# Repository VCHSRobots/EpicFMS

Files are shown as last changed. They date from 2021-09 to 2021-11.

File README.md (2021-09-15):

### The EPIC FMS 
**Sept 2021 EPIC Robotz**

This repository stores code that implements a field management system (FMS) for a simple game hosted by EPIC Robots. 

The game consists of robots shooting at various targets during a match. All targets have electronic sensors to detect hits.  The hits are counted at each target and then reported back to a central server, called the "EpicFMS server".  The EpicFMS server talleys the score and provides that information via MQTT and on a website that the EpicFMS hosts.  

The website that is hosted by EpciFMS server actually has two interfaces: the scoreboard and the game management interface.  The game management interface allows game administors to start, stop, reset the game.  Game parameters can also be set through the game management interface.

Finally, the EpicFMS server sends game status and commands back to the field elements -- mainly to control LEDs while the game is being played.

This repository contains all code and documentation for this system, including the code for the EpicFMS website, and the code for the electronics in the various targets. 

### Block Diagram
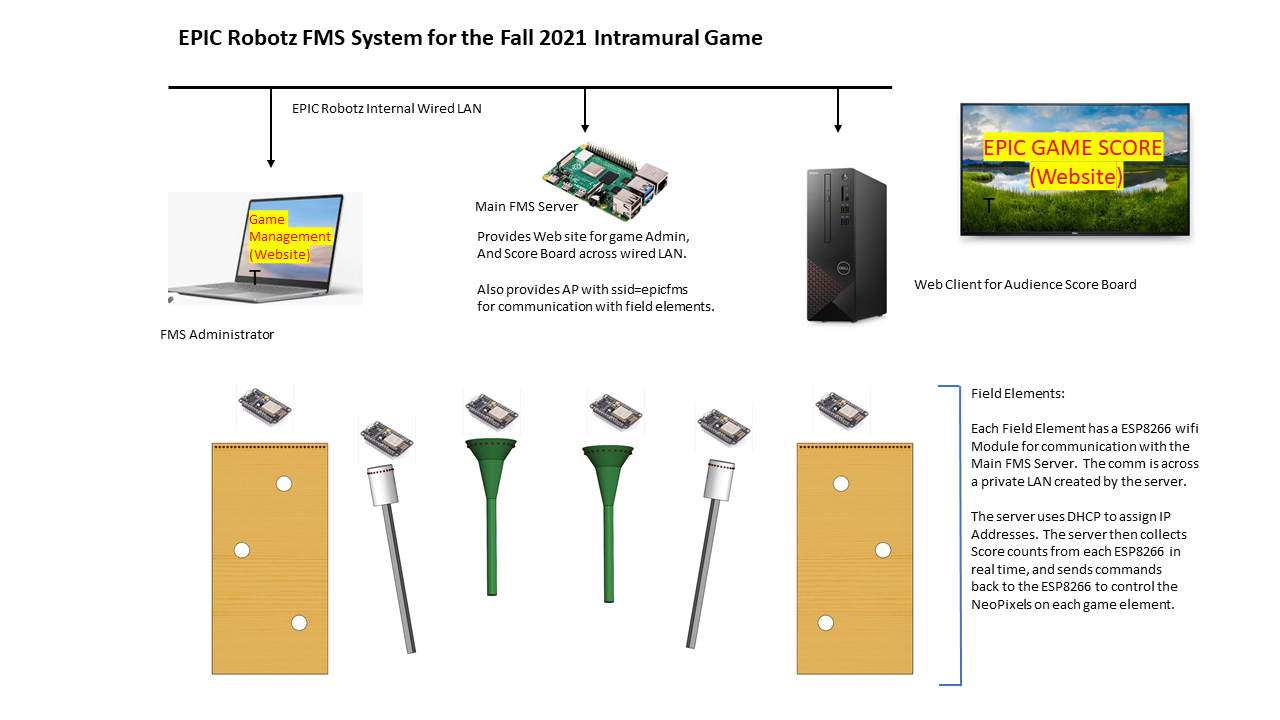
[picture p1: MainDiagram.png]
Cannot find it


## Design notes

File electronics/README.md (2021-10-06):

## Electronics for EpicFMS

This folder contains the data for the electronic components -- including
the custom PCB boards that were manufactured for the hit counters.

Note: Please see the MovingTargeUnit for the PCB -- This PCB is now
targeted to be used in all the targets.

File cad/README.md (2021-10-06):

## Epic FMS -- CAD Files

This repository stores the CAD files for the objects that have to do with electronics for the FMS.

Documentation and CAD files for the major game objects, on and off the field, are stored in EPIC's CAD Vault.

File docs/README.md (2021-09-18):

# EPIC FMS Documetation 

This folder contains notes and misc info that pertains to the EPIC FMS project.  

Some of this information is prepared in a power-point that is then 
converted to a PDF and the following PNG files:

### Wiring Diagram for Detection Test Circuit
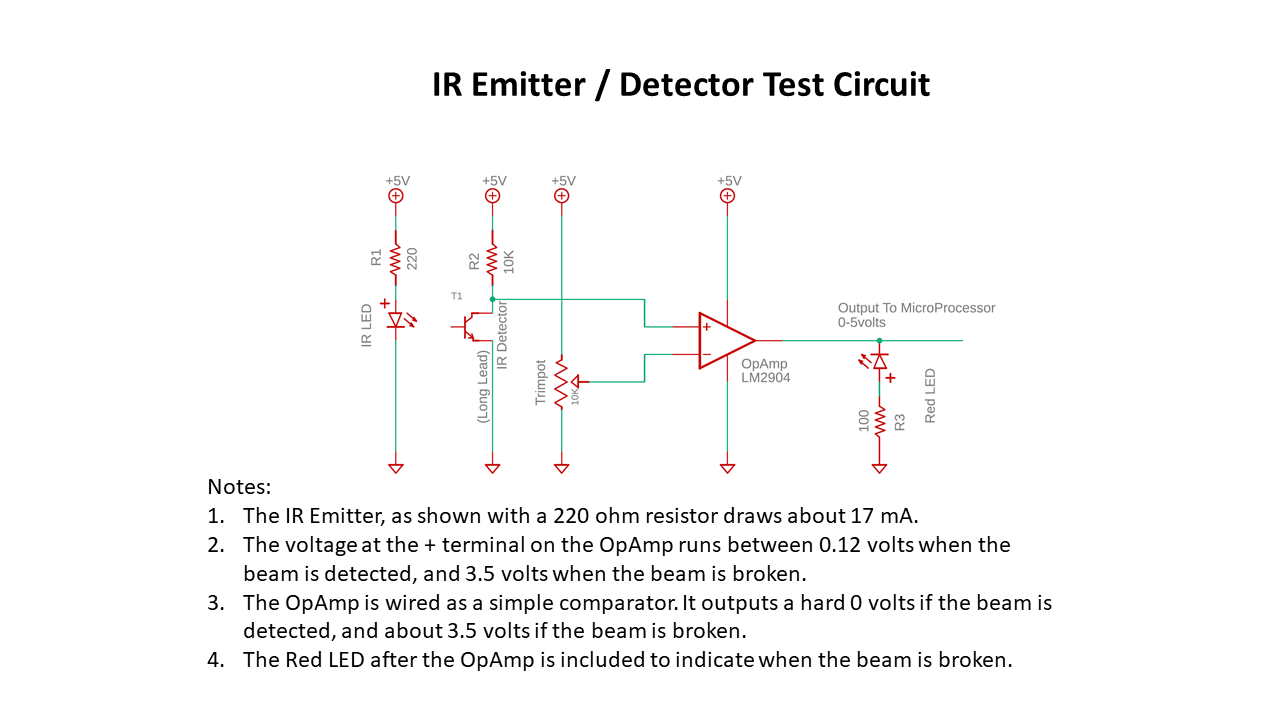
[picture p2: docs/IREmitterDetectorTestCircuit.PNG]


### Wiring for IR Emitter / Detector 
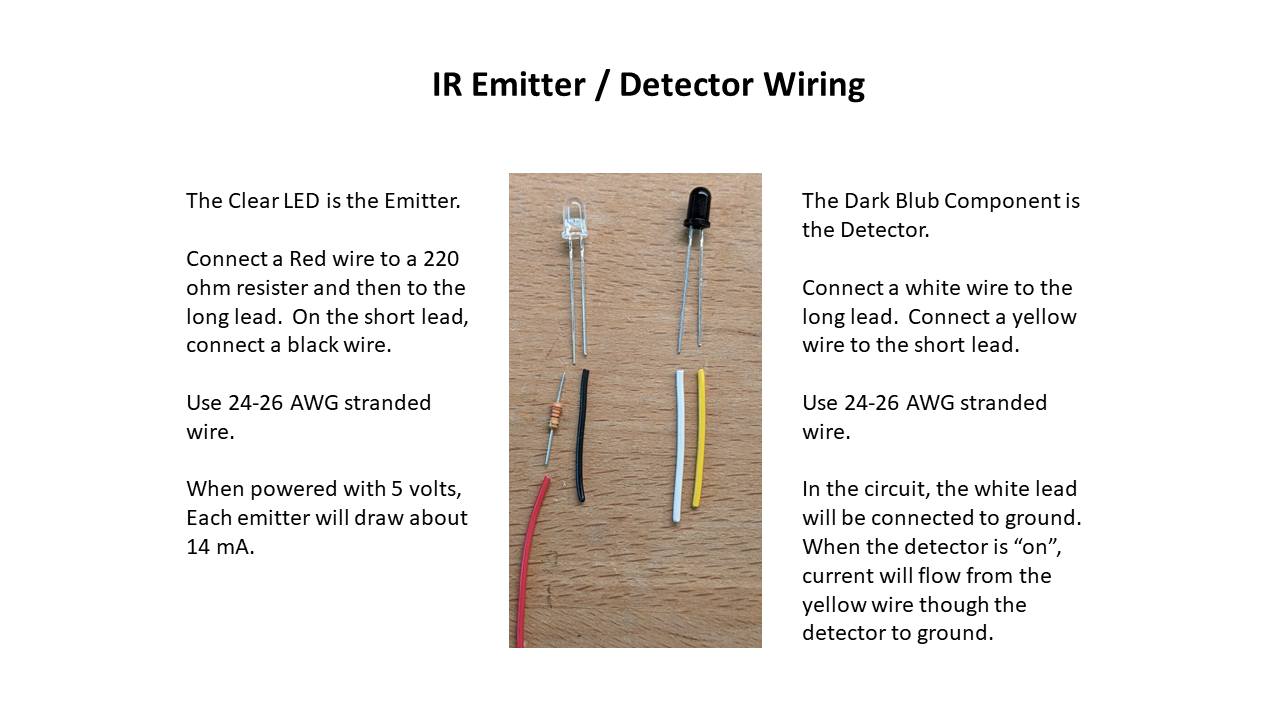
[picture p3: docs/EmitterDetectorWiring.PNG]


### Schematic For Hit Detector for Ring -- V1
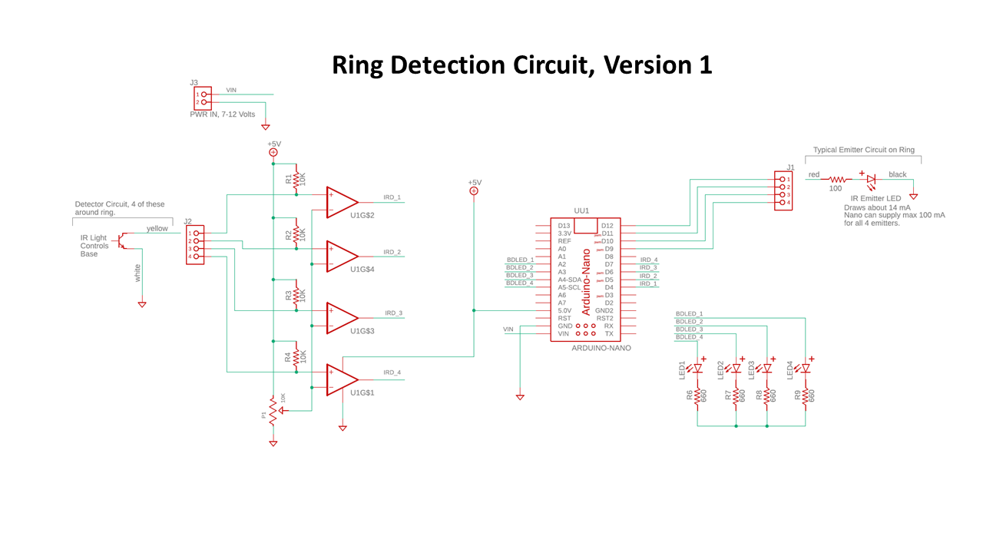
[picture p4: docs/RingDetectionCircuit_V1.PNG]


### Information Regarding Arduino Nano
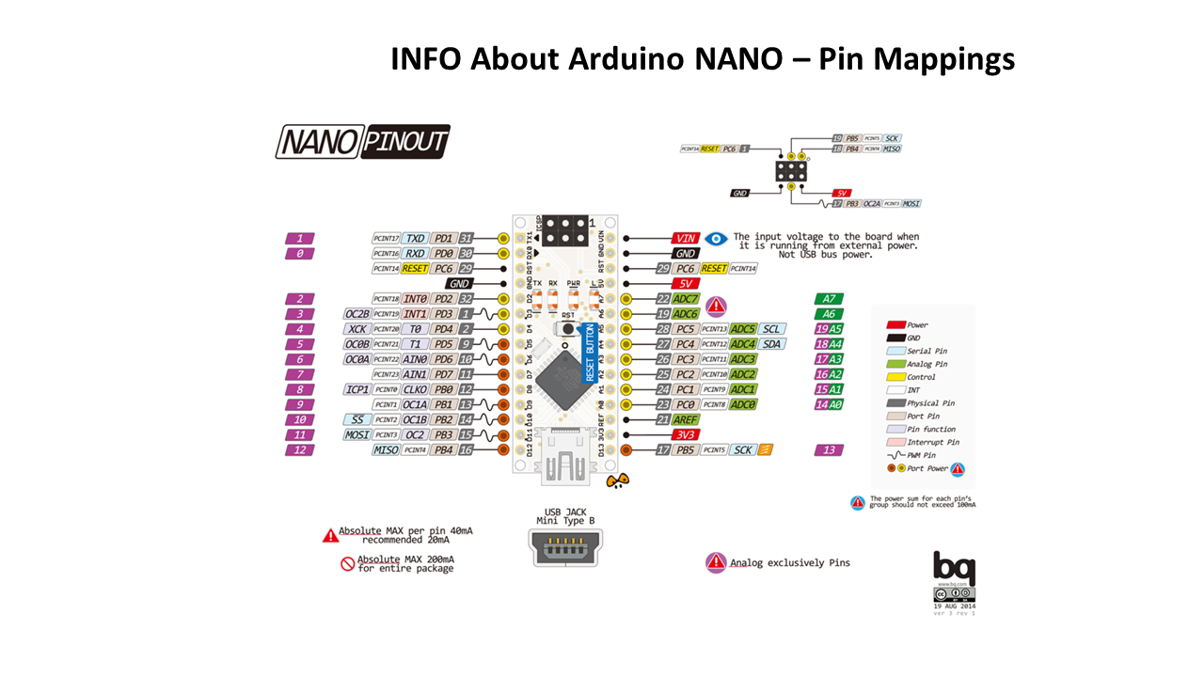
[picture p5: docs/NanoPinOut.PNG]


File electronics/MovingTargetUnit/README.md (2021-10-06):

### PCB for Moving Tareget Unit
**Oct 2021 EPIC Robotz**

As of 10/6/21, Two PCBs have been manufactured:

Verion 1:  Submitted for manufacturing on Friday, 9/24/21. Recived on 10/1/21.  This was based on V4 of the schematic.
Problems found:
1. Voltagle regulars overheat.  Since one of these powers sensors as well as neopixles, entire circult fails in about 2 minutes.
2. The outputs of the IR detectors are wired to pins that must be held in special conditions during startup -- this causes boot up problems.
3. The USB power flows back into the voltage regulators, causing confusion during developement.  Also, since USB power is tied directly
to input battery terminals, damage to a host computer might be possible during development.
4. The NEO pixels are driven directly from the ESP9266, at 3.3v.  It should be closer to 5v for reliable operation.

Verion 2: Submitted for manufacturing on Tuesday, 10/5/21.  This was based on V5 of the schematic. 
Hopefully, above problems fixed.

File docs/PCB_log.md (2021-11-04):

# EPIC Robotz -- EPIC FMS 
## PCB Log

This file contains notes about all the PCBs that have been built for the EPIC FMS.

There are two versions (as of 10/21/21) of the pcb board.  The schematics are V4 for the
first version, and V5 for the second.  A run of 15 pcbs for each was manufactured.  These
are referred to as V1 and V2 of the PCB.  (Confusing, I know. Sorry.)

V1 boards are really no good without lots of modifications.  V2 boards also needed modification,
as follows:

    * HITRST was cut from SD3 and rerouted to D0
    * IDR1 was cut from D10, and rerouted to SD3
    * IRD2 was cut from D9 and rerouted to D2, replacing NEO2.

So, for now on, a V2 board with the above mods is refered to as a V3 board.  So far all V2 boards have been converted, so we only have V1 boards and V3 boards.  Moreover, all V1 boards in use have been moded for use in the basket targets, so they are not really V1 boards.

10/29: Update on mods:  It has been found that HITRST to D0 causes problems. Since 
HITRST is a minor feature, this mod may not be found on many boards.

### Manufacturing Log

|SN | Date Made | BType | Okay |HS |Mods| Notes |How Used  |
|---|---|---|---|---|----| --- |---|
| A1 | Sept 21 | V1 | | | |Original, made by Mr.B | |
| A2 | Sept 21 | V1 |  No  | | |Made by Chris, cap blew up  | |
| A3 | Sept 21 | V1 | | | Y  |Many mods, For Basket | Retired  |
| 1 | 10/21/21  | V3 | | Y | |Runs pcb_test okay. | Mover |
| 2 | 10/21/21  | V3 |  No  | | |Runs pcb_test okay. | | 
| 3 | 10/21/21  | V3 | | | |Runs pcb_test okay. | Slider |
| 4 | 10/21/21  | V3 | | Y | |Runs pcb_test okay. | Mover |
| 5 | 10/21/21  | V3 | | | |Bad Mod, now okay. | Slider |
| 6 | 10/21/21  | V3 | | Y | |Runs pcb_test okay. | |
| 7 | 10/21/21  | V3 | | | |Works on Slider Ring. | Slider |
| 8 | 10/21/21  | V3 | | | |Works on Slider Ring. | Slider |
| 9 | 10/21/21  | V3 | | Y | |Works on Slider Ring. | Slider |
| 10 | 10/21/21  | V3 | | | |Works on Slider Ring. | |
| 11 | 10/21/21  | V3 |  No  | Y | |Fails test. Gets really hot.| |
| 12 | 10/21/21  | V3 |  No  | | |** See notes below | |
| 13 | 10/21/21  | V3 | | | |Fixed with Paul's Help | Slider |
| 14 | 10/21/21  | V3/B  | | | B  |Moded for Basket | Basket |
| 15 | 10/21/21  | V3/B  | | | B  |Fixed for Basket | Basket |

HS=HeatSink

### Address Assignements

|Board  |Name |Mac |IP Addr |How Used |
|---|---|---|---|---|
|PCB-A3 | |BC:FF:4D:2B:AD:82 |10.0.2.60  | |  
|PCB-01 |Mover-1 |30:83:98:B6:34:A1 |10.0.2.71  | Mover |  
|PCB-03 |Slider-1 |8C:CE:4E:E3:42:36 |10.0.2.73  | Slider  |  
|PCB-04 |Mover-2 |A8:48:FA:C0:81:A7 |10.0.2.74  | Mover |  
|PCB-05 |Slider-2 |30:83:98:B5:5D:FF |10.0.2.75  | Slider  |  
|PCB-07 |Slider-3 |BC:FF:4D:2B:A7:02 |10.0.2.77  | Slider  | 
|PCB-08 |Slider-6 |BC:FF:4D:2B:4B:14 |10.0.0.78  | Slider  |
|PCB-09 |Slider-5 |BC:FF:4D:2B:36:0B |10.0.2.79  | Slider  |  
|PCB-13 |Slider-4 |BC:FF:4D:2A:EB:3D |10.0.2.83  | Slider  |  
|PCB-14 |Basket-1 |BC:FF:4D:2B:AA:ED |10.0.2.84  | Basket  |  
|PCB-15 |Basket-2 |BC:FF:4D:2A:D6:E8 |10.0.2.85  | Basket  |  

IP addresses are fixed to MAC addresses and assigned by the LinkSys router,
via DHCP. The scheme is to tie address to Board SN, the V1 boards (A series) start 
at 10.0.0.60, and the V3 boards start at 10.0.2.71.  

The above scheme is not strickly necessary, but helps with the 
default assignments in the Epic FMS web server.

### Work Log

Work on Tuesday, 10/26:
PCB-2 was in first Ring, working great.  Working on second ring
and hooked it up to PCB-2. PCB-2 got really hot.  After cooling, one of
the IR beams will not work.  It still connects, but suppected burnout
on GPIO pins.

PCB-5 was also used on bad ring.  It will connect, but will not
work with the IR Beams.  Suppected burnout on GPIO pins.

Work on Thrusday, 10/28:
PCB-5 was misswired, a bad mod. Fixed the mod, and PCB-5 now okay.
Also, resodered PCB-13, works now.  And finshed PCB-12 with new ESP, and
something seems to be wrong... Set aside for debugging later.

Work on Monday, 11/1
PCB-12 was seemed okay at first, but then it wouldn't read one
of the ir beams on a ring.  Later, it will connect to a PC but
it won't accept an upload.

After more work with the test jig, I discovered that there is
cross-talk among the beams.  I tested PCB-6, PCB-8, PCB-9 and
PCB-10 on slider rings -- and they all work.  Before, PCB-8, PCB-9,
and PCB-10 failed the test on the test jig.  Now, I think, however, 
they failed becuase of HITRST -- see below. 

Work on Monday-Wednesday, 11/1-3
Built two more PCBs, 14 & 15. Discovered that HITRST, on SD3/G10
cannot be used reliable.  Casuses some sort of hardware watch dog
reset.

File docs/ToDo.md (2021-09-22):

# To Do List
    
## To Do list for Epic Robotz, Fall 2021 Intramural Game

    GI = Game Innovator
    
    Legend:  x = Item Finished, s = Item Started.

1. Overall Game Design
- 1a. [s] Codify the scoring in a document
- 1b. [ ] Create schedule for things like sliding doors, LED lights, countdown, etc
- 1c. [ ] Include schedule in game doc, and distribute to teams
- 1d. [ ] Design color schemes for targets, lines on floor, game panels
- 1e. [ ] Design LED flashing patterns for various game states
- 1f. [ ] Design algorithms to control assignments of auto path

2. EPIC FMS Server
- 2a. [x] Get Raspberry 4 Running as an AP device
- 2b. [ ] Install a web server on it.
- 2c. [s] Write code to test connections with game elements
- 2d. [ ] Decide on lang and tools to use
- 2e. [ ] Design, write game control program
- 2f. [ ] Design and implement the score board page
- 2g. [ ] Design and implement the admin interface
- 2h. [ ] Test 

3. Moving Target
- 3a. [x] Get initial design done
- 3b. [s] Finish electronic design
- 3c. [s] Initial coding and test
- 3d. [ ] Submit circuit board (PCB) for manufacturing
- 3e. [ ] Solidworks Parts/Design for team use
- 3f. [ ] CNC parts for team use
- 3g. [ ] Soldering, asm of final target
- 3h. [ ] Final coding and Testing

4. Sliding Target
- 4a. [x] Finish initial design done
- 4b. [ ] Design Control Box Mechanics
- 4c. [s] Design Control Box Electronics
- 4d. [ ] Assemble the electronics
- 4e. [ ] Paint the targets
- 4f. [ ] Install electrical components on targets
- 4g. [ ] Test

5. Basket Target
- 5a. [s] Finish initial design done
- 5b. [ ] Work with Paul on Motor controller for blender
- 5c. [s] Design Control Box Electronics for hit count
- 5d. [ ] Assemble the electronics
- 5e. [ ] Install electrical components on targets
- 5f. [ ] Test

6. 3D Printing
- 6a. [ ] Print 3 More Mobile Targets (2 days each)
- 6b. [ ] Print 6 More Sliding Door Targets (1 day each)
- 6c. [ ] Print yet-to-be designed parts for Basket Target Counters

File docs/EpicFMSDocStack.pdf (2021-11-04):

# EPIC FMS

## A Field Management System (FMS) for the Fall Game

## Epic Robotz Fall 2021

This stack contains useful info about various parts of EpicFMS.

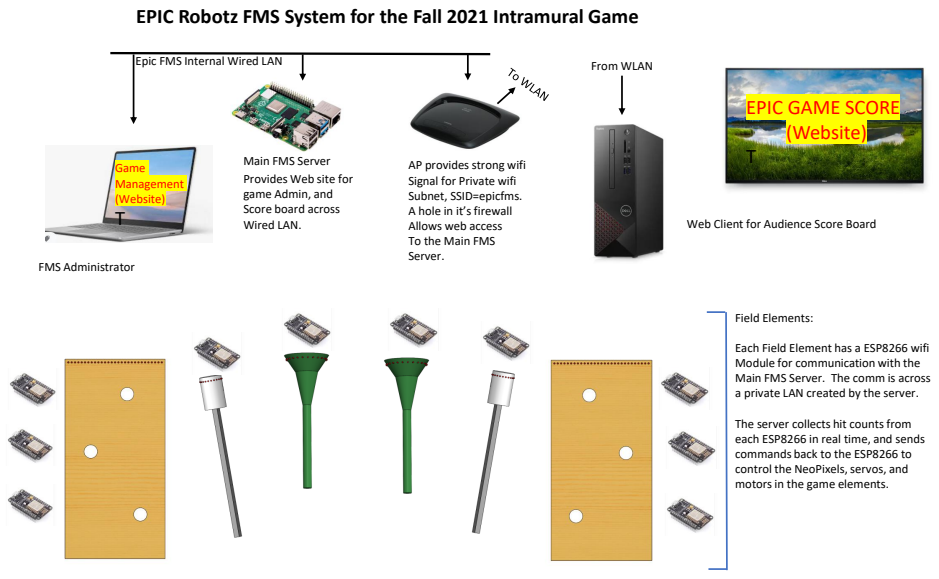
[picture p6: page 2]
FMS Administrator; Game Management (Website) T; Field Elements:; EPIC GAME SCORE (Website); From WLAN

EPIC Robotz FMS System for the Fall 2021 Intramural Game

Epic FMS Internal Wired LAN

Main FMS Server
Provides Web site for
game Admin, and
Score board across
Wired LAN.

AP provides strong wifi
Signal for Private wifi
Subnet, SSID=epicfms.
A hole in it’s firewall
Allows web access
To the Main FMS
Server.

Web Client for Audience Score Board

Each Field Element has a ESP8266 wifi
Module for communication with the
Main FMS Server. The comm is across
a private LAN created by the server.

The server collects hit counts from
each ESP8266 in real time, and sends
commands back to the ESP8266 to
control the NeoPixels, servos, and
motors in the game elements.

## Overview of Electronics for Field Elements

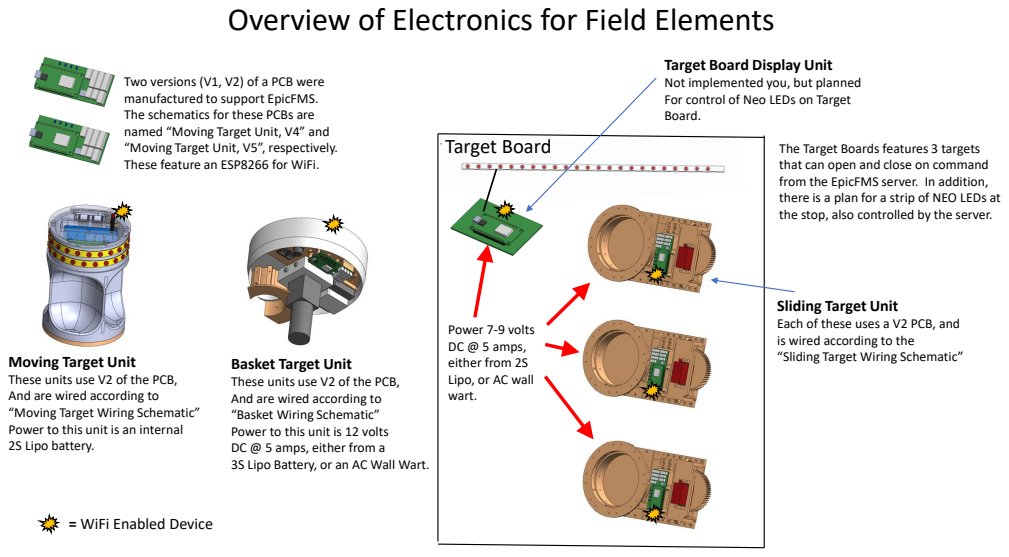
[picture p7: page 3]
Target Board; The Target Boards features 3 targets

Target Board Display Unit
Not implemented you, but planned
For control of Neo LEDs on Target
Board.

Two versions (V1, V2) of a PCB were
manufactured to support EpicFMS.
The schematics for these PCBs are
named “Moving Target Unit, V4” and
“Moving Target Unit, V5”, respectively.
These feature an ESP8266 for WiFi.

that can open and close on command
from the EpicFMS server. In addition,
there is a plan for a strip of NEO LEDs at
the stop, also controlled by the server.

Sliding Target Unit
Each of these uses a V2 PCB, and
is wired according to the
“Sliding Target Wiring Schematic”

Power 7-9 volts
DC @ 5 amps,
either from 2S
Lipo, or AC wall
wart.

Moving Target Unit
These units use V2 of the PCB,
And are wired according to
“Moving Target Wiring Schematic”
Power to this unit is an internal
2S Lipo battery.

Basket Target Unit
“Basket Wiring Schematic”
Power to this unit is 12 volts
DC @ 5 amps, either from a
3S Lipo Battery, or an AC Wall Wart.

= WiFi Enabled Device

## PCB Schematic, V1

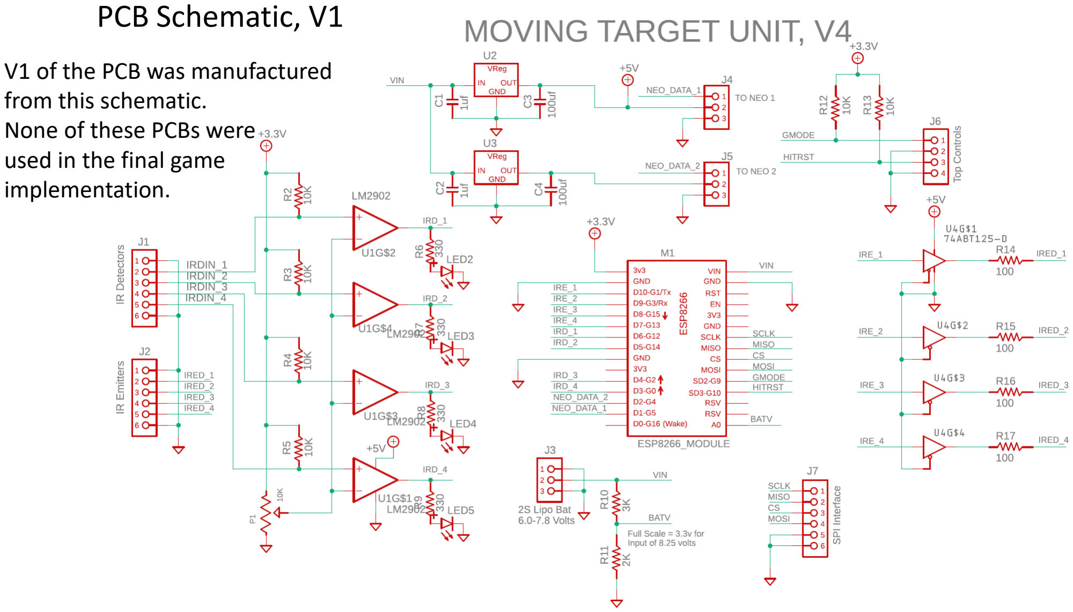
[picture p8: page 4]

V1 of the PCB was manufactured from this schematic.
None of these PCBs were
used in the final game
implementation.

## PCB Schematic, V2

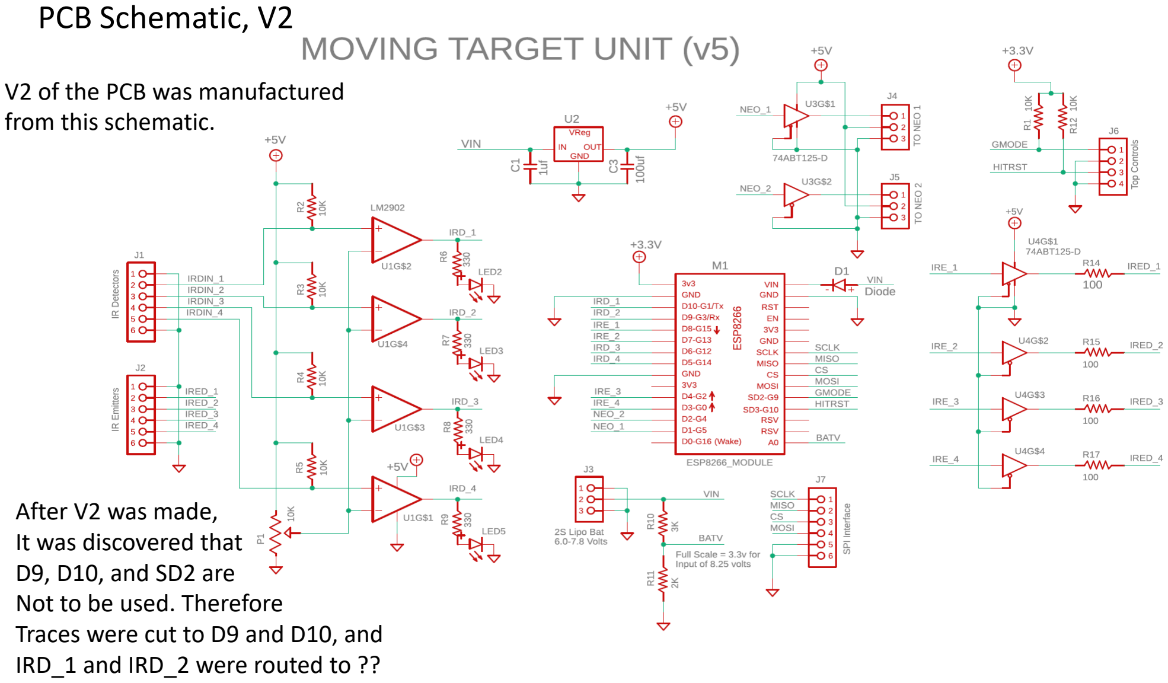
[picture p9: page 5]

V2 of the PCB was manufactured from this schematic.

After V2 was made,
It was discovered that
D9, D10, and SD2 are
Not to be used. Therefore
Traces were cut to D9 and D10, and IRD_1 and IRD_2 were routed to ??

## PCB Schematic, V3

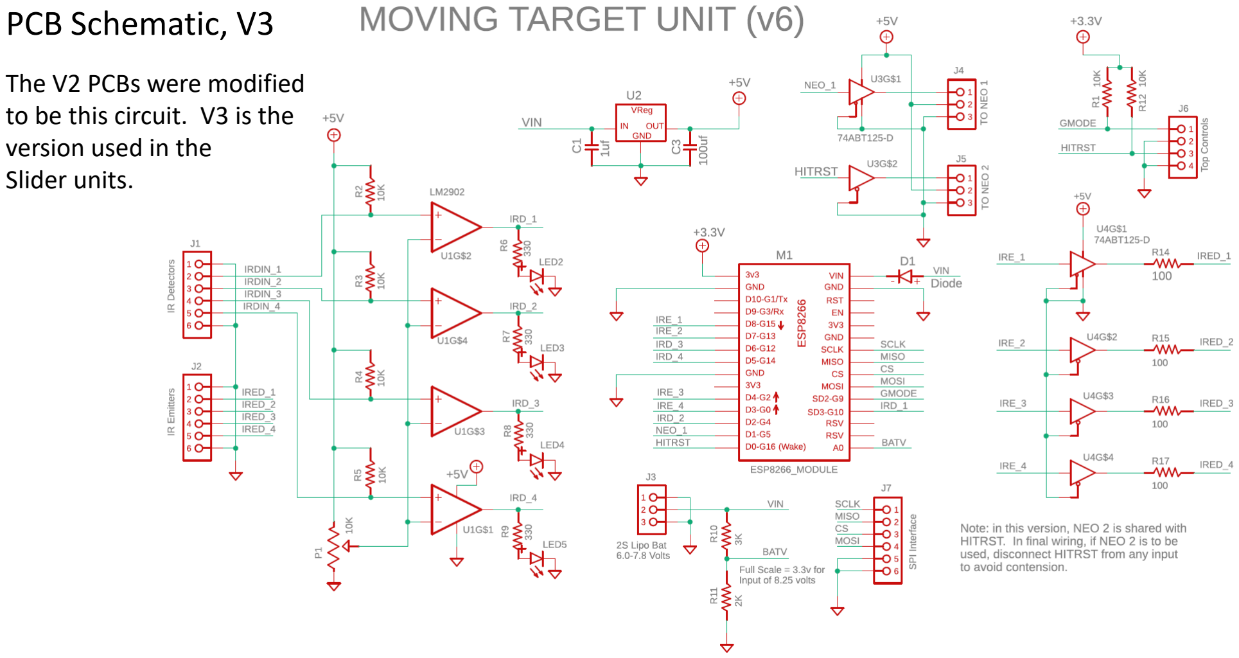
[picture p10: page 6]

The V2 PCBs were modified
to be this circuit. V3 is the version used in the
Slider units.

## Sliding Target Wiring Schematic

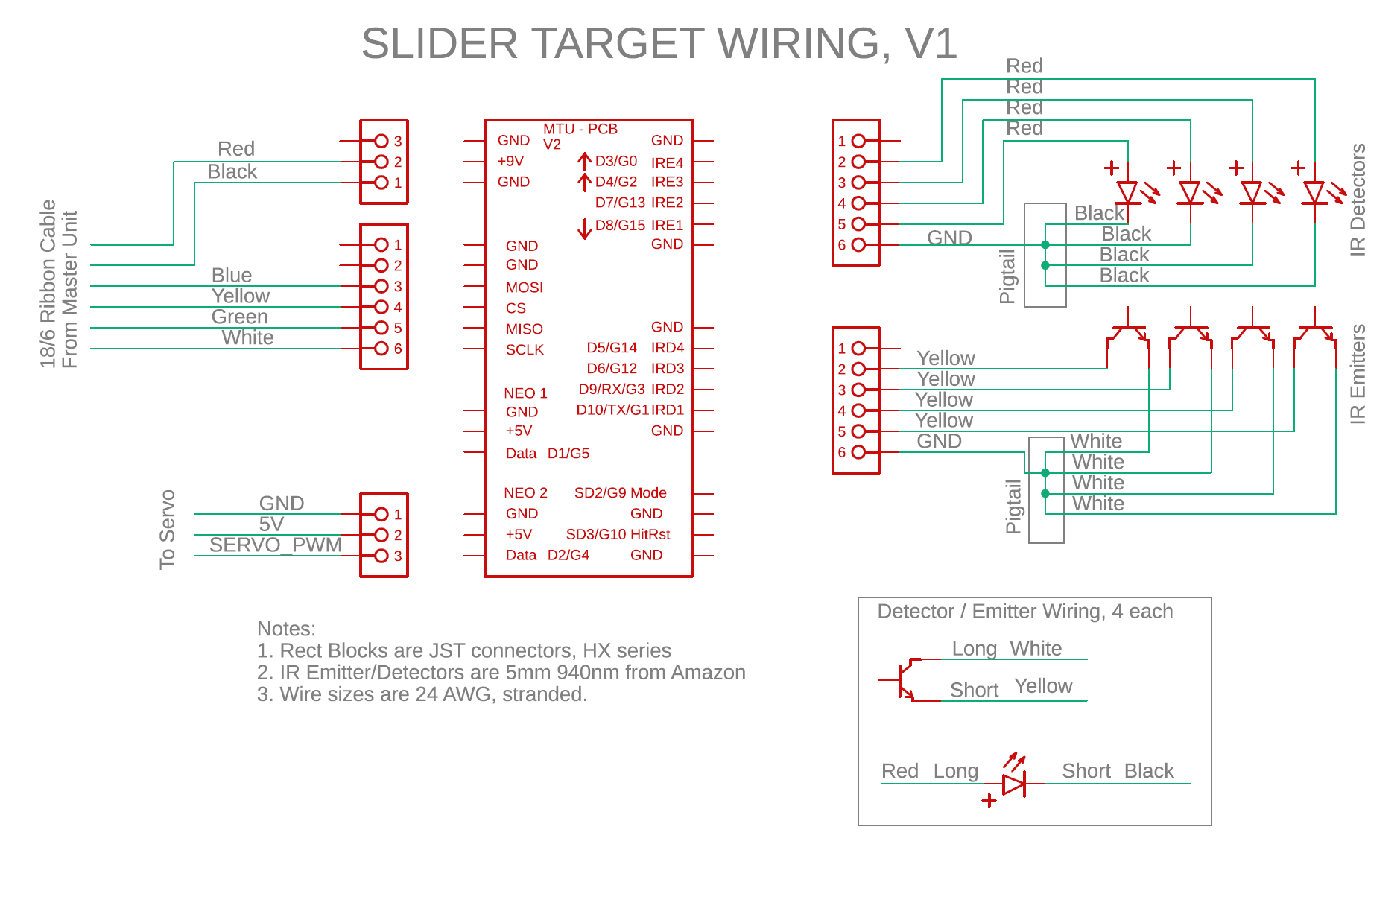
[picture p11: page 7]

## Basket Target Wiring, Version Based on V2/3 of PCB

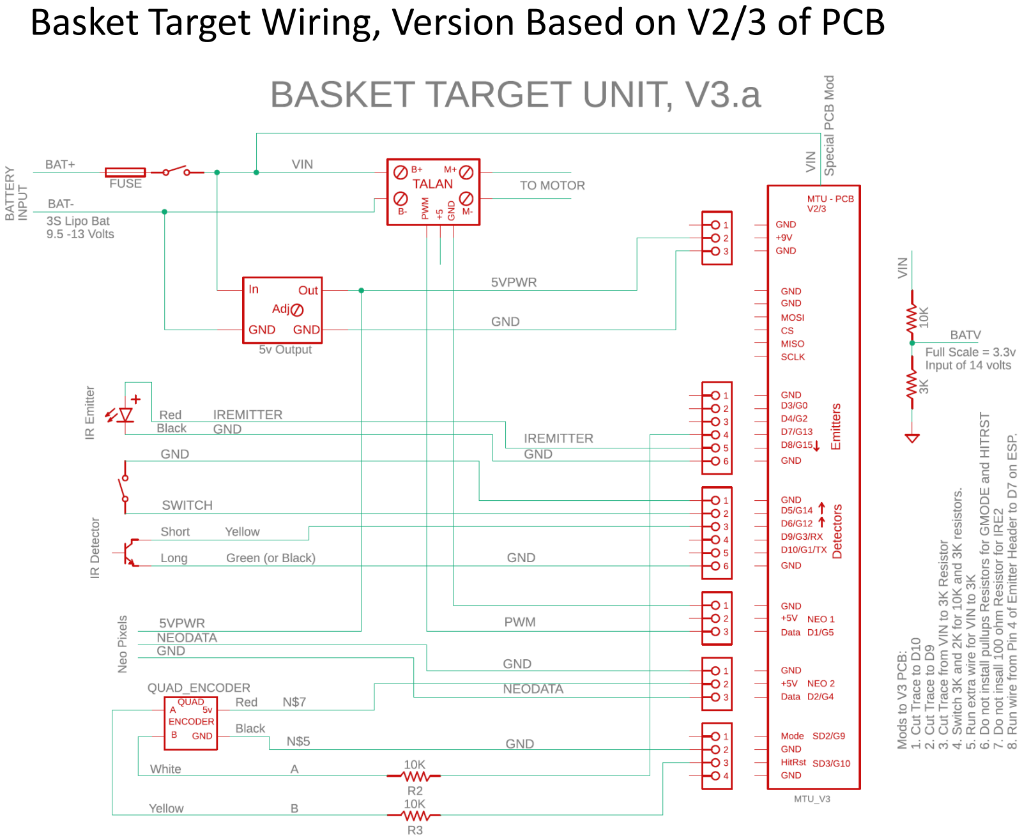
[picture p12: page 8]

Coming Soon, I Hope.

KNOWN Issues with the EPS8266

What as been learned through experimenting and study:

1. DO NOT USE the "D" numbers such as D0, D1, etc when specifying pins.
2. Pins seem to always be specified with the G numbers.
3. If you want a serial port to upload code and debug,
DO NOT USE D9 and D10 for any circuitry.
4. D0/G16 is connected to the on-board LED.
5. D0/G16 cannot be used for PWM or Interrupts!
6. D0/G16 cannot be used for NEO pixels!
7. D0/G16 can be used to turn on/off a simple LED
8. D1, D2, D3, D4, D5, D6, D7, D8, and SD3 all work with interrupts.
9. Startup problems and upload problems are likely if you use D0.
10. On some boards, using SD2 causes the hardware WDT to trigger,
so it cannot be used either.
11. On boot, MANY GPIO are asserted high: D0/G16, D9/G3/RX, SD3/G10, SD2/G9, D4/G2, D10/G1/TX. If any of these pins are forced low at boot time, there will be problems.
12. Also, on boot, D8 most NOT be pulled HIGH. D8 has a pulldown resister to hold it low at boot.

## MOVEING TARGET CIRCUIT BOARD CONNECTORS

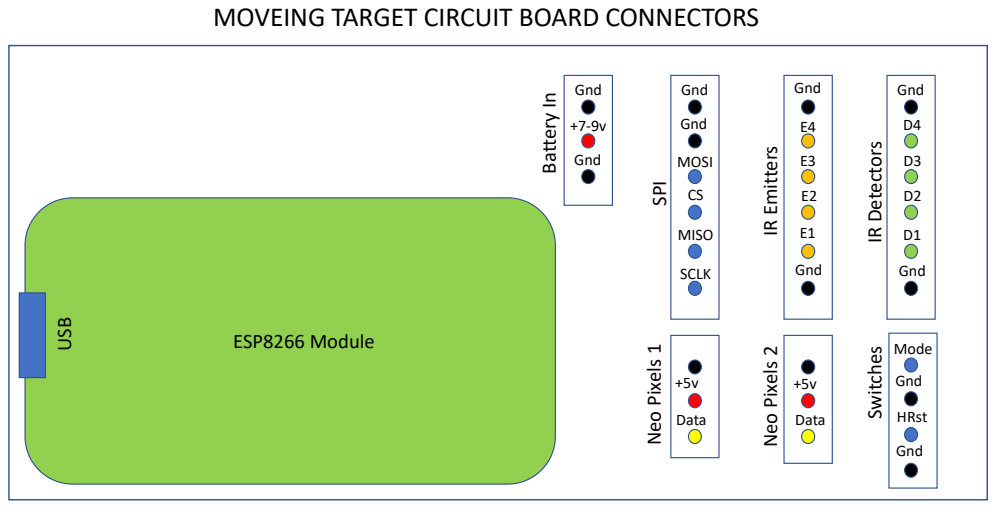
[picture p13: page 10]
Battery In; SPI; IR Emitters; Neo Pixels 1; Neo Pixels 2; Mode; Data; HRst; Gnd; MOSI; MISO; SCLK; USB; ESP8266 Module

IR Detectors Switches

# Wiring IR Emitter/Detectors

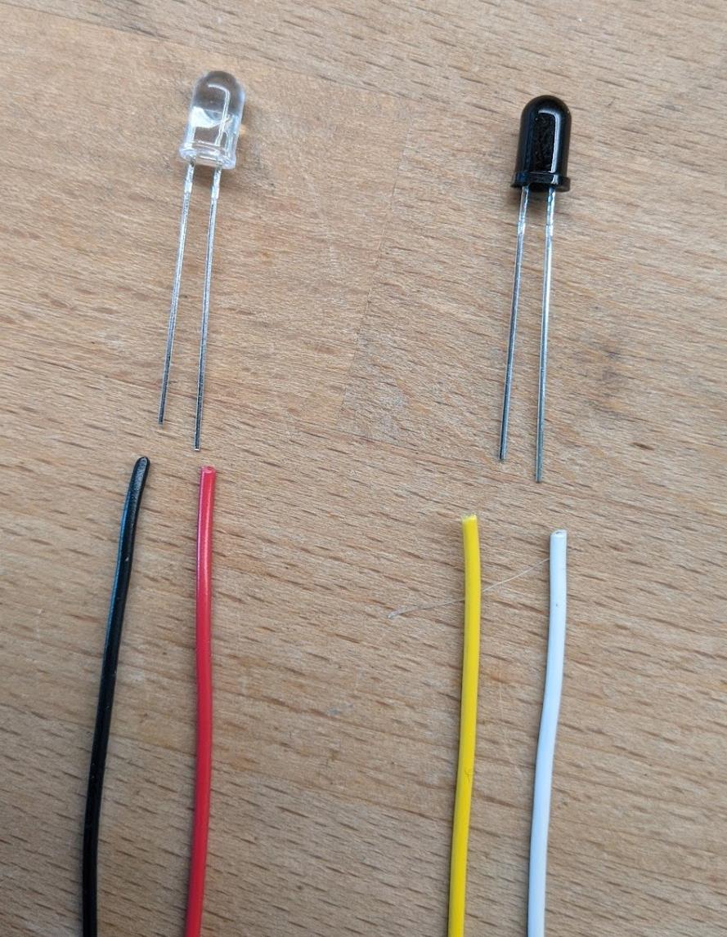
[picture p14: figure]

The CLEAR LED is the Emitter.

Our circuit sends about 17ma of current through this device.

The RED wire carries positive voltage and must be connected to the LONG lead.

The BLACK wire should be
connected to the SHORT lead.

Use 24-26 AWG stranded wire.

The Dark Component is the Detector.

When it detects IR light, it allows
current to flow between it’s leads, but in only one direction: from the short lead to the long lead.

The YELLOW wire is the positive side and Must be connected to the SHORT lead.

The WHITE wire is the negative side and Must be connected to the LONG lead.

Steps to Solder Wires to the IR Components

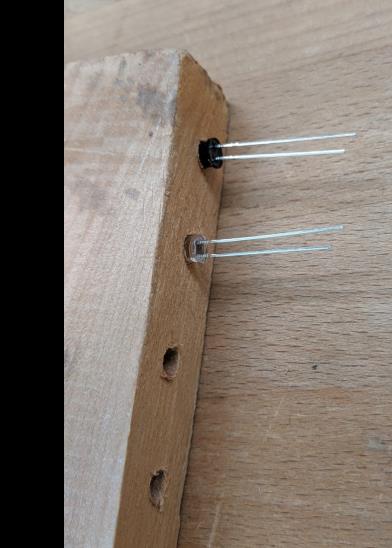
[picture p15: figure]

Start with the components in the soldering jig with the long leads nearer the top of the jig.

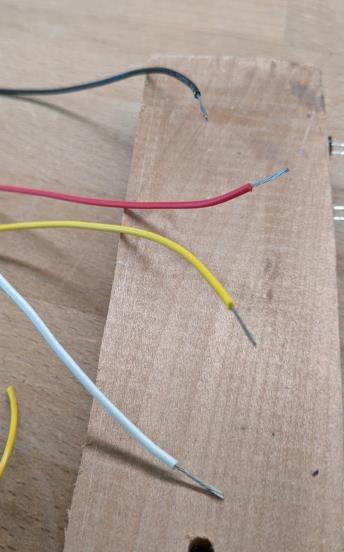
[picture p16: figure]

Strip about 0.5 inch of
insulation from each wire.

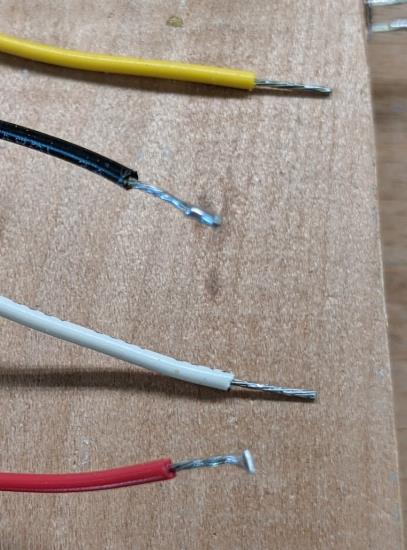
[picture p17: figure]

Tin all wires and leads.
Then trim the wires so that there is about 3/8 inch of conductor showing.

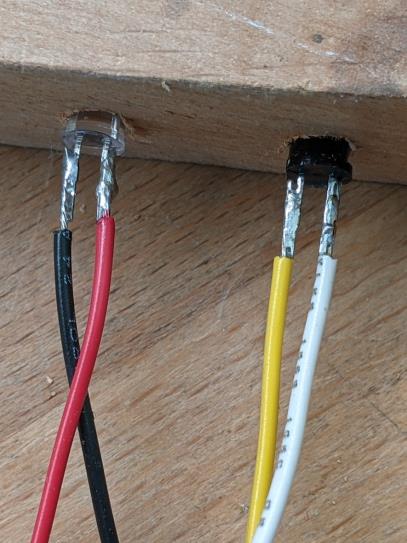
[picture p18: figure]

Do the same for the long
leads.

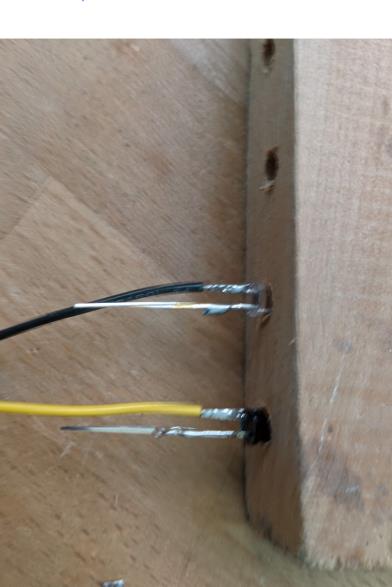
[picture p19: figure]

Cut the short leads to
about 3/8 inch. And then
use the parallel solder
technique to solder the
wires.

Parallel solder technique: After tinning both wire and lead, bring the wire along side of the lead (i.e., parallel to it), and then heat both with the soldering iron at the same time. Allow the solder to flow between the lead and the wire while holding the wire very steady. Remove the soldering iron while keeping the wire absolutely still until the solder cools.

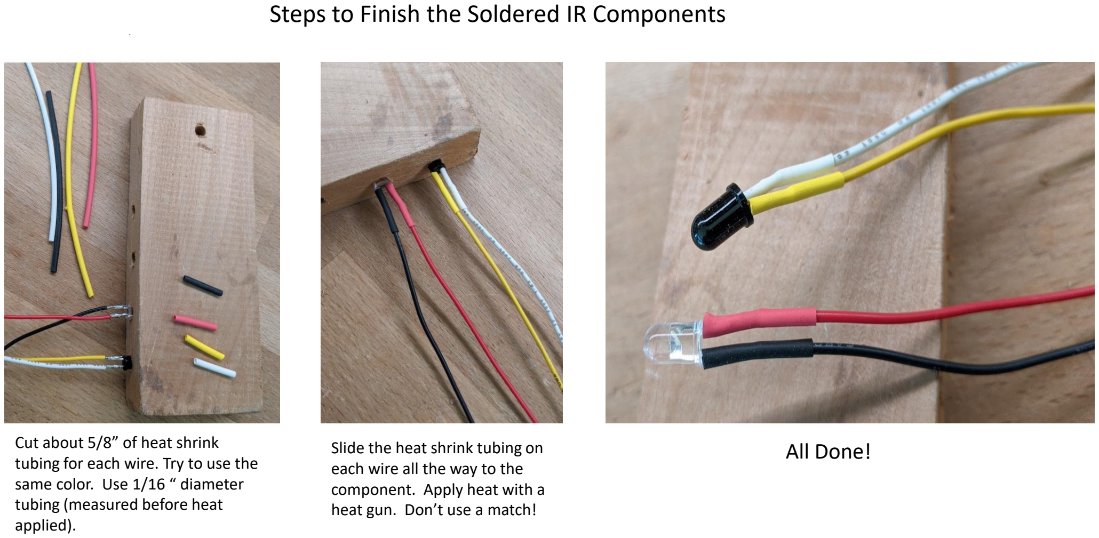
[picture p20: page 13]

Steps to Finish the Soldered IR Components

Cut about 5/8” of heat shrink tubing for each wire. Try to use the same color. Use 1/16 “ diameter tubing (measured before heat applied).

Slide the heat shrink tubing on each wire all the way to the component. Apply heat with a heat gun. Don’t use a match!

All Done!

## IR Emitter / Detector Test Circuit

Notes:

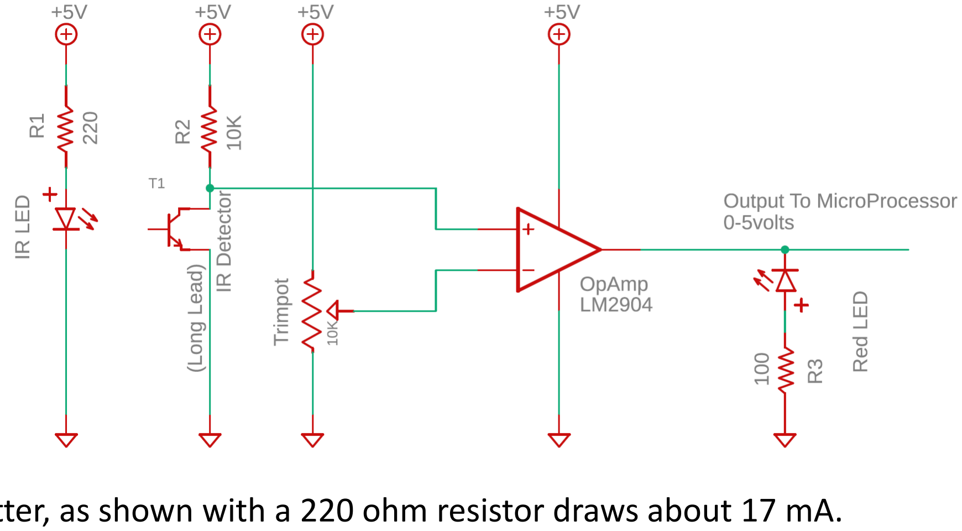
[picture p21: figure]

1. The IR Emitter, as shown with a 220 ohm resistor draws about 17 mA.
2. The voltage at the + terminal on the OpAmp runs between 0.12 volts when the beam is detected, and 3.5 volts when the beam is broken.
3. The OpAmp is wired as a simple comparator. It outputs a hard 0 volts if the beam is detected, and about 3.5 volts if the beam is broken.
4. The Red LED after the OpAmp is included to indicate when the beam is broken.

## IR Emitter / Detector Wiring

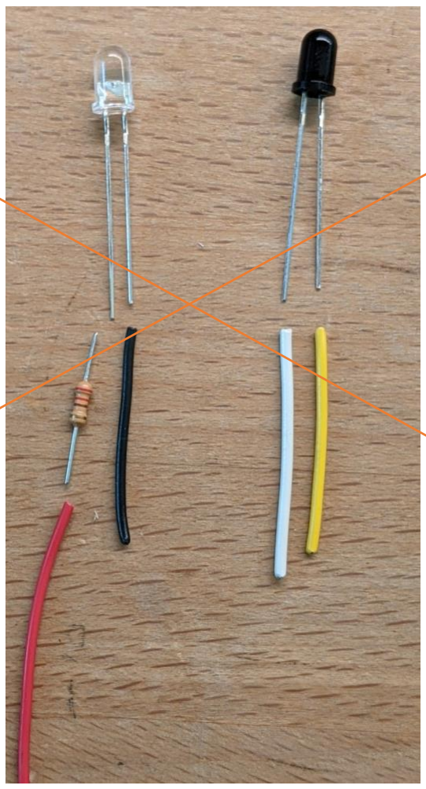
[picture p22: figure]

The Clear LED is the Emitter.

Connect a Red wire to a 220 ohm resister and then to the long lead. On the short lead, connect a black wire.

Use 24-26 AWG stranded
wire.

When powered with 5 volts, Each emitter will draw about 14 mA.

The Dark Blub Component is the Detector.

Connect a white wire to the long lead. Connect a yellow wire to the short lead.

Use 24-26 AWG stranded
wire.

In the circuit, the white lead will be connected to ground. When the detector is “on”, current will flow from the yellow wire though the
detector to ground.

OBSOLETE!! Design Changed.

## Ring Detection Circuit, Version 1

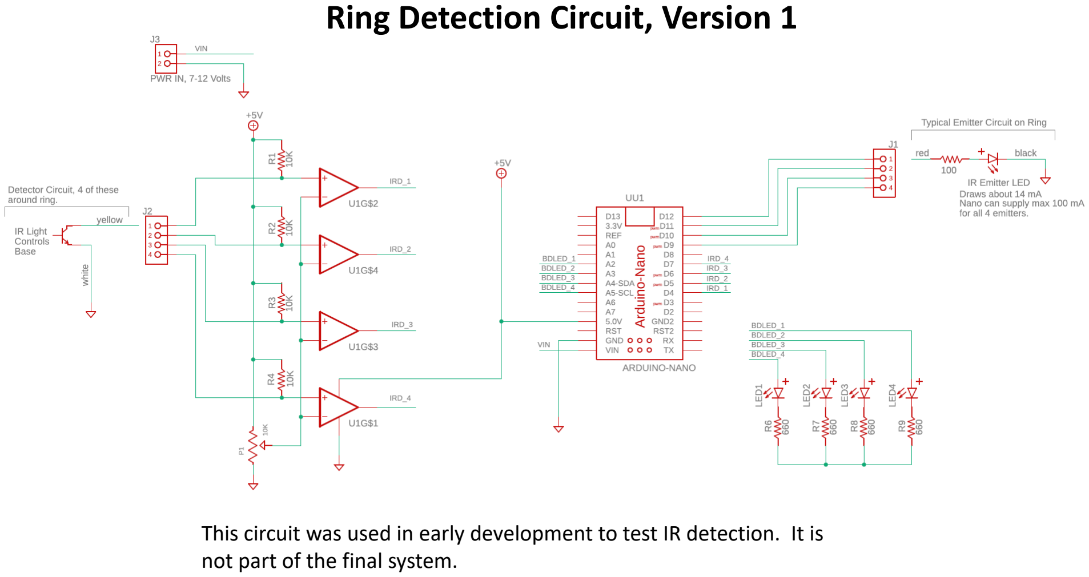
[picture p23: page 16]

This circuit was used in early development to test IR detection. It is not part of the final system.

## Pinout for nodeMCU

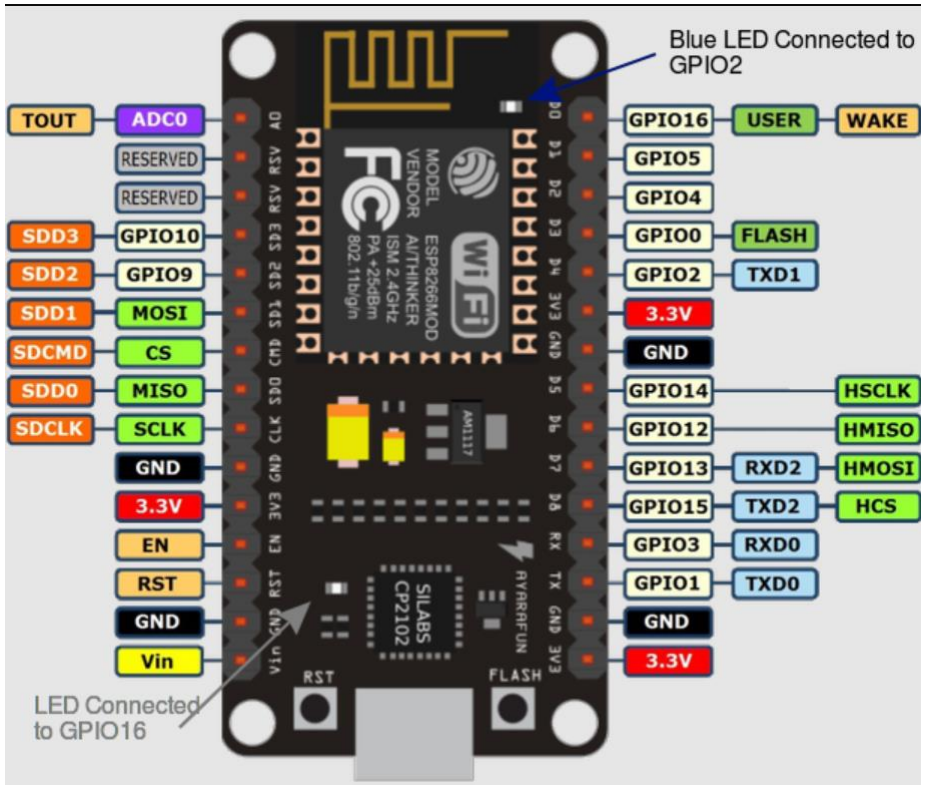
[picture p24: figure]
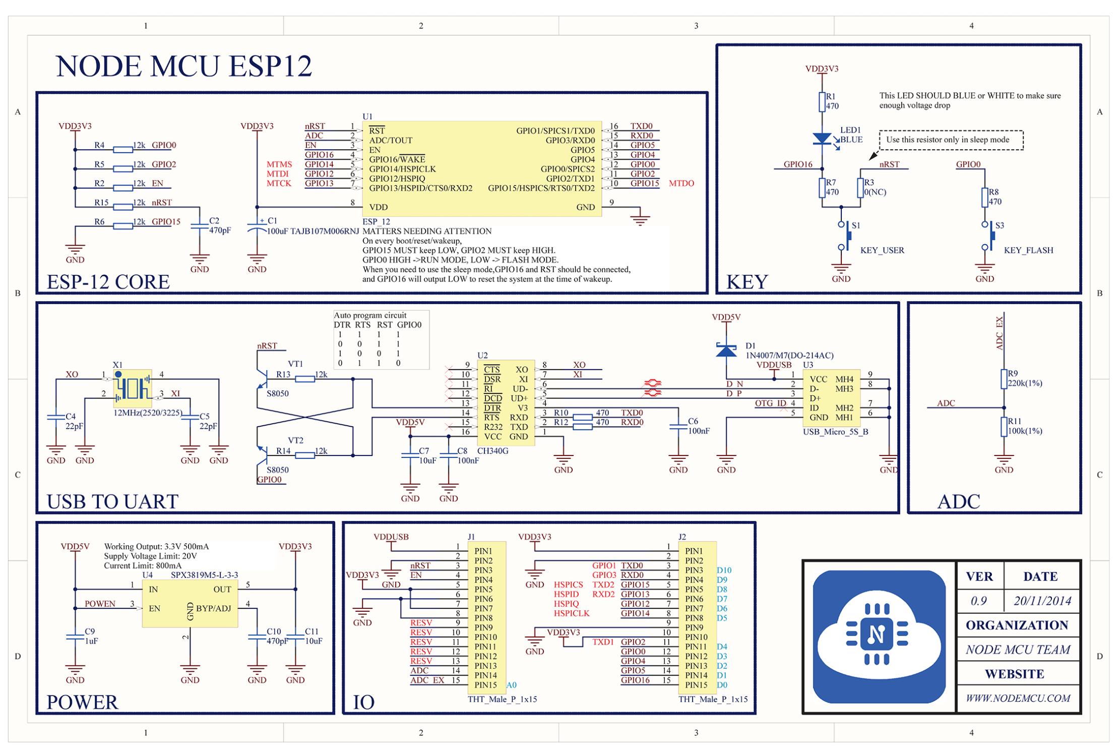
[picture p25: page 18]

## INFO About Arduino NANO – Pin Mappings


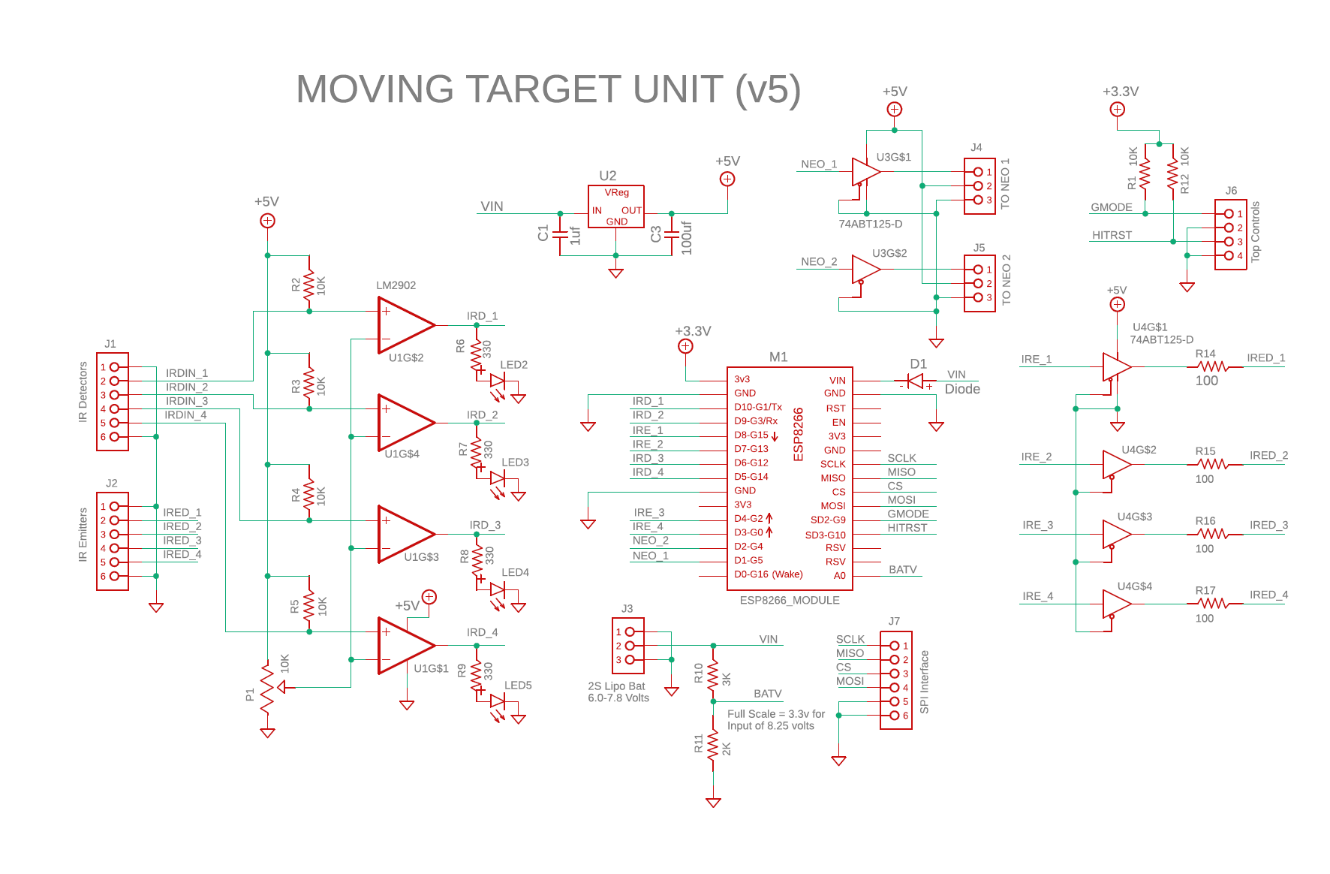
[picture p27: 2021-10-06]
electronics/MovingTargetUnit/v2/MovingTargetUnit_v5.png

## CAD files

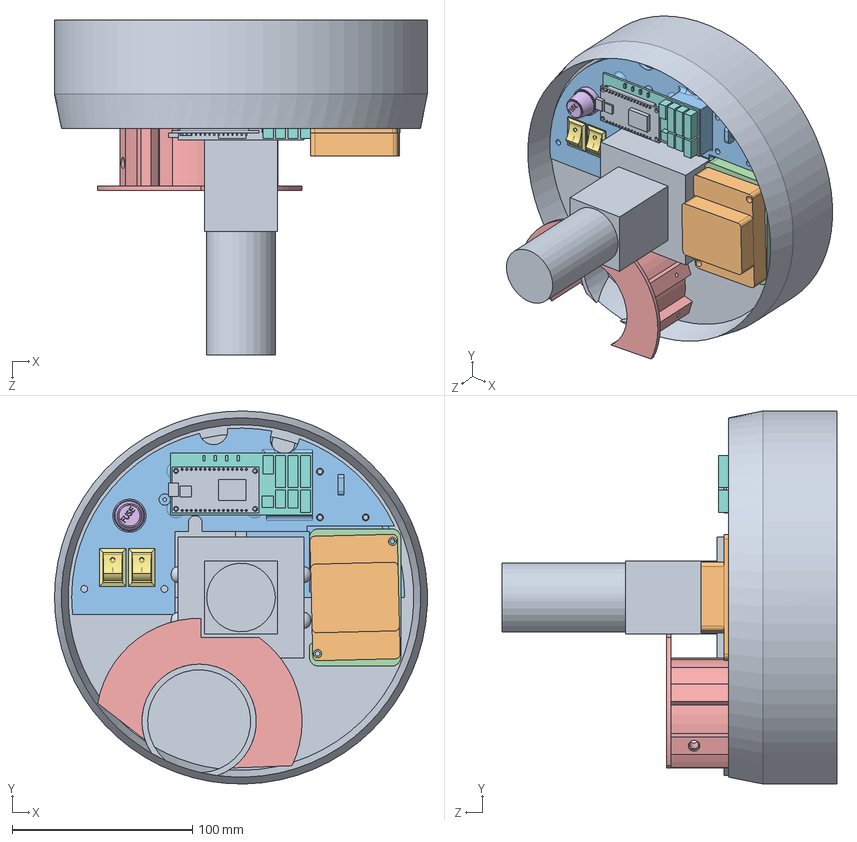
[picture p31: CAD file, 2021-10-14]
cad/BasketTarget/M21-HG-0001.SLDASM
207.0 x 207.0 x 186.1 mm
M21-HG-7001
M21-HG-7002
M21-HG-3001
M21-HG-3002
M21-HG-3003
PanelMountFuse
SmallRockerSwitch x 2
M21-GP-7001
ESP8266
DCtoDC_Convertor_2Amp

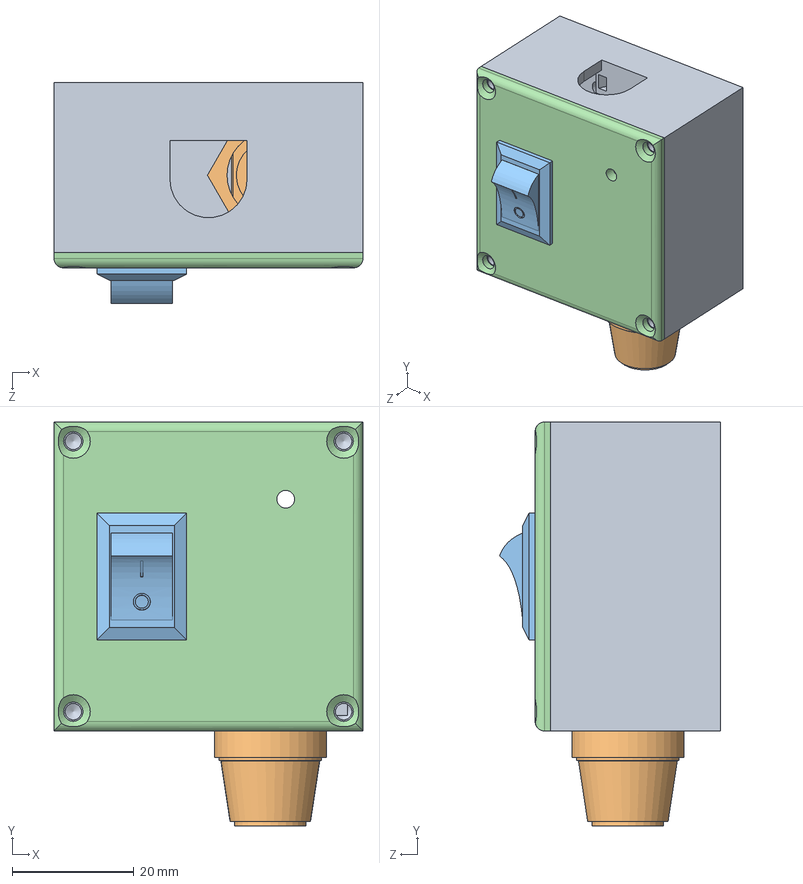
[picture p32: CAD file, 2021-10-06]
cad/FuseSwitchBox/M21-GP-0001.SLDASM
50.8 x 66.4 x 36.3 mm
M21-GP-3003
PanelMountFuse
SmallRockerSwitch
M21-GP-3004

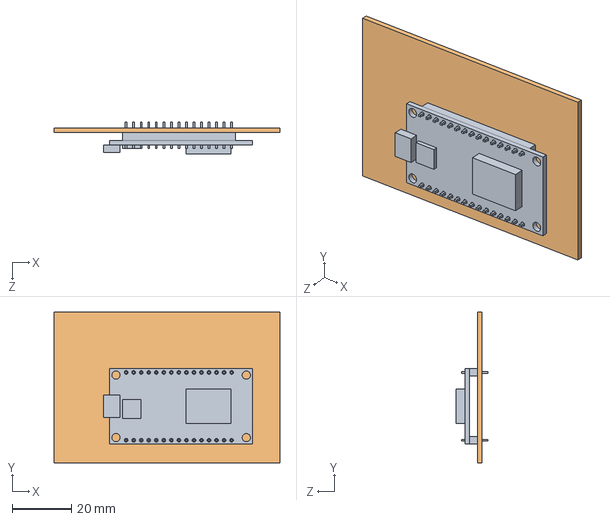
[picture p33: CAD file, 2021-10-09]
cad/PCB_Models/M21-GP-0003.SLDASM
76.2 x 50.8 x 10.7 mm
ESP8266
M21-GP-7002

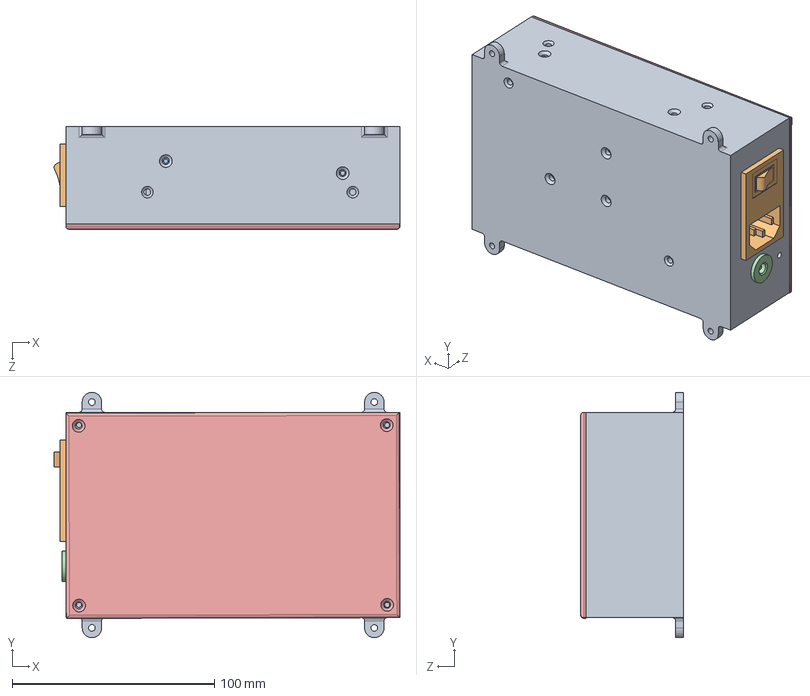
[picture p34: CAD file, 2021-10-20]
cad/PowerSupplyBox/M21-GP-0004.SLDASM
171.2 x 121.4 x 50.8 mm
M21-GP-3008
AC_PowerSocketWithSwitchAndFuse
AC_PowerSupply_Amazon_12v_5Amps
Jack_5p5mm_2p5mm
M21-GP-3009

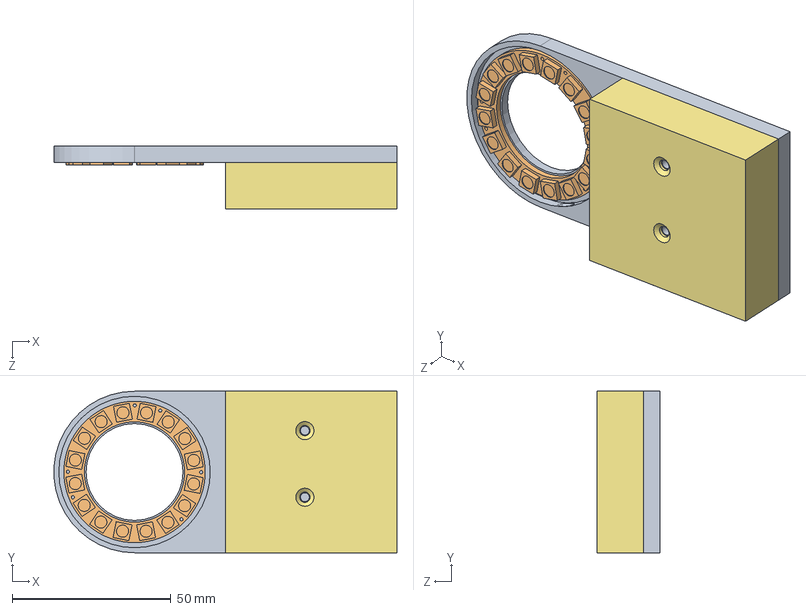
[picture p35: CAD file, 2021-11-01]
cad/CamerRingLEDs/M21-GP-0005.SLDASM
107.9 x 50.8 x 19.7 mm
M21-GP-3010
LED_Ring_16_Adafruit
Trinket_M0_Adafruit
DCtoDC_Convertor_2Amp
M21-GP-7004
JST_XH_3Pin_Jack

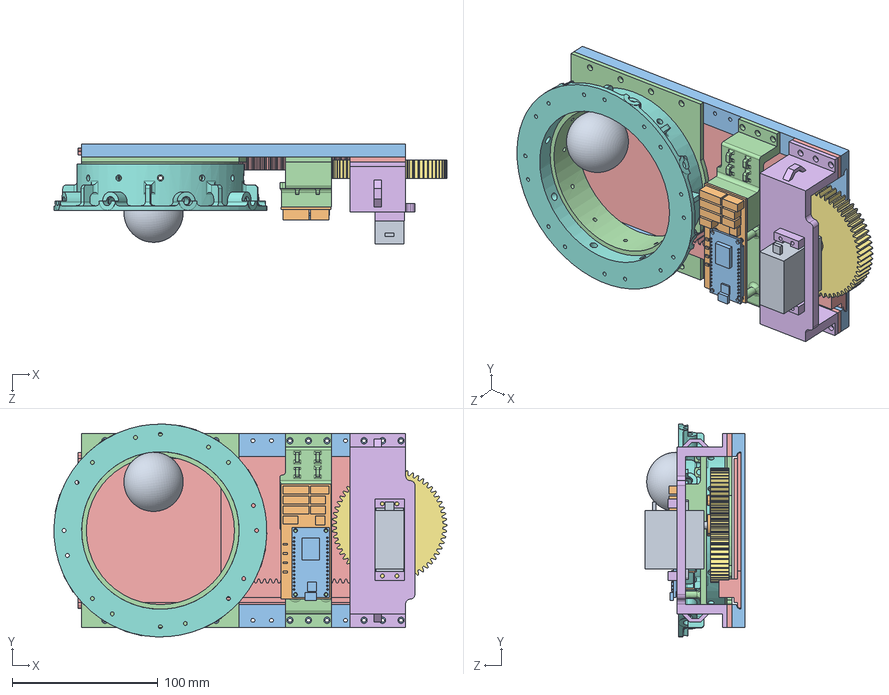
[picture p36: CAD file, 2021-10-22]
cad/DoorSliderTarget/M21-SL-0002.SLDASM
269.6 x 146.0 x 68.5 mm
ZOSKAY_25K_Servo
HornFor_ZOSKAY_25K_Servo
M21-SL-3002
M21-SL-3001
M21-SL-3003
M21-SL-3006
M21-SL-3007
M21-SL-3009
M21-GP-7001
ESP8266
M21-SL-3011
M21-SL-3012 x 2

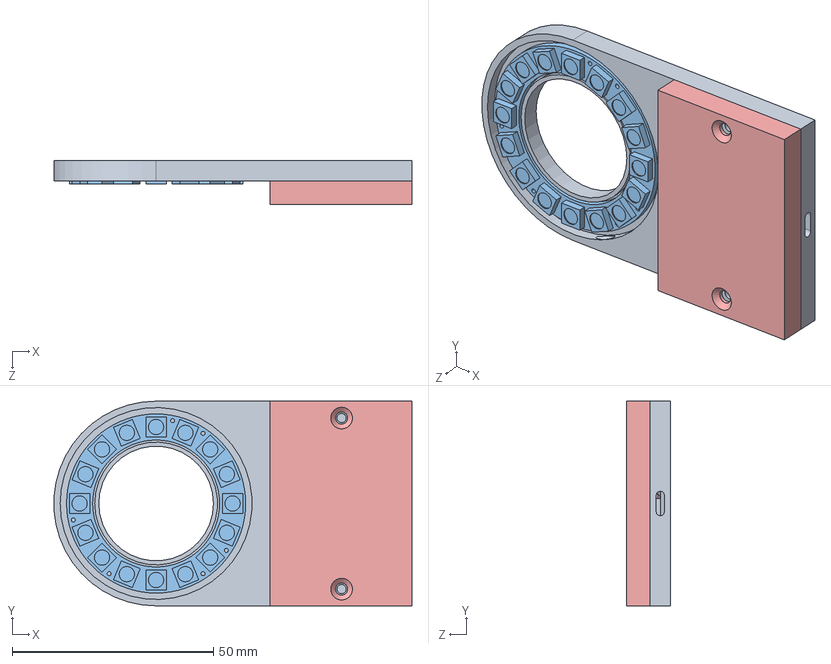
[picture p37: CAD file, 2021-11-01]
cad/CamerRingLEDs/M21-GP-0006.SLDASM
88.8 x 50.8 x 10.9 mm
M21-GP-3012
DCtoDC_Convertor_eBoot_Mini_MP1584EN_Amazon
LED_Ring_16_Adafruit
Trinket_M0_Adafruit
M21-GP-3013

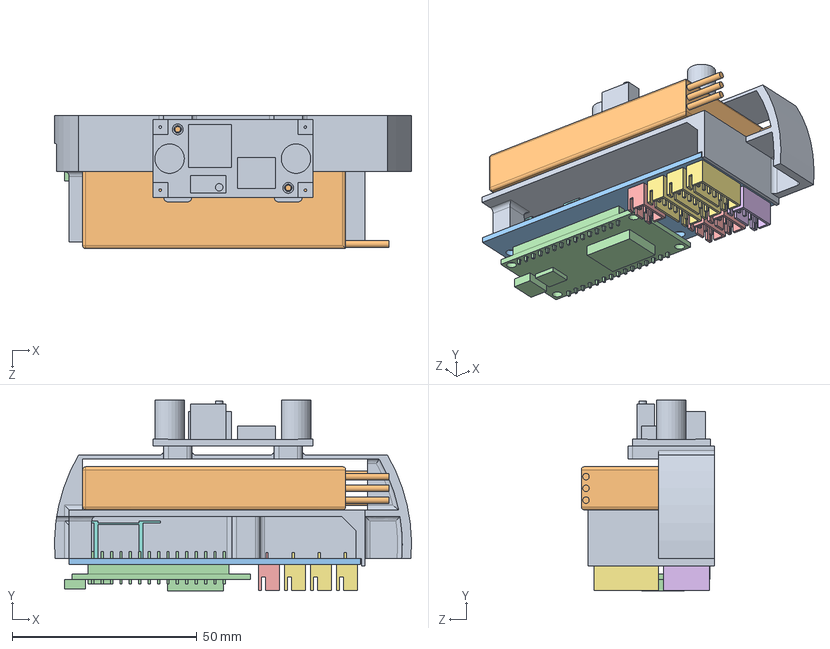
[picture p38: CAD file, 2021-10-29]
cad/MovingTarget/M21-MT-0006.SLDASM
96.5 x 51.5 x 36.1 mm
M21-MT-3009
LipoBattery_1000mah_2S_Amazon
M21-MT-7003
ESP8266
JST_XH_3Pin_Jack x 3
JST_XH_4Pin_Jack
JST_XH_6Pin_Jack x 3
HeatSink_Digitkey
DCtoDC_Convertor_2Amp

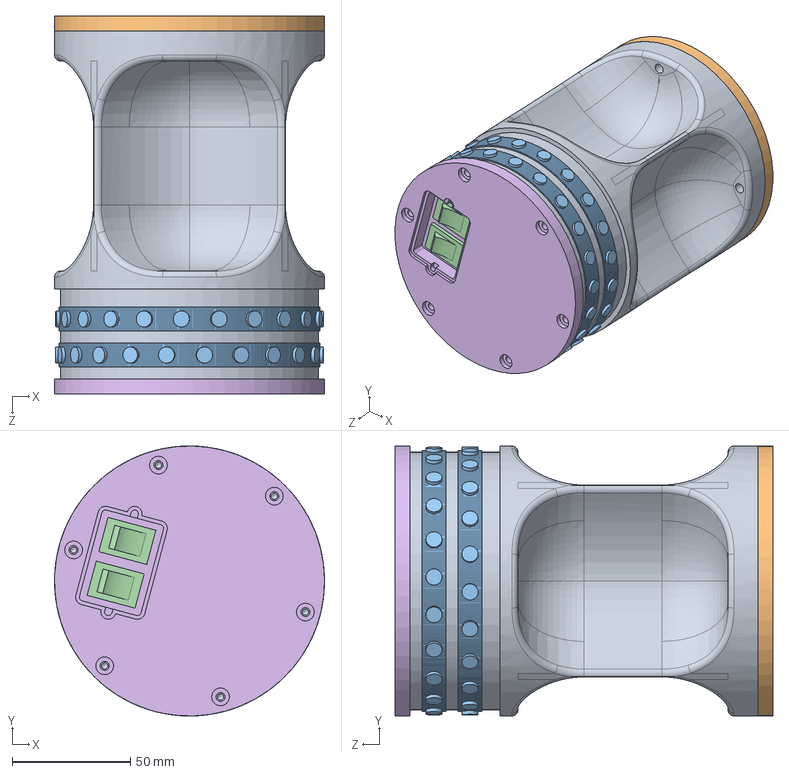
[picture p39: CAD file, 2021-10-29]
cad/MovingTarget/M21-MT-0004.SLDASM
114.4 x 114.3 x 160.0 mm
M21-MT-3002
M21-MT-3003
NeopixelRingSLDPRT x 2
RockerSwitch x 2
M21-MT-3009
LipoBattery_1000mah_2S_Amazon
M21-MT-7003
ESP8266
JST_XH_3Pin_Jack x 3
JST_XH_4Pin_Jack
JST_XH_6Pin_Jack x 3
HeatSink_Digitkey
DCtoDC_Convertor_2Amp
M21-MT-3010

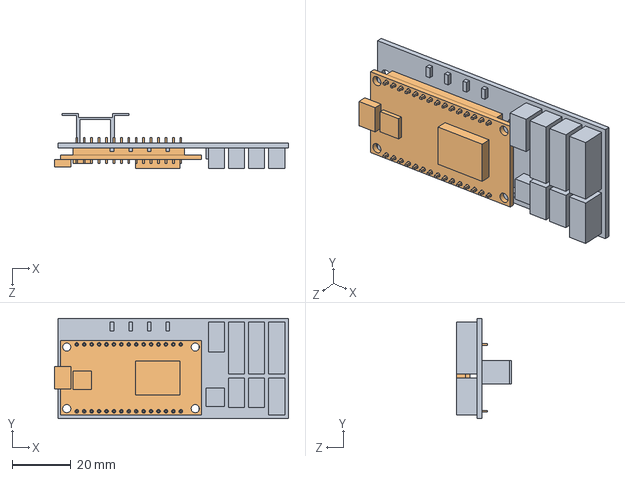
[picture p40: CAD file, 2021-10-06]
cad/PCB_Models/M21-GP-0002.SLDASM
80.0 x 34.3 x 18.9 mm
M21-GP-7001
ESP8266

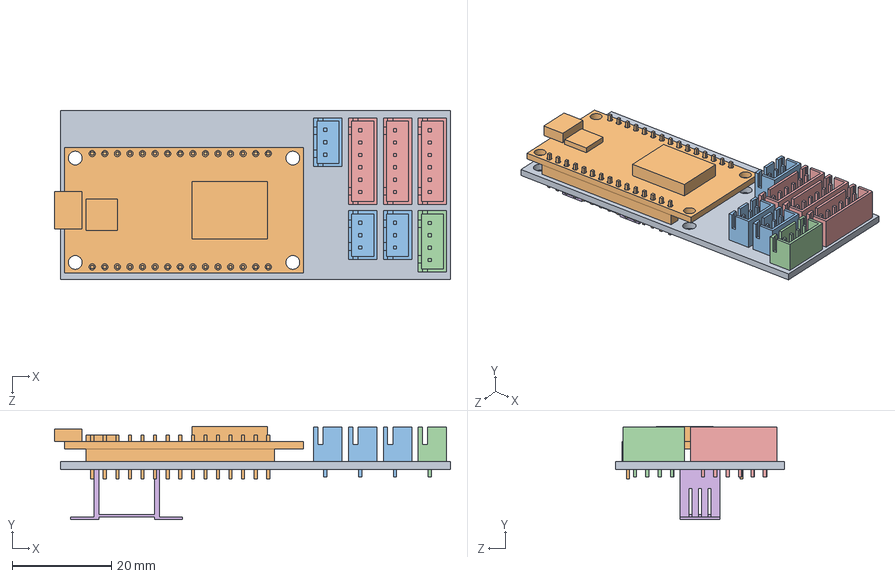
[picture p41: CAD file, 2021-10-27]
cad/MovingTarget/M21-MT-0005.SLDASM
80.0 x 18.9 x 34.1 mm
M21-MT-7003
ESP8266
JST_XH_3Pin_Jack x 3
JST_XH_4Pin_Jack
JST_XH_6Pin_Jack x 3
HeatSink_Digitkey

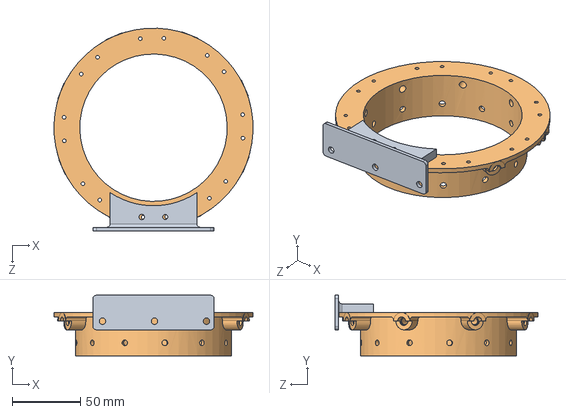
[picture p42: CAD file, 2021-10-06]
cad/DoorSliderTarget/M21-SL-0003.SLDASM
145.9 x 44.5 x 148.5 mm
M21-SL-3010
M21-SL-3009

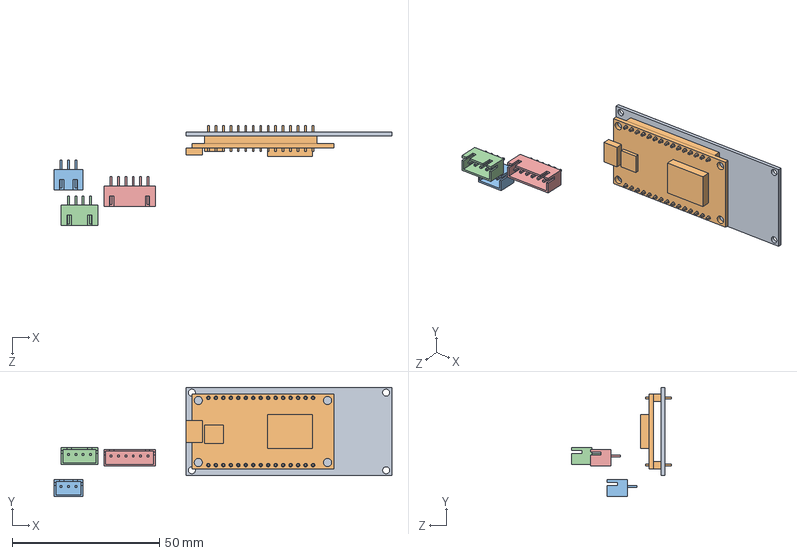
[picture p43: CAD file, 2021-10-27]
cad/MovingTarget/M21-MT-0003.SLDASM
114.9 x 37.2 x 34.1 mm
ElegooBoard_Thin
ESP8266
JST_XH_3Pin_Jack
JST_XH_4Pin_Jack
JST_XH_6Pin_Jack

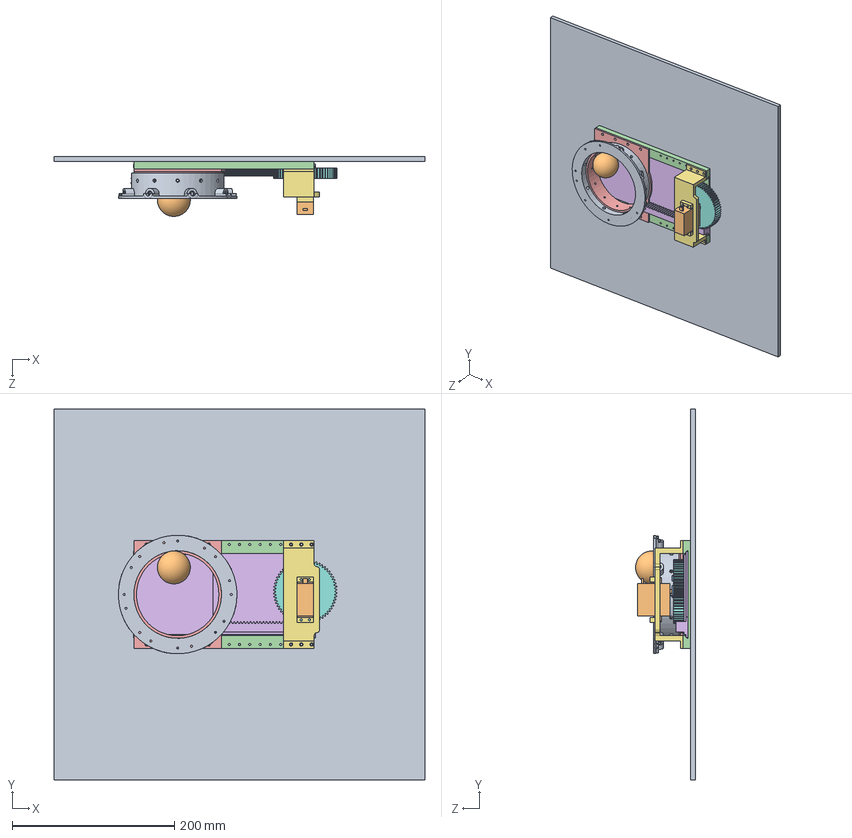
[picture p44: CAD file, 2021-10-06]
cad/DoorSliderTarget/M21-SL-0001.SLDASM
457.2 x 457.2 x 73.7 mm
M21-SL-6001
ZOSKAY_25K_Servo
HornFor_ZOSKAY_25K_Servo
M21-SL-3002
M21-SL-3001
M21-SL-3003
M21-SL-3006
M21-SL-3007
M21-SL-3009
M21-SL-7001

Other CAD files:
cad/MovingTarget/M21-MT-0001.SLDASM
cad/MovingTarget/M21-MT-0002.SLDASM
cad/CamerRingLEDs/M21-GP-3013.SLDPRT
cad/DocTrash/TargetBoardForDiagram.SLDPRT
cad/BasketTarget/M21-HG-3001.SLDPRT
cad/BasketTarget/M21-HG-3002.SLDPRT
cad/BasketTarget/M21-HG-3003.SLDPRT
cad/BasketTarget/M21-HG-3004.SLDPRT
cad/BasketTarget/M21-HG-3005.SLDPRT
cad/BasketTarget/M21-HG-7001.SLDPRT
cad/BasketTarget/M21-HG-7002.SLDPRT
cad/CamerRingLEDs/M21-GP-3010.SLDPRT
cad/CamerRingLEDs/M21-GP-3011.SLDPRT
cad/CamerRingLEDs/M21-GP-3012.SLDPRT
cad/CamerRingLEDs/M21-GP-7004.SLDPRT
cad/DocTrash/BasketForDiagram.SLDPRT
cad/DocTrash/MovingTargetForDiagram.SLDPRT
cad/DoorSliderTarget/M21-SL-0001.SLDDRW
cad/DoorSliderTarget/M21-SL-3001.SLDPRT
cad/DoorSliderTarget/M21-SL-3002.SLDPRT
cad/DoorSliderTarget/M21-SL-3003.SLDPRT
cad/DoorSliderTarget/M21-SL-3004..SLDPRT
cad/DoorSliderTarget/M21-SL-3005.SLDPRT
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

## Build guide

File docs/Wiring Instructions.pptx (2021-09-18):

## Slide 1

IR Emitter / Detector Wiring

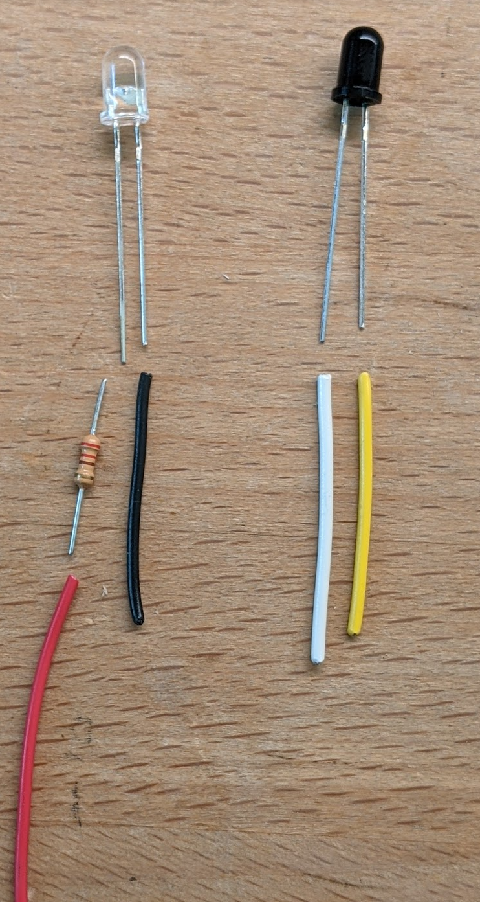
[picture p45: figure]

The Clear LED is the Emitter.
Connect a Red wire to a 220 ohm resister and then to the long lead. On the short lead, connect a black wire.
Use 24-26 AWG stranded wire.
When powered with 5 volts,
Each emitter will draw about 14 mA.

The Dark Blub Component is the Detector.
Connect a white wire to the long lead. Connect a yellow wire to the short lead.
Use 24-26 AWG stranded wire.
In the circuit, the white lead will be connected to ground. When the detector is “on”, current will flow from the yellow wire though the detector to ground.

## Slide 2

IR Emitter / Detector Test Circuit

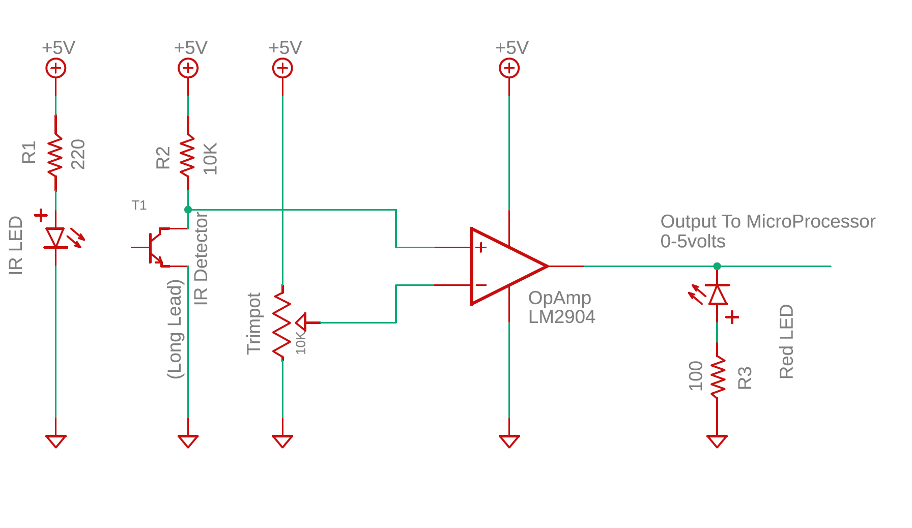
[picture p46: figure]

Notes:
1. The IR Emitter, as shown with a 220 ohm resistor draws about 17 mA.
2. The voltage at the + terminal on the OpAmp runs between 0.12 volts when the beam is detected, and 3.5 volts when the beam is broken.
3. The OpAmp is wired as a simple comparator. It outputs a hard 0 volts if the beam is detected, and about 3.5 volts if the beam is broken.
4. The Red LED after the OpAmp is included to indicate when the beam is broken.

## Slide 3

Ring Detection Circuit, Version 1

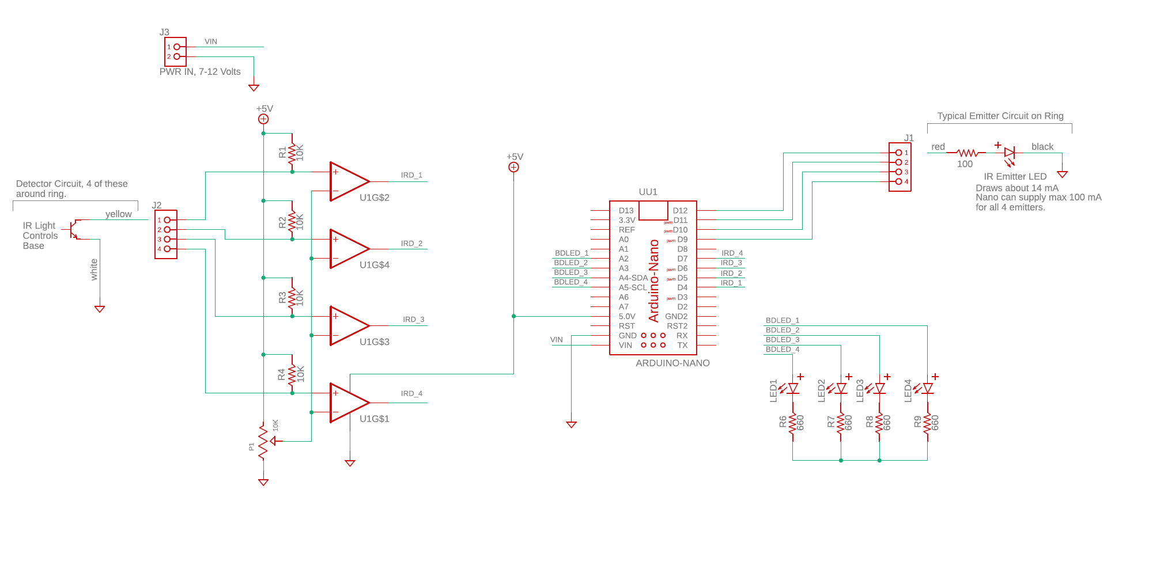
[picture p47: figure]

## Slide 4

INFO About Arduino NANO – Pin Mappings

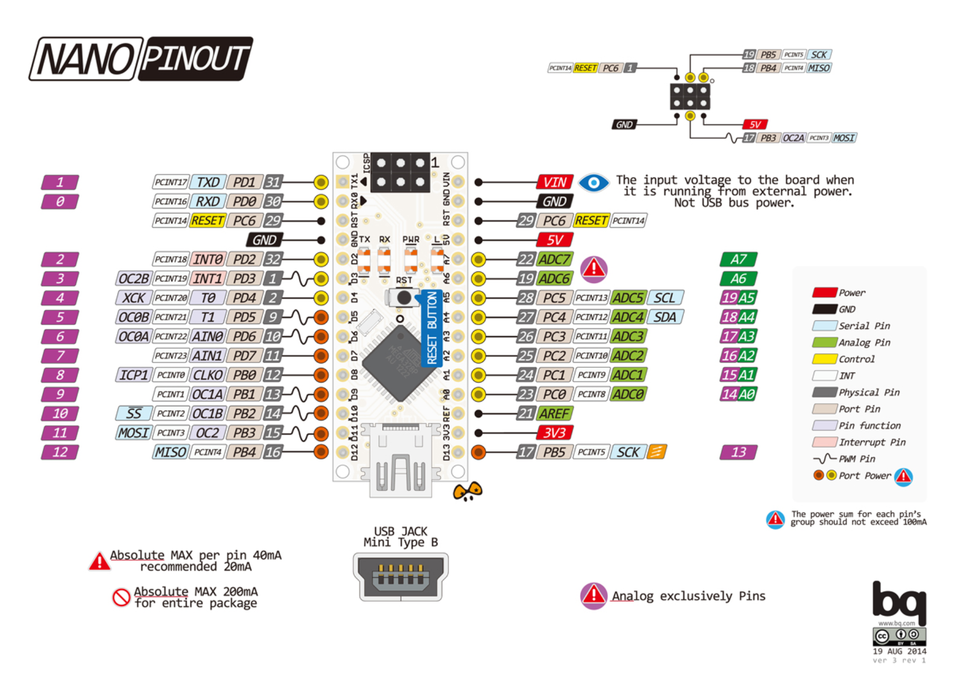
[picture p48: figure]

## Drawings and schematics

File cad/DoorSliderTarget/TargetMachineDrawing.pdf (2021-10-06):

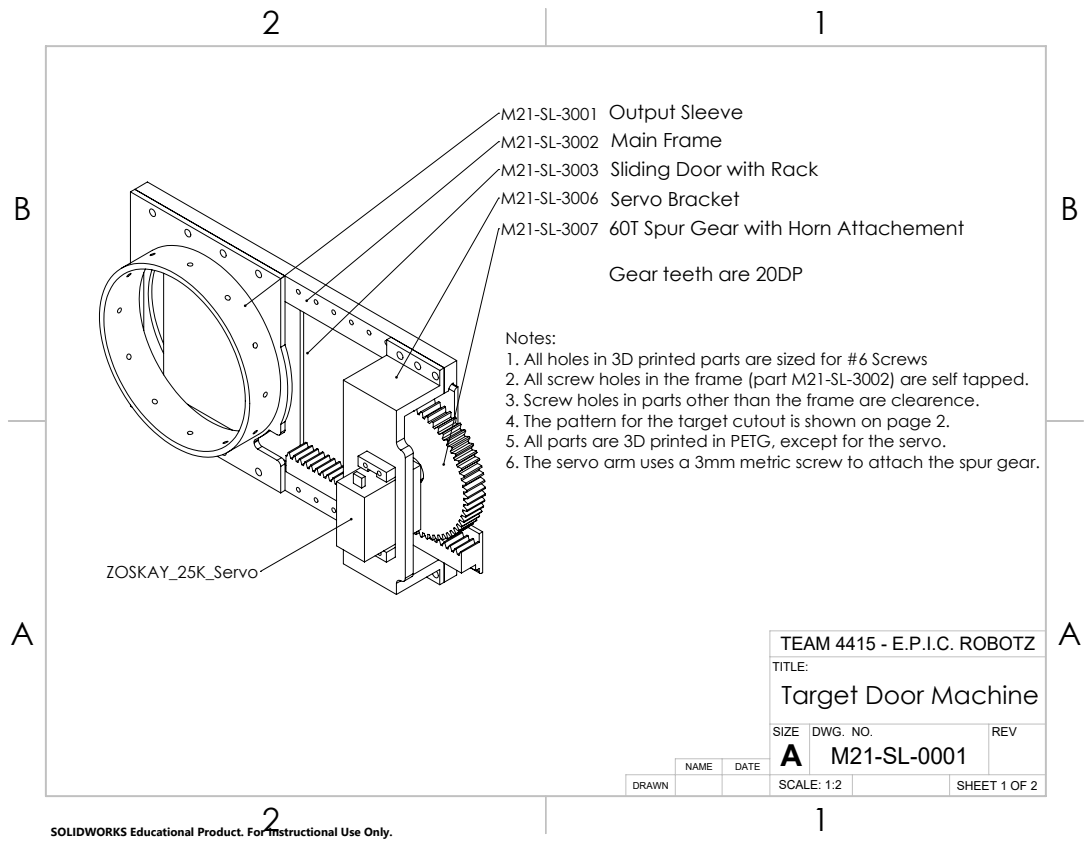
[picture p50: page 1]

Output Sleeve
Main Frame
Sliding Door with Rack
Servo Bracket
60T Spur Gear with Horn Attachement
Gear teeth are 20DP

Notes:
1. All holes in 3D printed parts are sized for #6 Screws
2. All screw holes in the frame (part M21-SL-3002) are self tapped.
3. Screw holes in parts other than the frame are clearence.
4. The pattern for the target cutout is shown on page 2.
5. All parts are 3D printed in PETG, except for the servo.
6. The servo arm uses a 3mm metric screw to attach the spur gear.

TEAM 4415 - E.P.I.C. ROBOTZ
TITLE:
Target Door Machine

SIZE A | DWG. NO. M21-SL-0001 | REV

NAME | DATE

DRAWN | | SCALE: 1:2 | SHEET 1 OF 2

SOLIDWORKS Educational Product. For Instructional Use Only.

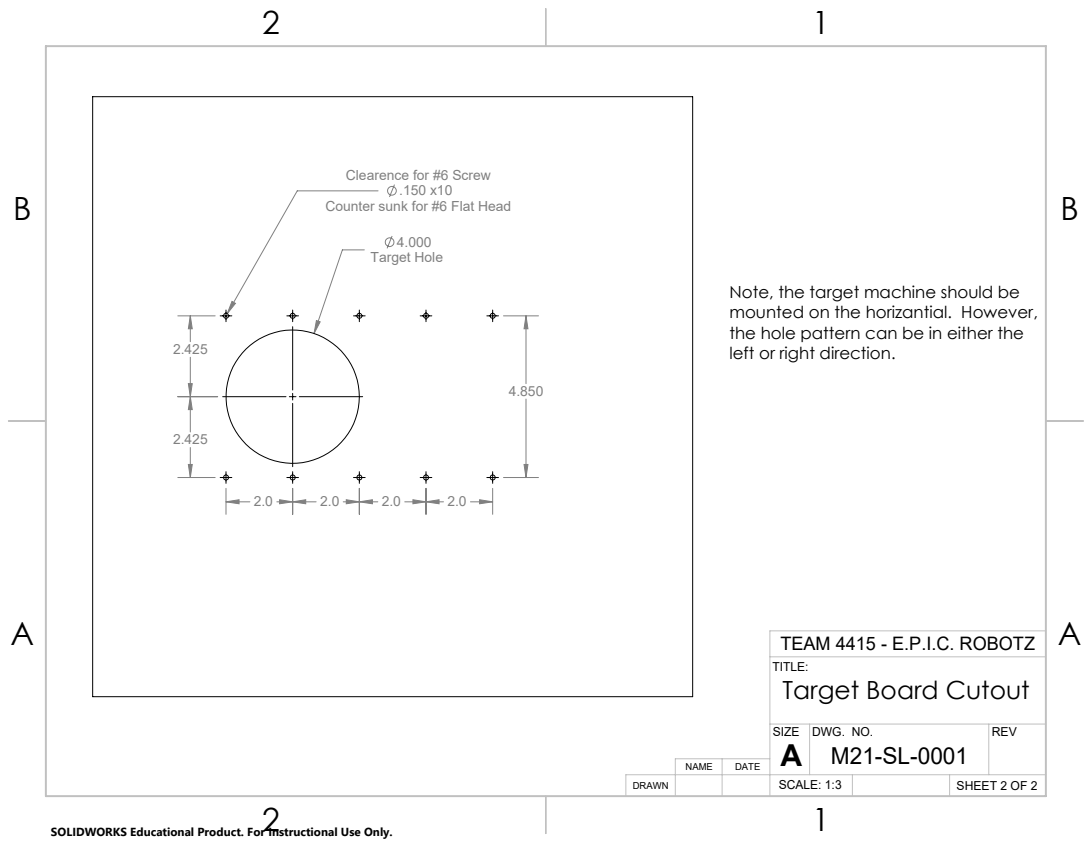
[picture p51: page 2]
Target Hole

Clearence for #6 Screw

Counter sunk for #6 Flat Head

Note, the target machine should be
mounted on the horizantial. However,
the hole pattern can be in either the
left or right direction.

TEAM 4415 - E.P.I.C. ROBOTZ
TITLE:
Target Board Cutout

SIZE A | DWG. NO. M21-SL-0001 | REV

NAME | DATE

DRAWN | | SCALE: 1:3 | SHEET 2 OF 2

SOLIDWORKS Educational Product. For Instructional Use Only.

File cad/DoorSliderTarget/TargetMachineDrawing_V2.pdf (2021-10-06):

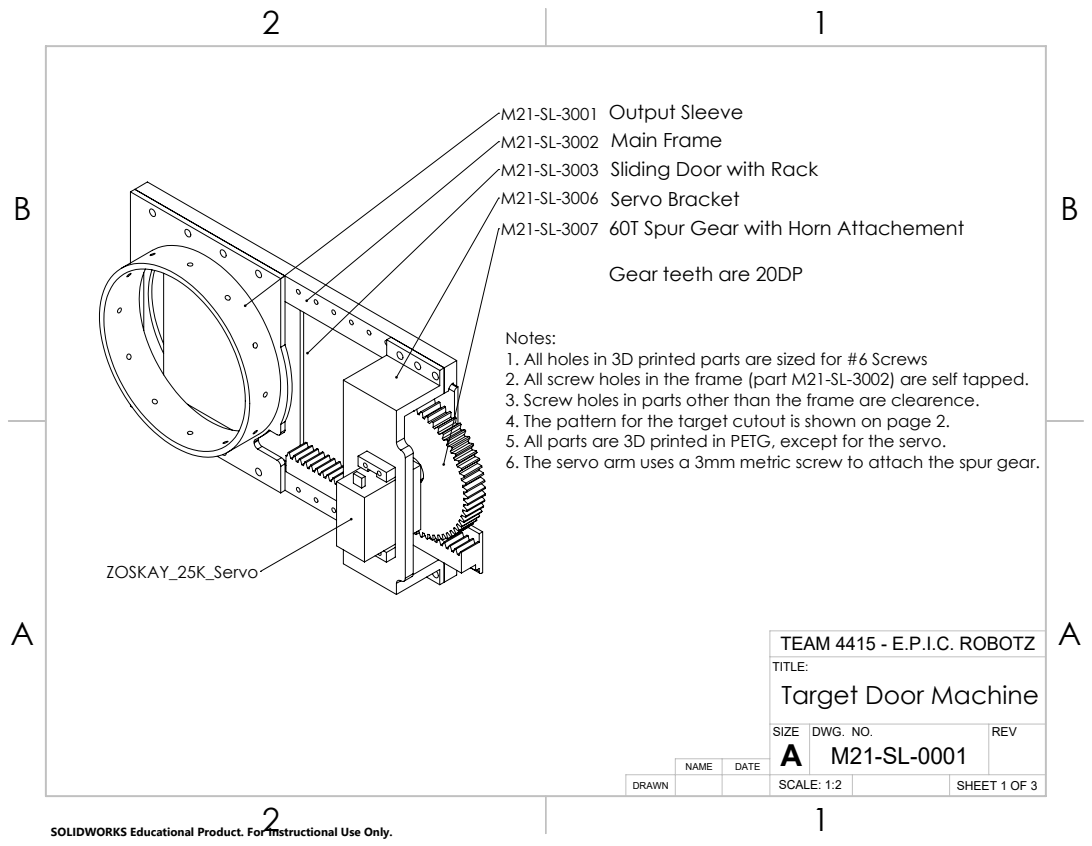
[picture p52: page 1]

Output Sleeve
Main Frame
Sliding Door with Rack
Servo Bracket
60T Spur Gear with Horn Attachement
Gear teeth are 20DP

Notes:
1. All holes in 3D printed parts are sized for #6 Screws
2. All screw holes in the frame (part M21-SL-3002) are self tapped.
3. Screw holes in parts other than the frame are clearence.
4. The pattern for the target cutout is shown on page 2.
5. All parts are 3D printed in PETG, except for the servo.
6. The servo arm uses a 3mm metric screw to attach the spur gear.

TEAM 4415 - E.P.I.C. ROBOTZ
TITLE:
Target Door Machine

SIZE A | DWG. NO. M21-SL-0001 | REV

NAME | DATE

DRAWN | | SCALE: 1:2 | SHEET 1 OF 3

SOLIDWORKS Educational Product. For Instructional Use Only.

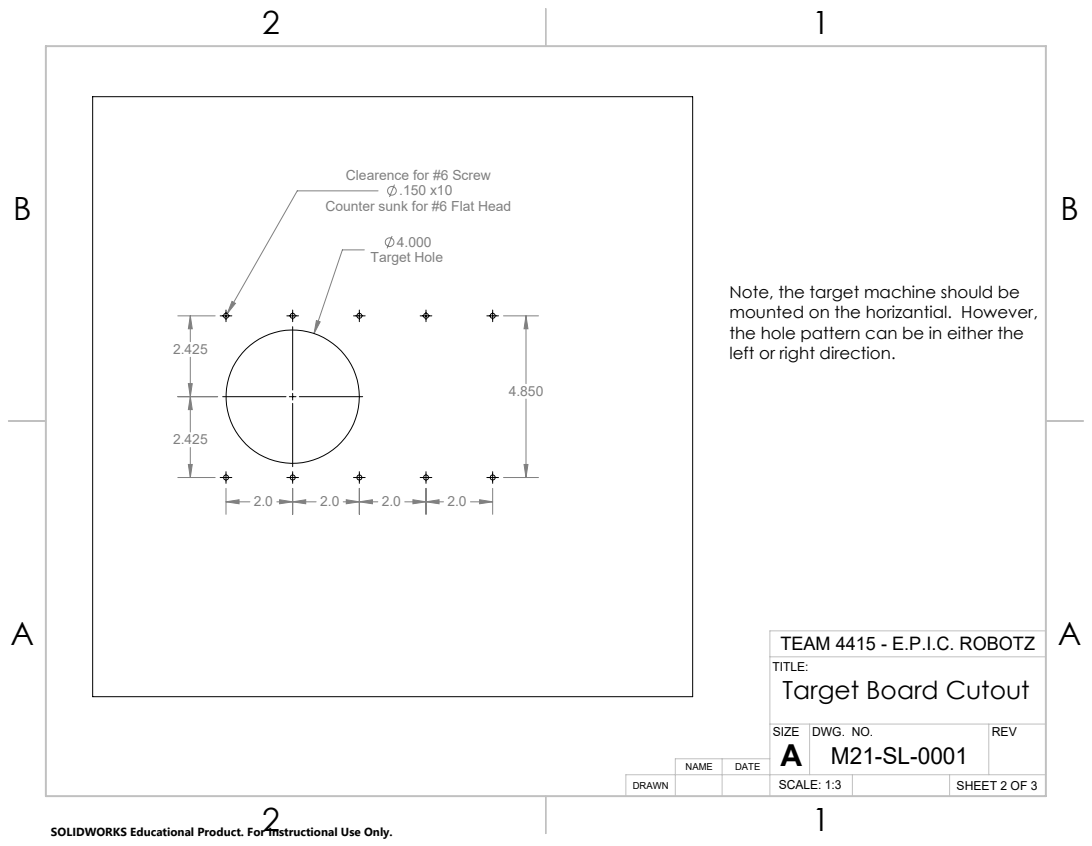
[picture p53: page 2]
Target Hole

Clearence for #6 Screw

Counter sunk for #6 Flat Head

Note, the target machine should be
mounted on the horizantial. However,
the hole pattern can be in either the
left or right direction.

TEAM 4415 - E.P.I.C. ROBOTZ
TITLE:
Target Board Cutout

SIZE A | DWG. NO. M21-SL-0001 | REV

NAME | DATE

SCALE: 1:3 | SHEET 2 OF 3

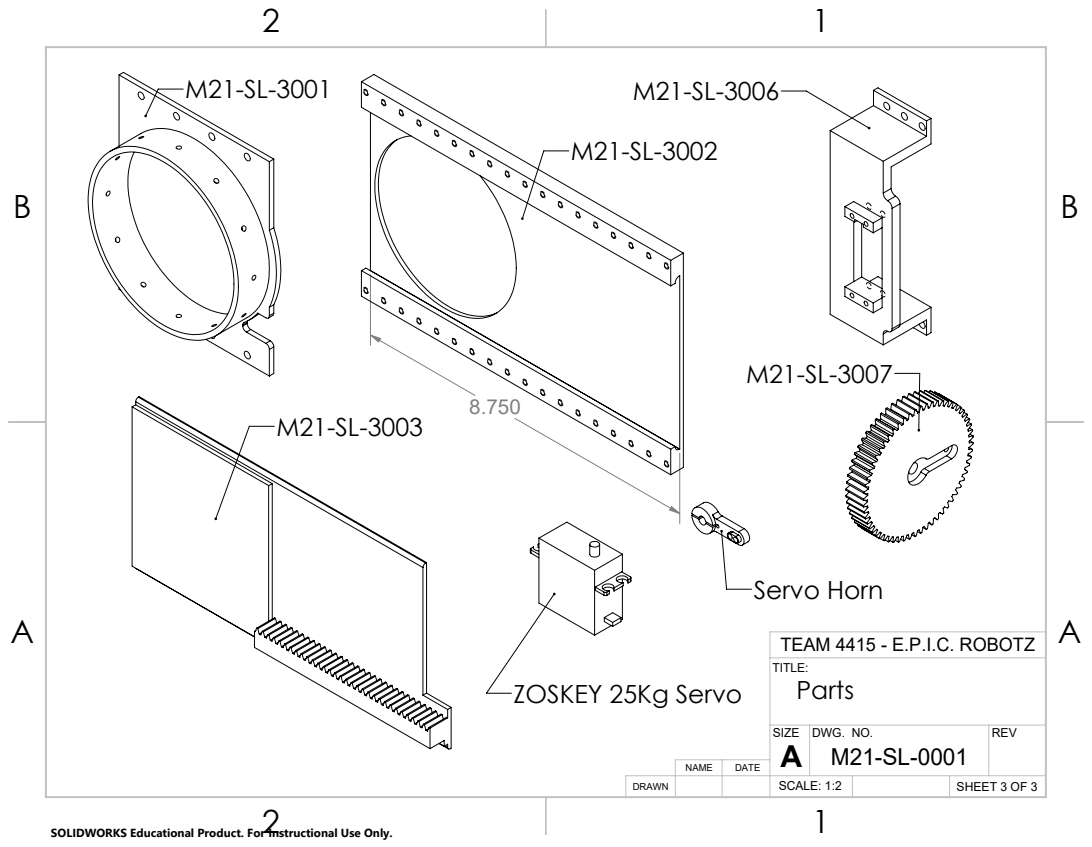
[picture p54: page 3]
ZOSKEY 25Kg Servo; Servo Horn; TEAM 4415 - E.P.I.C. ROBOTZ

SIZE A | DWG. NO. M21-SL-0001 | REV

NAME | DATE

SCALE: 1:2 | SHEET 3 OF 3

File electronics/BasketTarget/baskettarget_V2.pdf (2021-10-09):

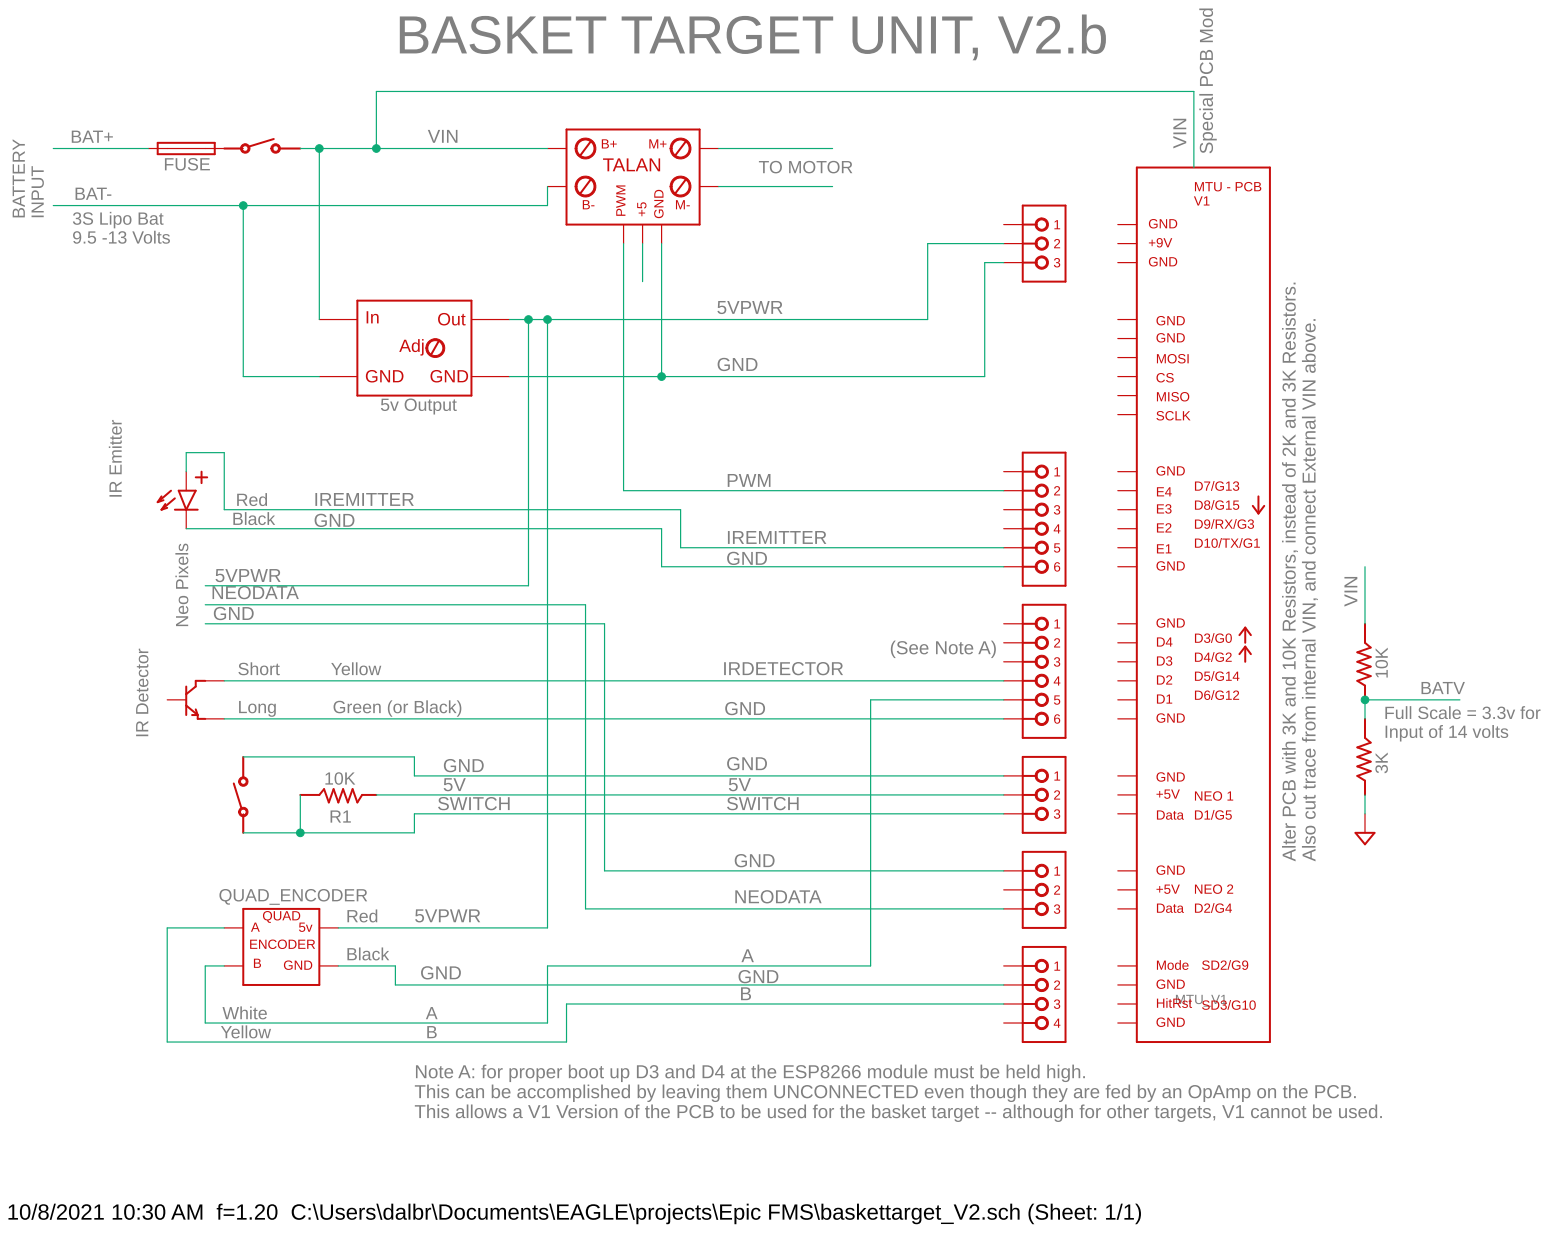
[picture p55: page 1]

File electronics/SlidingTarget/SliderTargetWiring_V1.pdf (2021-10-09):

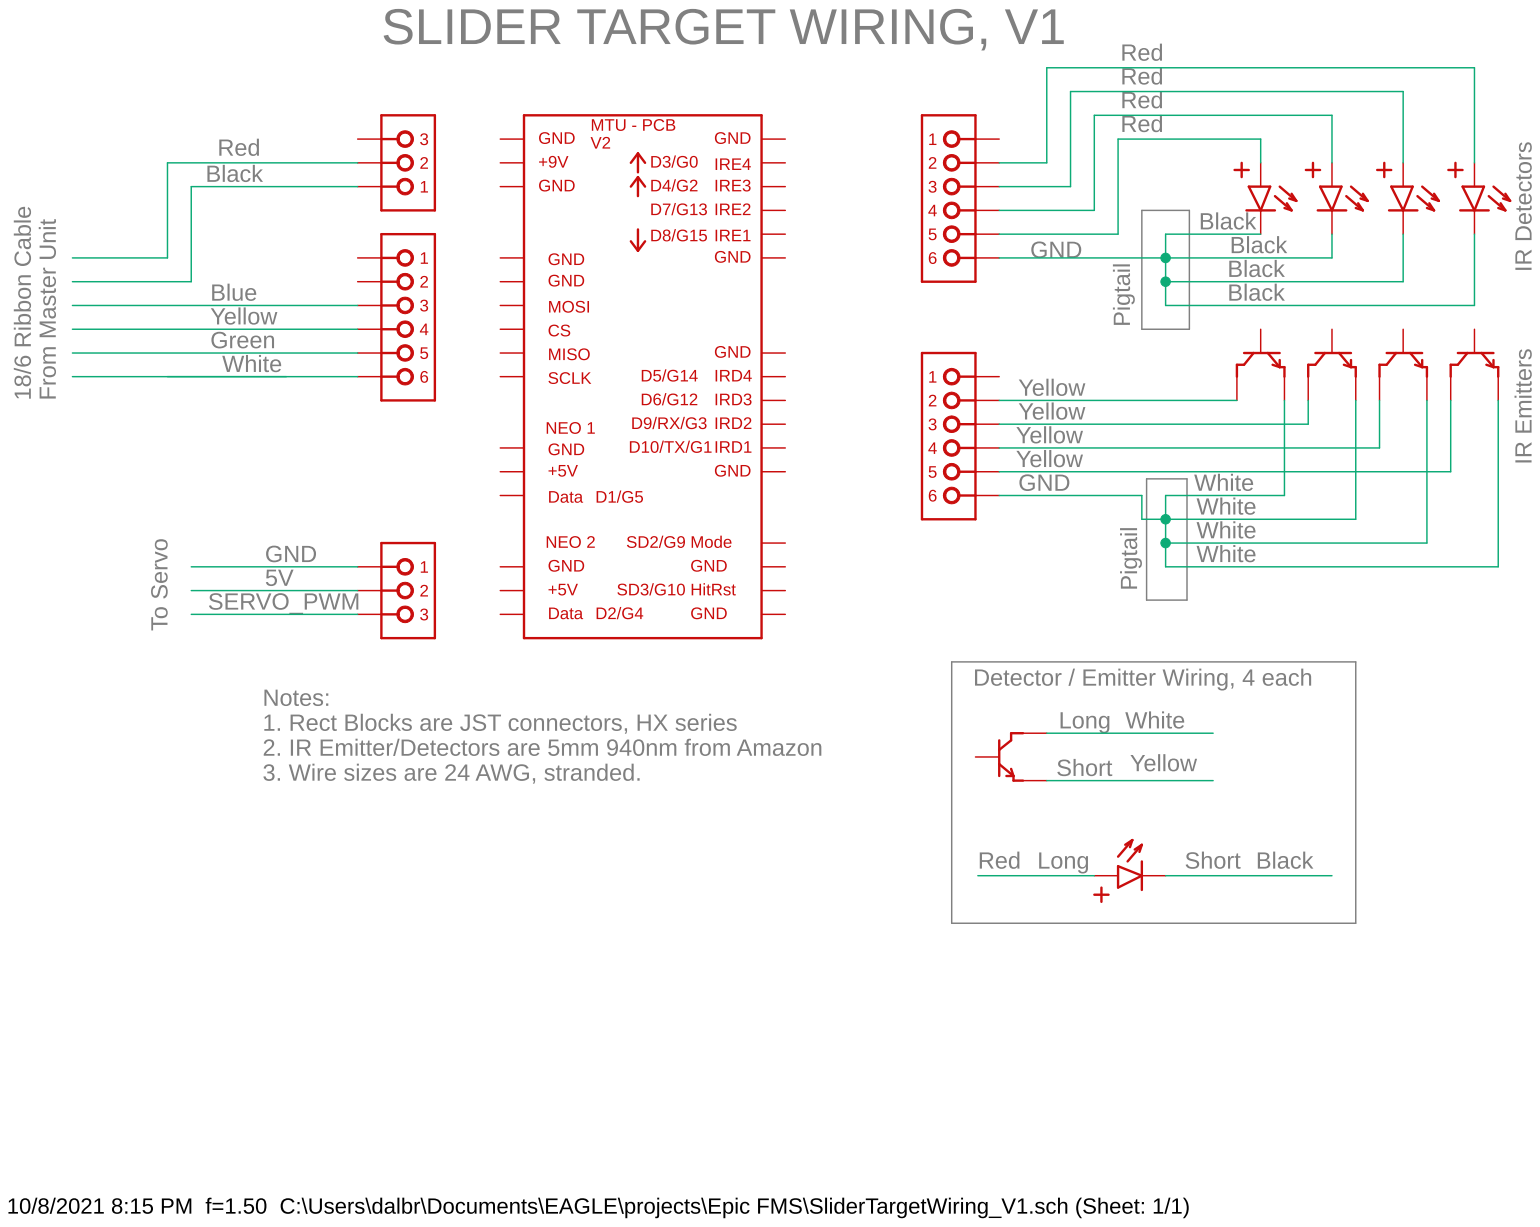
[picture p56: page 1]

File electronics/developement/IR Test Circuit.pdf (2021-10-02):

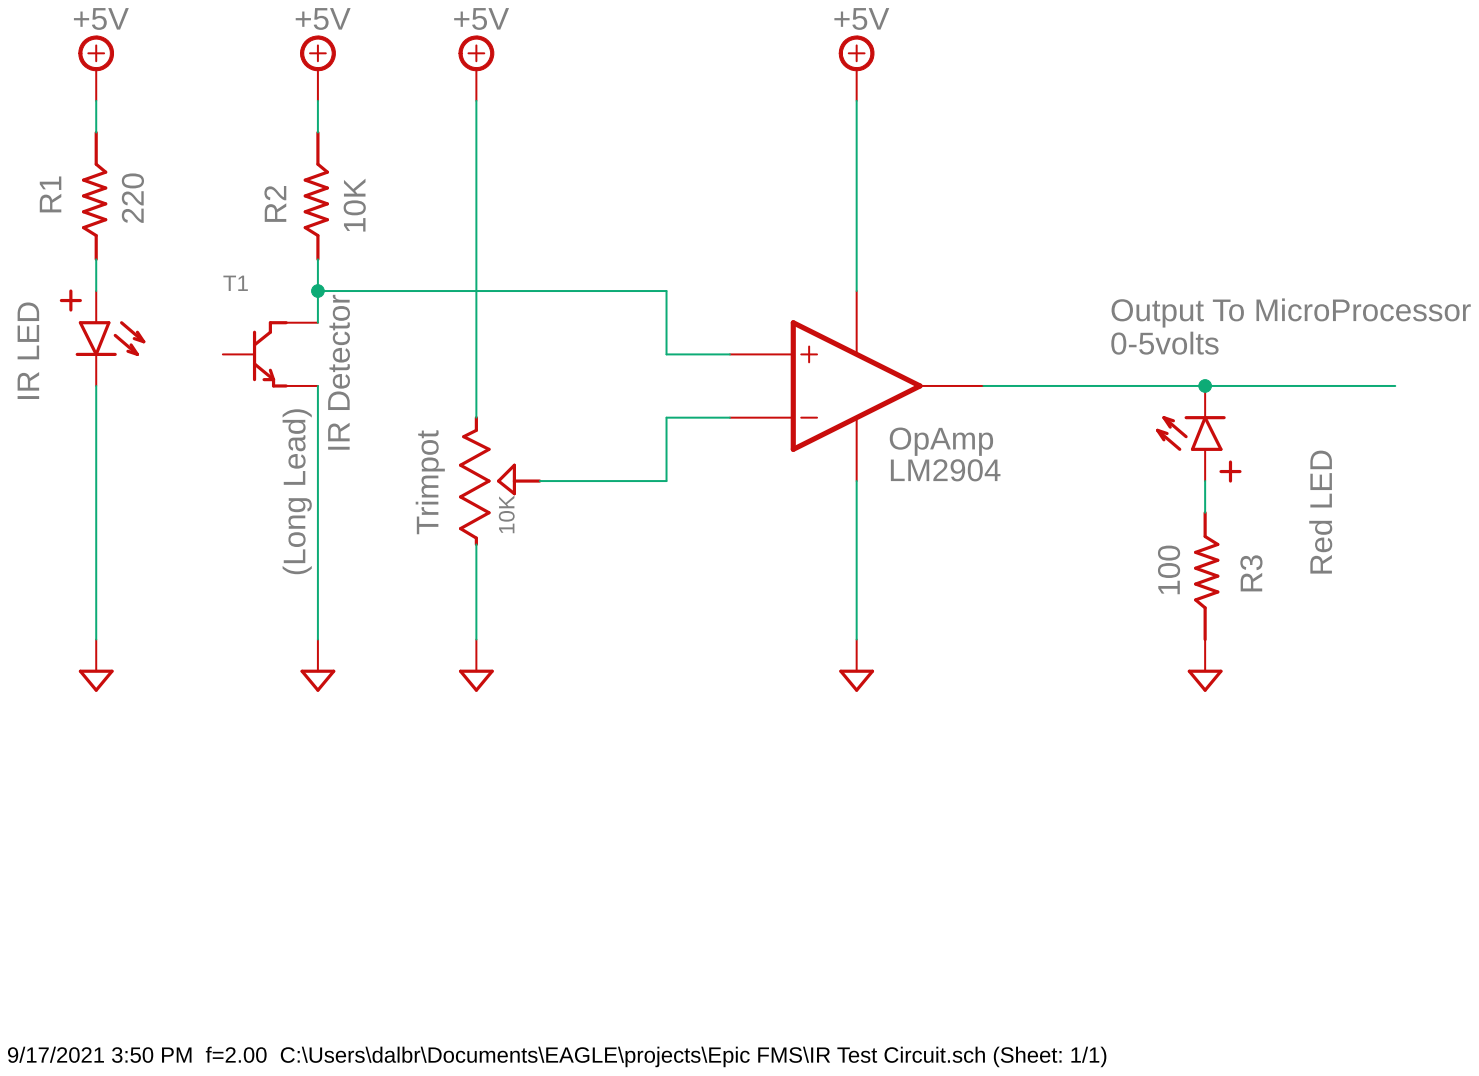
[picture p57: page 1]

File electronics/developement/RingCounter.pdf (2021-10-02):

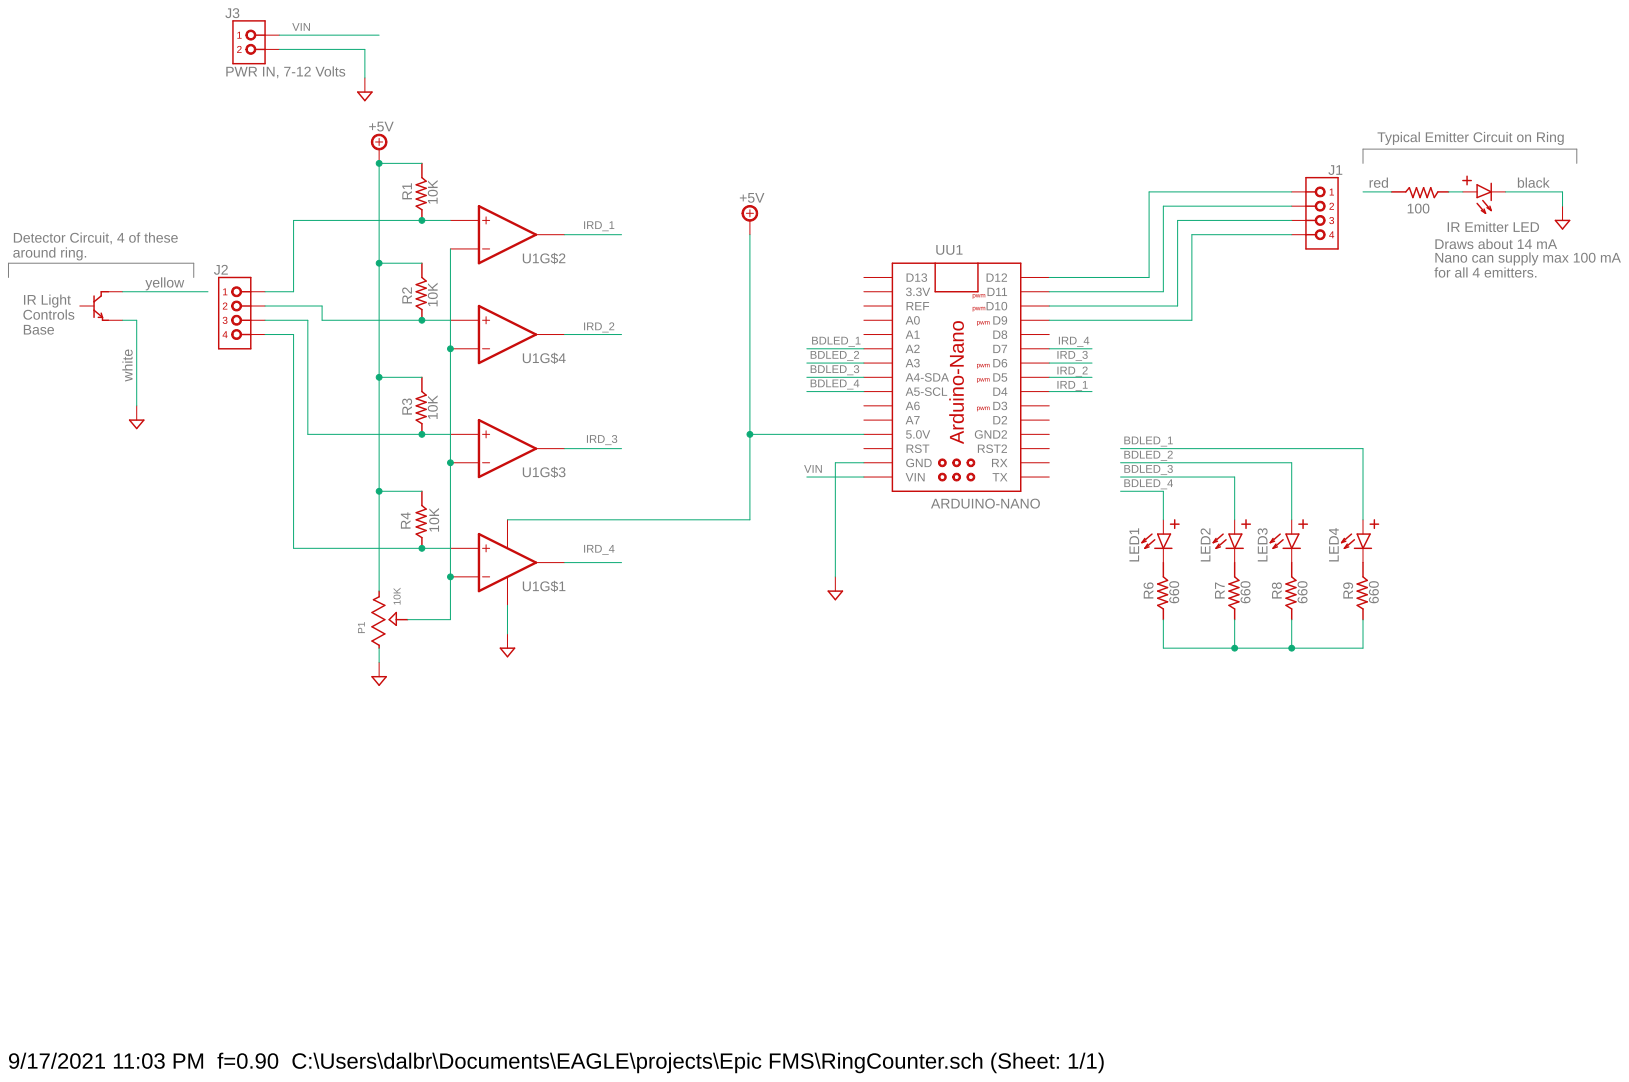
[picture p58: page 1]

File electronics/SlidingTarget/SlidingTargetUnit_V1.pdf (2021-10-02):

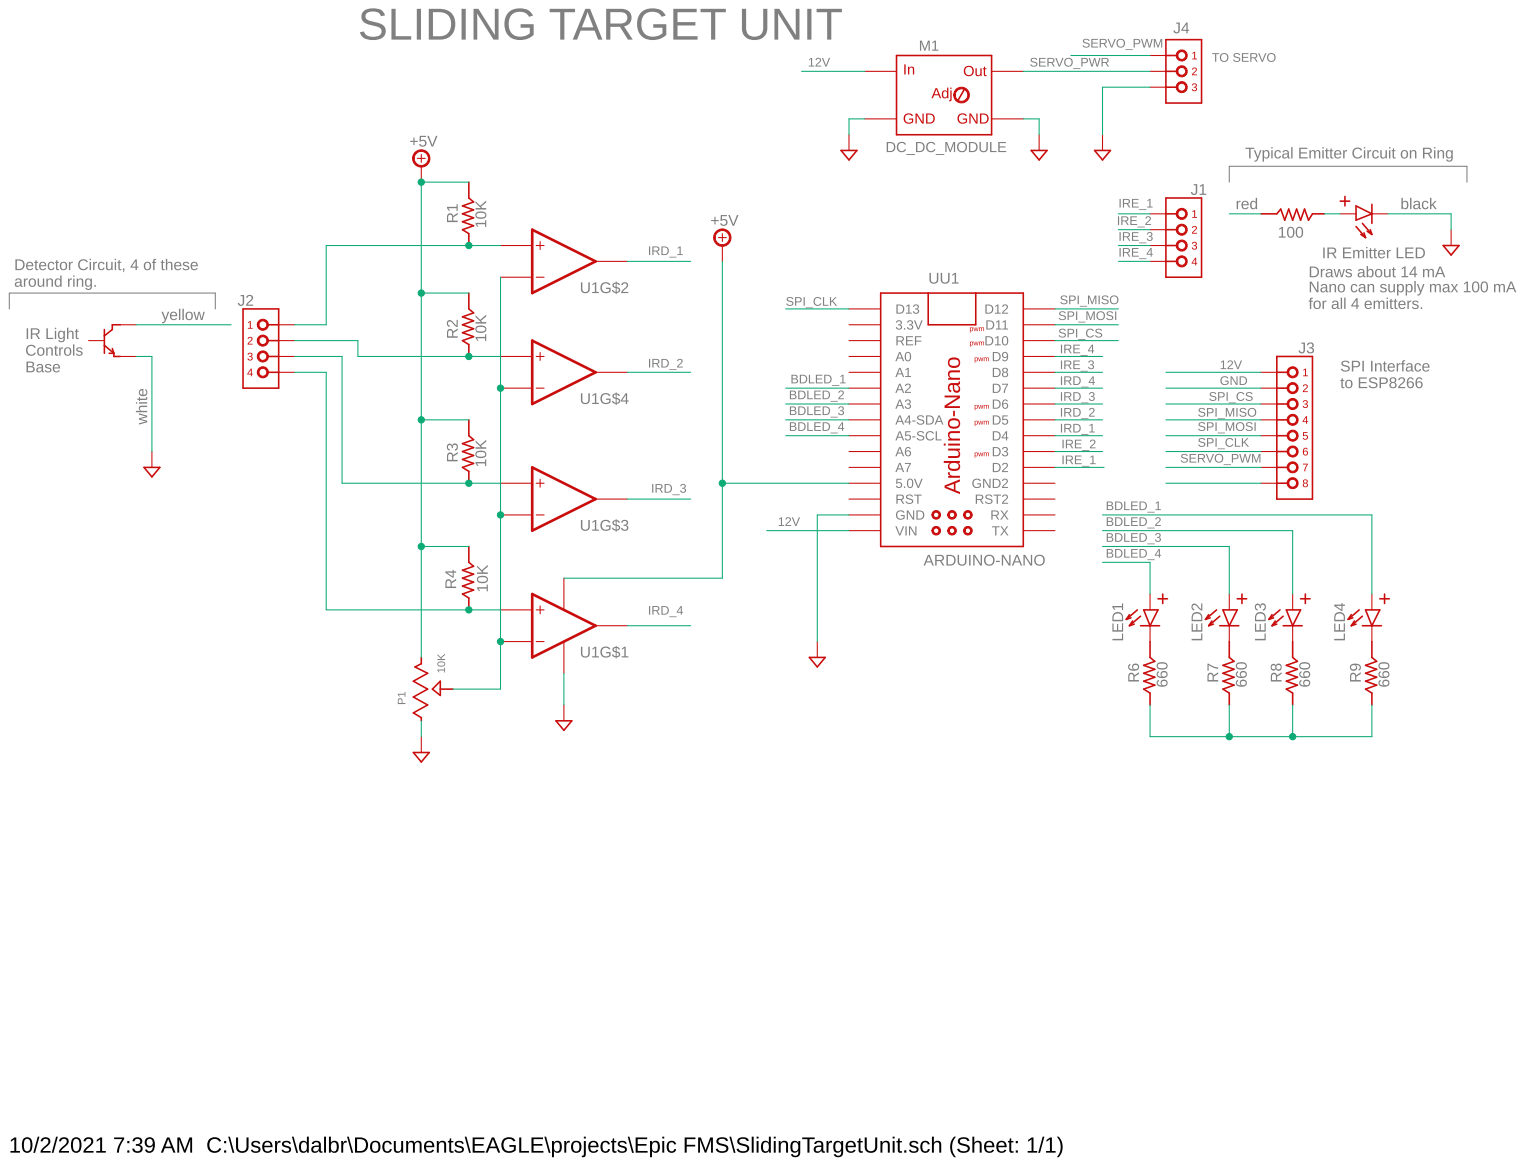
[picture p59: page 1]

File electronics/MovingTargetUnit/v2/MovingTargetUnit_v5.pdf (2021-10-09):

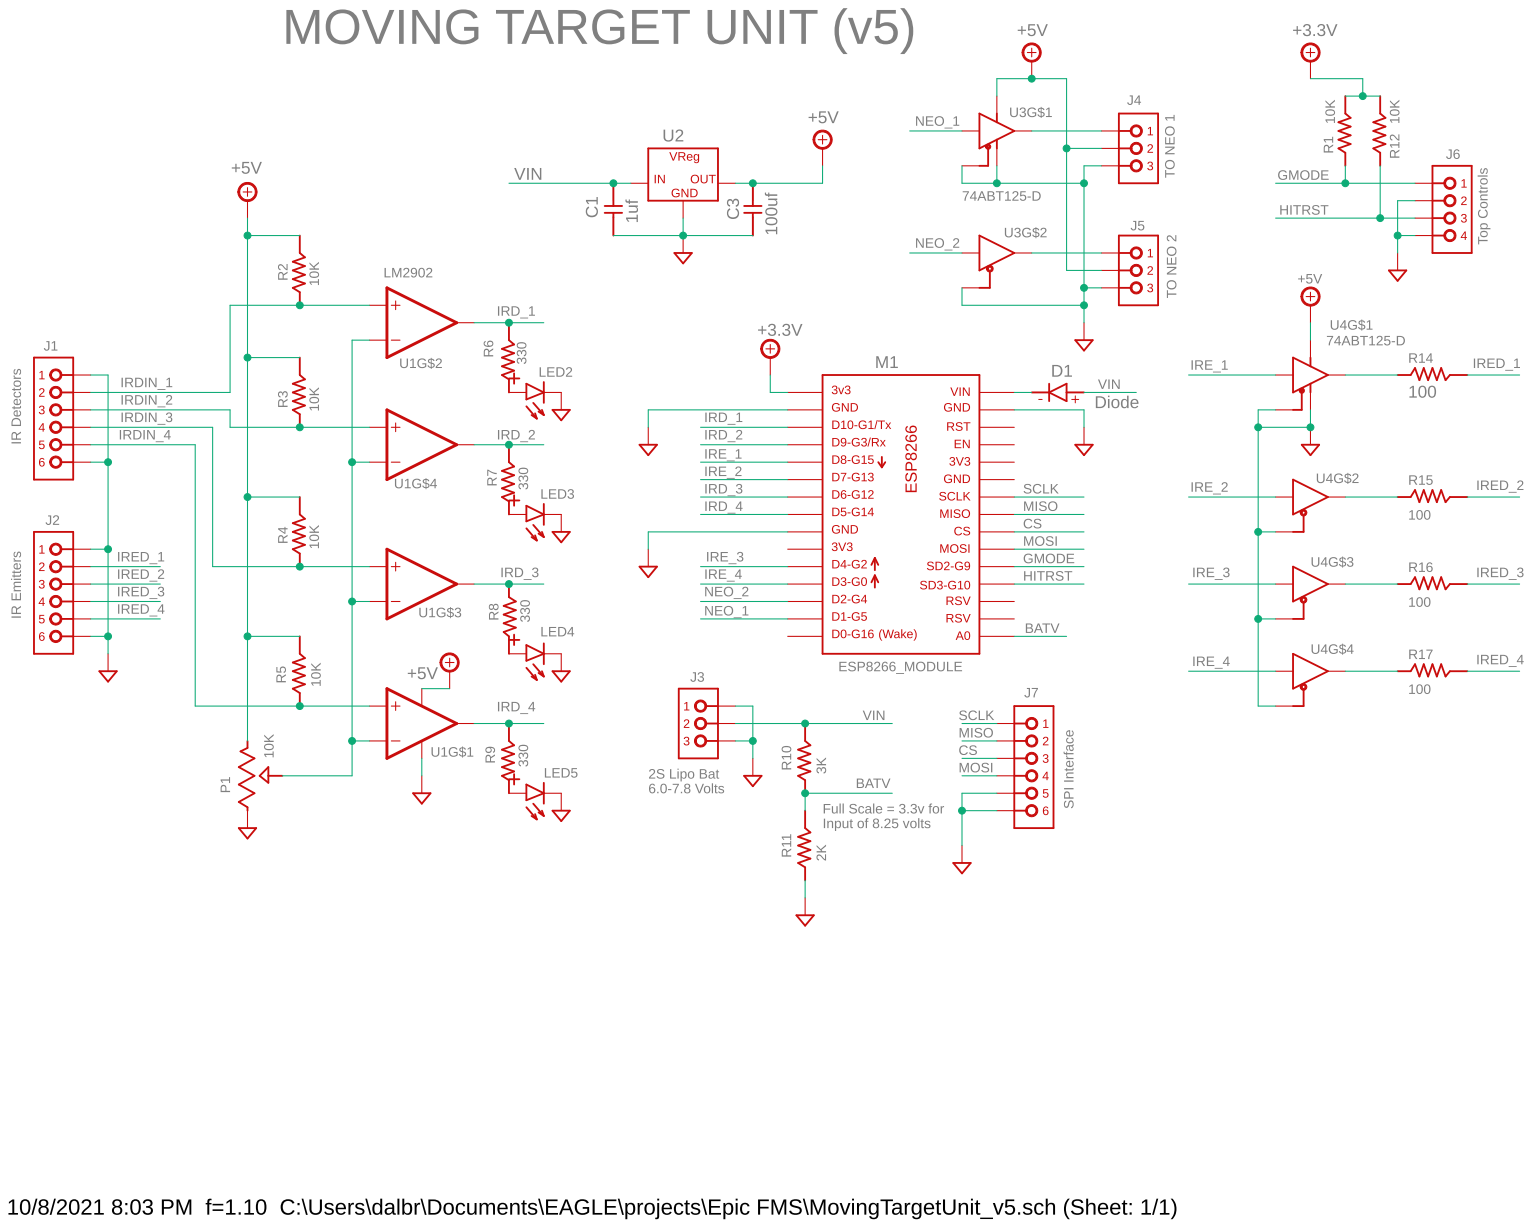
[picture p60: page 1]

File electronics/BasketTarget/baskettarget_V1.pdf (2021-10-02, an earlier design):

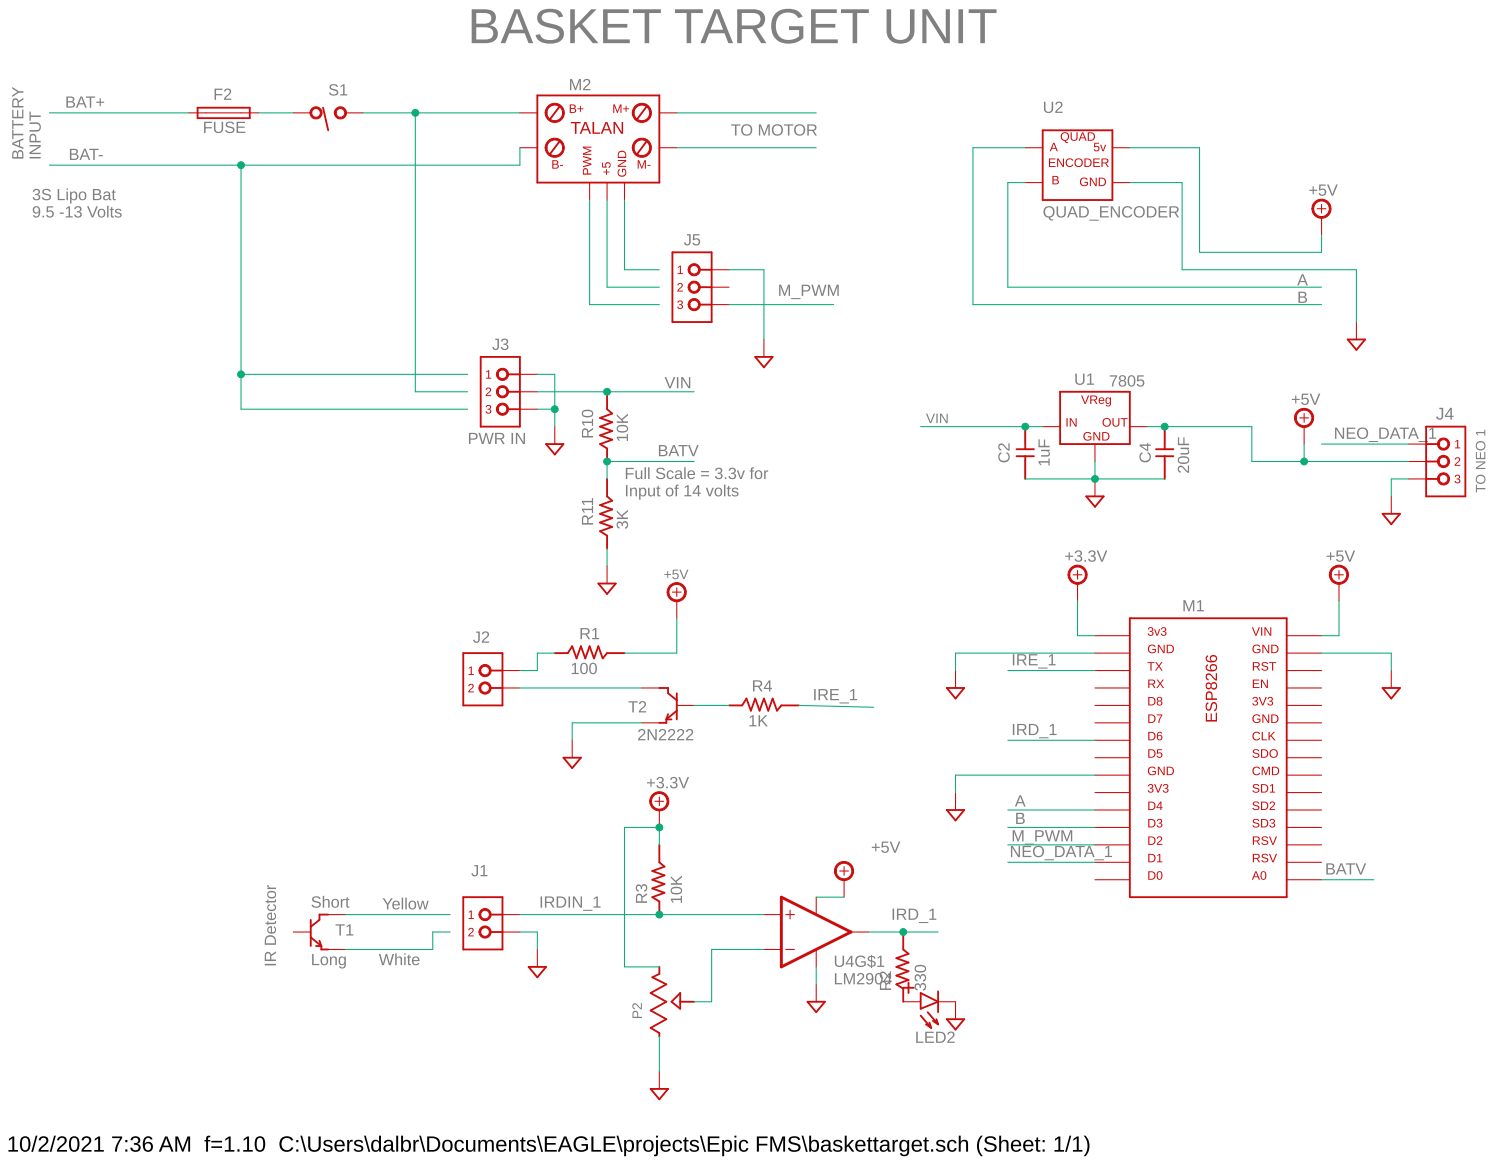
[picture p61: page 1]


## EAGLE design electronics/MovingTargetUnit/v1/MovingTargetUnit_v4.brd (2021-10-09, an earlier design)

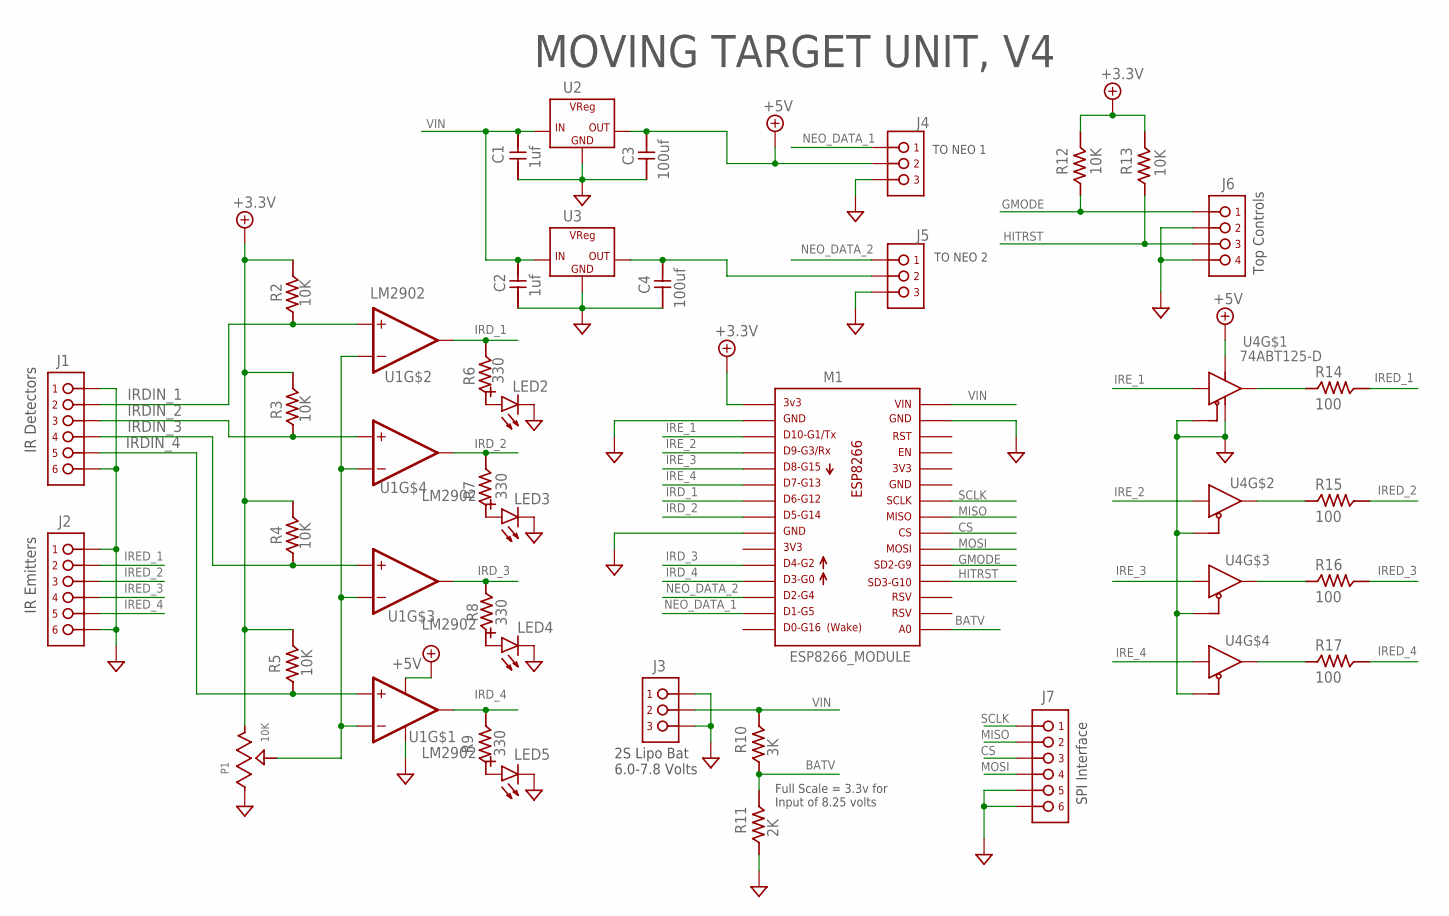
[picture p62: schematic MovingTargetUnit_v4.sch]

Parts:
C1, C2: 1uf; C1206
C3, C4: 100uf; C1206
J1, J2, J7: PINHDR_1X6-JST; JST-XH_098_VERT_1X6
J3, J4, J5: PINHDR_1X3XH-JST; JST-XH_098_VERT_1X3
J6: PINHDR_1X4-JST; JST-XH_098_VERT_1X4
LED2, LED3, LED4, LED5: LED1206; LED_1206
M1: ESP8266_MODULE
P1: 10K; TRIMPOT_3361P
R2, R3, R4, R5, R12, R13: 10K; R1206
R6, R7, R8, R9: 330; R1206
R10: 3K; R1206
R11: 2K; R1206
R14, R15, R16, R17: 100; R1206
U1: LM2902; SO16LNB-14PIN
U2, U3: VREG-3L7805CDT; TO252-3
U4: 74ABT125-D; SO16LNB-14PIN

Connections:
+3.3V: M1.P$1, P1.3, R2.P$2 (2), R3.P$2 (2), R4.P$2 (2), R5.P$2 (2), R12.P$2 (2), R13.P$2 (2)
+5V: C3.P$2 (2), J4.2, U1.P$4 (P+), U2.3 (OUT), U4.P$14 (VCC)
BATV: M1.P$16, R10.P$1 (1), R11.P$2 (2)
CS: J7.4 (3), M1.P$22
GMODE: J6.1, M1.P$20, R12.P$1 (1)
GND: C1.P$1 (1), C2.P$1 (1), C3.P$1 (1), C4.P$1 (1), J1.1 (6), J1.6 (1), J2.1 (6), J2.6 (1), J3.1 (3), J3.3 (1), J4.1 (3), J5.1 (3), J6.2, J6.4, J7.1 (6), J7.2 (5), LED2.CATHODE(-) (CATHODE), LED3.CATHODE(-) (CATHODE), LED4.CATHODE(-) (CATHODE), LED5.CATHODE(-) (CATHODE), M1.P$2, M1.P$9, M1.P$29, P1.1, R11.P$1 (1), U1.P$11 (P-), U2.FIN (GND), U3.FIN (GND), U4.P$1 (OE), U4.P$4 (OE), U4.P$7 (GND), U4.P$10 (OE), U4.P$13 (OE)
HITRST: J6.3, M1.P$19, R13.P$1 (1)
IRDIN_1: J1.5 (2), R2.P$1 (1), U1.P$5 (+IN)
IRDIN_2: J1.4 (3), R3.P$1 (1), U1.P$12 (+IN)
IRDIN_3: J1.3 (4), R4.P$1 (1), U1.P$10 (+IN)
IRDIN_4: J1.2 (5), R5.P$1 (1), U1.P$3 (+IN)
IRD_1: M1.P$7, R6.P$2 (2), U1.P$7 (OUT)
IRD_2: M1.P$8, R7.P$2 (2), U1.P$14 (OUT)
IRD_3: M1.P$11, R8.P$1 (1), U1.P$8 (OUT)
IRD_4: M1.P$12, R9.P$2 (2), U1.P$1 (OUT)
IREDD_1: R14.P$1 (1), U4.P$3 (OUT)
IREDD_2: R15.P$1 (1), U4.P$6 (OUT)
IREDD_3: R16.P$1 (1), U4.P$8 (OUT)
IREDD_4: R17.P$1 (1), U4.P$11 (OUT)
IRED_1: J2.5 (2), R14.P$2 (2)
IRED_2: J2.4 (3), R15.P$2 (2)
IRED_3: J2.3 (4), R16.P$2 (2)
IRED_4: J2.2 (5), R17.P$2 (2)
IRE_1: M1.P$3, U4.P$2 (IN)
IRE_2: M1.P$4, U4.P$5 (IN)
IRE_3: M1.P$5, U4.P$9 (IN)
IRE_4: M1.P$6, U4.P$12 (IN)
MISO: J7.5 (2), M1.P$23
MOSI: J7.3 (4), M1.P$21
unnamed: LED3.ANODE(+) (ANODE), R7.P$1 (1)
unnamed: LED2.ANODE(+) (ANODE), R6.P$1 (1)
unnamed: LED4.ANODE(+) (ANODE), R8.P$2 (2)
unnamed: LED5.ANODE(+) (ANODE), R9.P$1 (1)
unnamed: P1.2, U1.P$2 (-IN), U1.P$6 (-IN), U1.P$9 (-IN), U1.P$13 (-IN)
unnamed: C4.P$2 (2), J5.2, U3.3 (OUT)
NEO_DATA_1: J4.3 (1), M1.P$14
NEO_DATA_2: J5.3 (1), M1.P$13
SCLK: J7.6 (1), M1.P$24
VIN: C1.P$2 (2), C2.P$2 (2), J3.2, M1.P$30, R10.P$2 (2), U2.1 (IN), U3.1 (IN)

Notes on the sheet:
TO NEO 1
MOVING TARGET UNIT, V4
TO NEO 2
2S Lipo Bat 6.0-7.8 Volts
Full Scale = 3.3v for Input of 8.25 volts
Top Controls
SPI Interface
IR Detectors
IR Emitters

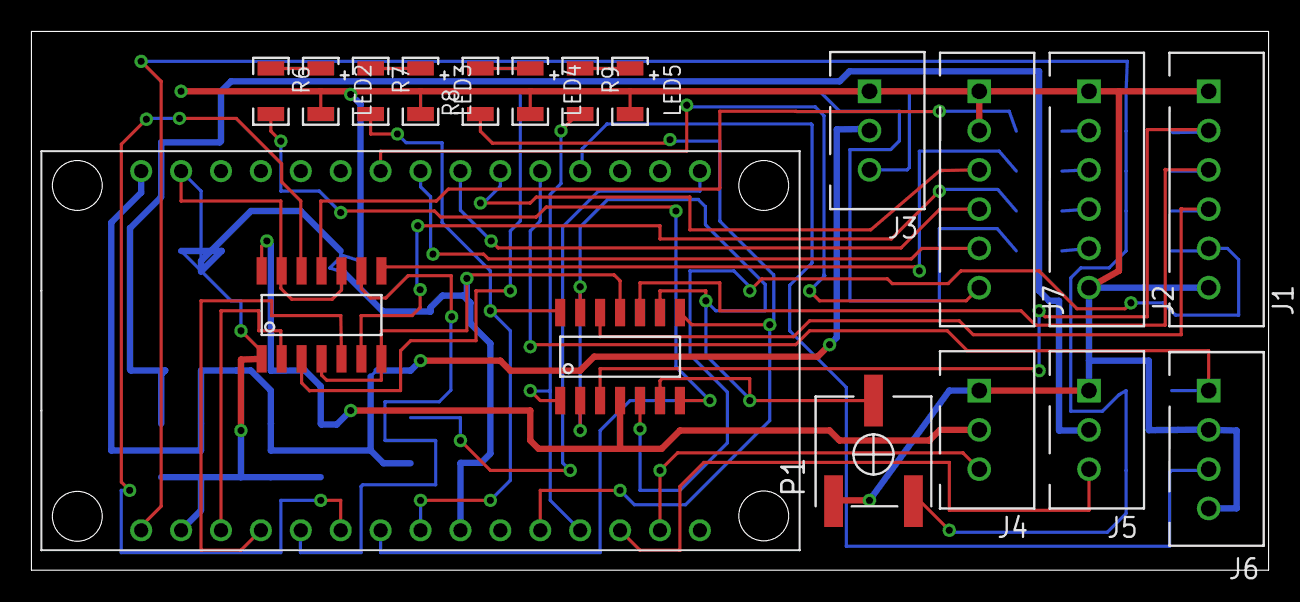
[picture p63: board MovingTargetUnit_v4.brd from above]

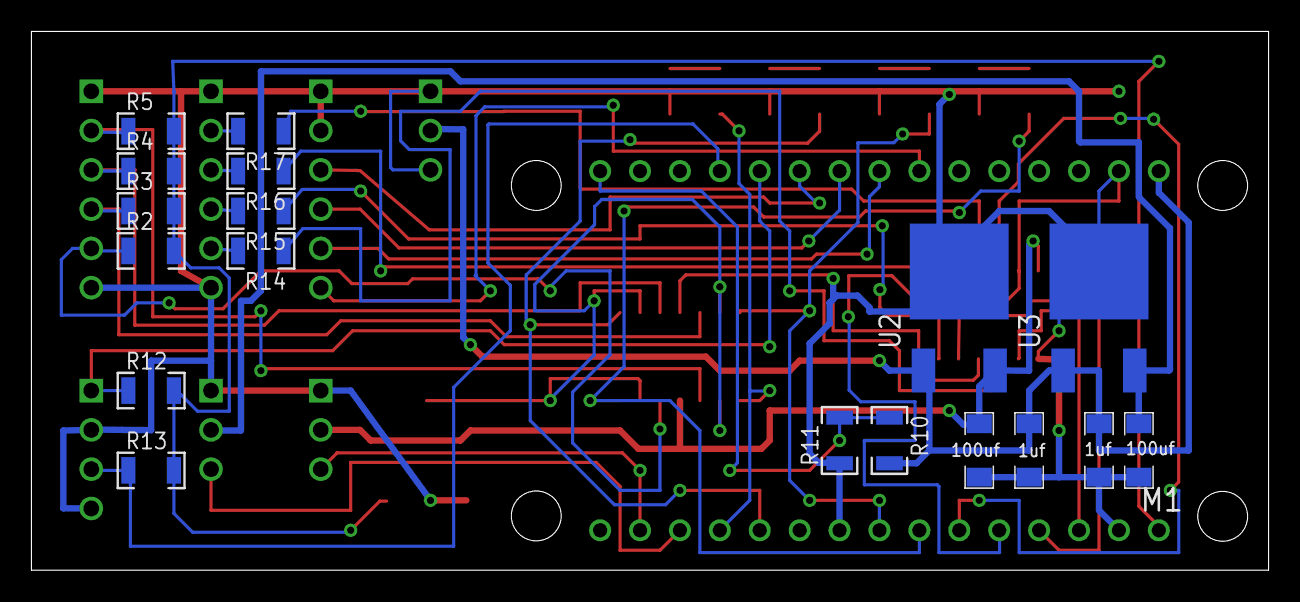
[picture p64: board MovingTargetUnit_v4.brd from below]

Board: 2 copper layers, 78.7 x 34.3 mm, 37 parts (18 on the bottom side), 39 nets.

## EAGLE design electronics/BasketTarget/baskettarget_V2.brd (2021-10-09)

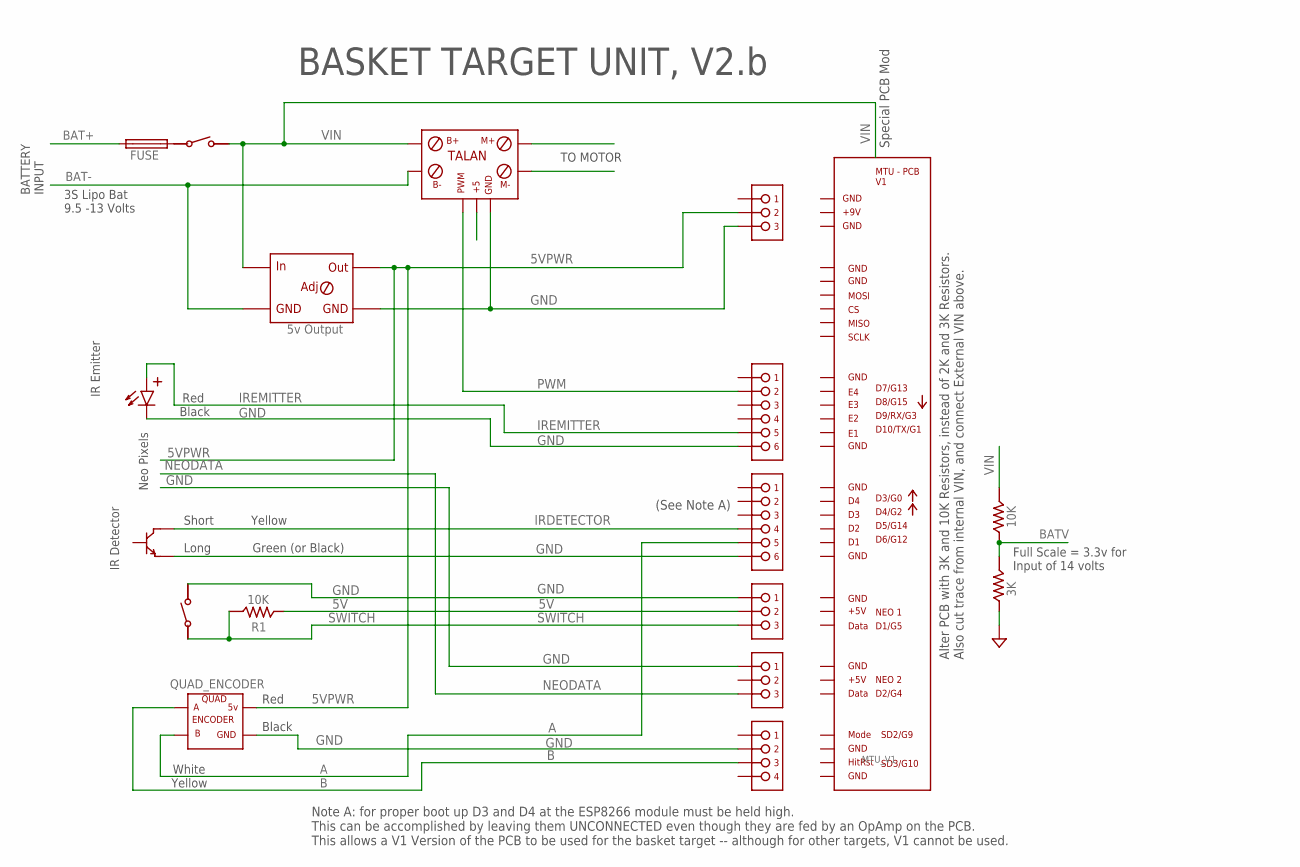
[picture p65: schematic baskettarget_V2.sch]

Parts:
F2: FUSE; FUSE_HOLDER_WICKMANN-19596
J1: ENCODER; PINHDR_TH_100_1X4
J2: NEO; PINHDR_TH_100_1X3
J4: INPUTS; PINHDR_TH_100_1X6
J6: OUTPUTS; PINHDR_TH_100_1X6
J7: PWR; PINHDR_TH_100_1X3
J10: SERVO; PINHDR_TH_100_1X3
LED1: IR Emitter; LED-TH100
M1: MTU_V1
M2: TALAN; TALAN_PWM
M4: 5v Output; DC_DC_MODULE
R1, R10: 10K; R300
R11: 3K; R300
S1, S2: TOGGLE_SPST; SPST_TOGGLE
T1: T_NPN; TO-92
U2: QUAD_ENCODER

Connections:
5V: J2.2, R1.P$1 (1)
5VPWR: J7.2, M4.OUT+ (OUT), U2.5V
A: J4.5, U2.B
B: J1.3, U2.A
BAT+: F2.A (1)
BAT-: M2.B-, M4.IN- (G1)
BATV: R10.P$1 (1), R11.P$2 (2)
GND: J1.2, J2.1, J4.6, J6.6, J7.3, J10.1, LED1.P$2 (CATHODE), M2.GND, M4.OUT- (G2), R11.P$1 (1), S1.P$2, T1.P$3 (EMITTER), U2.GND
IRDETECTOR: J4.4, T1.P$1 (COLLECTOR)
IREMITTER: J6.5, LED1.P$1 (ANODE)
unnamed: F2.B (2), S2.P$1
NEODATA: J10.3
PWM: J6.2, M2.PWM
SWITCH: J2.3, R1.P$2 (2), S1.P$1
VIN: M2.B+, M4.IN+ (IN), R10.P$2 (2), S2.P$2

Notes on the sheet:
BASKET TARGET UNIT, V2.b
3S Lipo Bat 9.5 -13 Volts
Full Scale = 3.3v for Input of 14 volts
IR Detector
Long
Short
Yellow
Green (or Black)
BATTERY INPUT
TO MOTOR
Red
Black
Neo Pixels
IR Emitter
Special PCB Mod
Alter PCB with 3K and 10K Resistors, instead of 2K and 3K Resistors. Also cut trace from internal VIN, and connect External VIN above.
Note A: for proper boot up D3 and D4 at the ESP8266 module must be held high. This can be accomplished by leaving them UNCONNECTED even though they are fed by an OpAmp on the PCB. This allows a V1 Version of the PCB to be used for the basket target -- although for other targets, V1 cannot be used.
White
(See Note A)

Board: 2 copper layers, 18 parts (0 on the bottom side), 13 nets, no tracks yet.

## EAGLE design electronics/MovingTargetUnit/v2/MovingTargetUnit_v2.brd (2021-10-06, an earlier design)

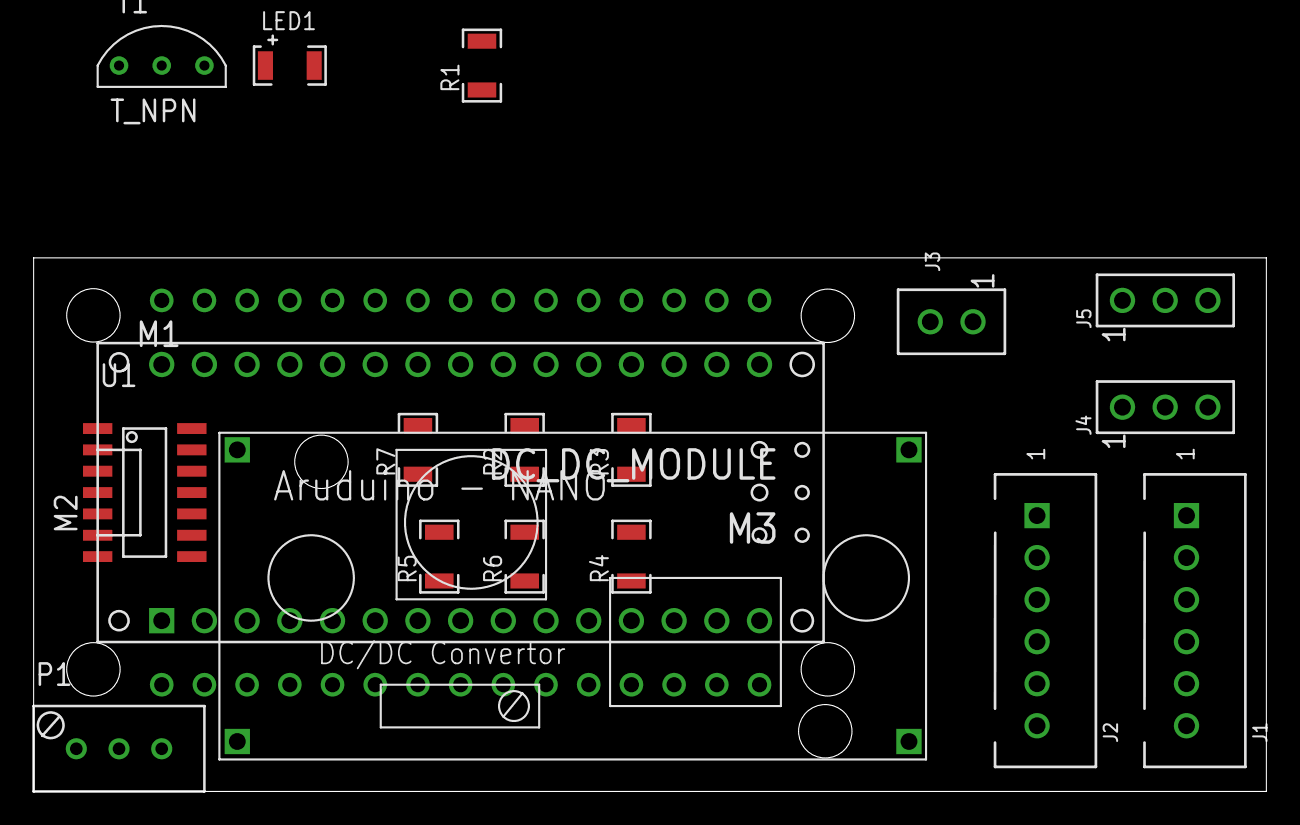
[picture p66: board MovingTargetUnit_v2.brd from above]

Board: 2 copper layers, 73.3 x 31.7 mm, 19 parts (1 on the bottom side), 26 nets, no tracks yet.

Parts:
J1, J2: PINHDR_1X6-XH; JST-XH_098_VERT_1X6
J3: PINHDR_1X2-100; PINHDR_TH_100_1X2
J4, J5: PINHDR_1X3-100; PINHDR_TH_100_1X3
LED1: IR Emitter LED; LED_1206
M1: ESP8266_MODULE
M2: ARDUINO-NANO
M3: DC_DC_MODULE
P1: 10K; TRIMPOT_SIP_100
R1: 100; R1206
R2: 3K; R1206
R3: 2K; R1206
R4, R5, R6, R7: 10K; R1206
T1: T_NPN; TO-92
U1: SO16LNB-14PIN

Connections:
+5V: M2.5V, P1.P$3, R4.P$2, R5.P$2, R6.P$2, R7.P$2, U1.P$4
BATV: M1.P$16, M2.A0, R2.P$1, R3.P$2
GND: J1.1, J1.2, J2.1, J2.2, J3.2, J4.3, J5.3, LED1.CATHODE(-), M1.P$2, M1.P$9, M1.P$25, M1.P$29, M2.GND, M2.GND2, M3.IN-, M3.OUT-, P1.P$1, R3.P$1, T1.P$3, U1.P$11
IRD_1: M2.D4, U1.P$7
IRD_2: M2.D5, U1.P$14
IRD_3: M2.D6, U1.P$8
IRD_4: M2.D7, U1.P$1
IRE_1: J2.6, M2.D2
IRE_2: J2.5, M2.D3
IRE_3: J2.4, M2.D8
IRE_4: J2.3, M2.D9
unnamed: M2.3.3, M2.REF
unnamed: J1.6, R4.P$1, U1.P$5
unnamed: J1.5, R5.P$1, U1.P$12
unnamed: J1.4, R6.P$1, U1.P$10
unnamed: J1.3, R7.P$1, U1.P$3
unnamed: LED1.ANODE(+), R1.P$1
unnamed: P1.P$2, U1.P$2, U1.P$6, U1.P$9, U1.P$13
NEO_DATA_1: J4.1, M1.P$14
NEO_DATA_2: J5.1, M1.P$15
NEO_PWR: J4.2, J5.2, M3.OUT+
SPI_CLK: M1.P$8, M2.D13
SPI_CS: M1.P$5, M2.D10
SPI_MISO: M1.P$7, M2.D12
SPI_MOSI: M1.P$6, M2.D11
VIN: J3.1, M1.P$30, M2.VIN, M3.IN+, R2.P$2

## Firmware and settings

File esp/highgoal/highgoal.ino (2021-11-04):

// highgoal.ino -- Sketch for a High Goal Target (Baseket Target)
// Epic Robotz, dlb, Oct 2021

// This sketch is intended to run in a ESP8266 that resides in
// the High Goal, otherwise known as the Basket Target.

// Note, this game piece is not wired like the others, and the
// circuit as been altered to do different things, mainly to
// control the motor, and sense if the motor is operating 
// correctly.  That is, this code does the following:
//
//  1. Counts balls, with ONE IR beam
//  2. Provides PWM to control the speed of the mixer motor
//  3. Reads a quadurature encoder to sense speed of the motor
//  4. Controls ONE strip of Neo Pixels
//  5. Reads the outside battery voltage
//  6. Communicates with the EpicFMS server to give status
//     and take directions for a whole host of parameters.
//
// NOTE -- This sketch runs on a MODIFIED version  of the PCB
// boards.  Beware! See below for pin assignments.

#include <Arduino.h>
#include <EpicFmsLib.h>
#include <EEPROM.h>

#define WIFISSID "epicfms"
#define WIFIPK  "epic4fms"

// // Special Setup for the Modified Basket Target running
// // on a V1 of the PCB
// #define PIN_NONE    -1  // Means no pin assigned.
// #define PIN_NEO      4  // D2/G4 -- On NEO2 Header -- 
// #define PIN_IRE     15  // 1  // D10/TX/G1 -- IR Emitter
// #define PIN_GMODE    5  // D1/G5 -- On NEO1 Header --
// #define PIN_PWM     13  // D7/G13 -- PWM via 74125 buffer
// #define PIN_IRD     14  // D5/G14 -- IR Detector 
// #define PIN_A       12  // D6/G12 -- Via OpAmp 
// #define PIN_B       10  // SD3/G10 -- Direct input
// #define NPIXELS 42

// Setup for the Modified Basket Target running
// on a modified V2/V3 version of the PCB 
#define PIN_NONE    -1  // Means no pin assigned.
#define PIN_PWM      5  // D1/G5 -- On NEO1 Header (via 74125 buffer)
#define PIN_NEO      4  // D2/G4 -- On NEO2 Header (via 74125 buffer)
#define PIN_IRE     15  // D8/G15 -- IR Emitter
#define PIN_IRD     12  // D6/G12 -- IR Detector 
#define PIN_A       13  // D7/G13  -- Modified Direct input, via mod 
#define PIN_B       10  // SD3/G10 -- Direct input, Was HitRst button before mod
#define PIN_GMODE   14  // D5/G14  -- Input via OpAmp
#define NPIXELS 43

#define VOLTSPERLSB 0.013 // Volts per bit on analog sensor for V-Battery
#define SW_RUN LOW      // Defines how the switch is used, High=Run 
#define SW_OFFLINE HIGH // Defines how the switch is used, Low=offline  
#define SW_UNDEFINED -1 // Use when the condition of the switch is not known

// Definations for On-board LED.  
#define PIN_ONBOARDLED 16
#define LED_OFF HIGH
#define LED_ON LOW

NeoBasket neopixels(PIN_NEO, PIN_NONE, NPIXELS, NPIXELS);
BasketMotor bmotor(PIN_PWM, PIN_A, PIN_B);
HitDetector hitdetector(PIN_IRE, PIN_IRD);
EpicFmsWiFi fmswifi(WIFISSID, WIFIPK, "Basket Target");

char lineout[100];
unsigned long last_report_time = millis();
int mode = SW_OFFLINE; // Set by switch, updated on main loop.
int lastmode = SW_UNDEFINED;
float vbattery = 0.0;  // Voltage reading on battery -- updated once per 0.5 sec//
unsigned long last_battery_udpate_time = millis();
uint32_t last_led_update_time = millis();
int led_cycle = 0;
long report_count = 0;
long cmd_count = 0;
long mainloop_count = 0;
int game_mode = GMODE_PWRUP;
int fms_game_mode = GMODE_STANDBY;
Cmdargs cmd_args;

void setup(void) {
  Serial.begin(115200);
  for(int i = 0; i < 10; i++) { Serial.println("."); delay(200);}
  delay(500);
  Serial.println(" ");  
  Serial.println("Epic Game Slave Device For Basket Target.");
  Serial.println("Version 0.5, Oct 2021.");
  Serial.println(" ");

  Serial.println("Loading EEPROM configuration.");
  EEPROM.begin(128);  // We are allocating 128 bytes of EEPROM here.
  load_config();

  Serial.println("Setting up Neo pixels.");
  neopixels.begin();
 
  Serial.println("Setting up wifi.");
  fmswifi.set_oncommand(on_command);
  fmswifi.set_onstatus(on_status);
  fmswifi.begin();

  delay(100);
  Serial.println("Setting up the hit detector.");
  hitdetector.begin();

  Serial.println("Setting up Run Mode switch.");
  pinMode(PIN_GMODE, INPUT);

  Serial.println("Setting up motor.");
  bmotor.begin();
  bmotor.disable();

  Serial.println("Setting up on-board LED.");
  pinMode(PIN_ONBOARDLED, OUTPUT);
  digitalWrite(PIN_ONBOARDLED, LED_OFF);

  Serial.println("Setup Done -- Starting Main Loop.");
}

// Reads the Battery Voltage
void battery_update(void) {
  if (millis() - last_battery_udpate_time < 500) return;
  last_battery_udpate_time = millis();
  int ir = analogRead(A0);
  vbattery = ir * VOLTSPERLSB;
}

// Prepare data for neo leds.
void update_neo() {
  Neo_Basket_Params p;
  p.game_mode = game_mode;
  p.online = (mode == SW_RUN);
  p.hiterror = (hitdetector.get_status() == HDSTATUS_ERROR);
  p.stuck = bmotor.isstuck();
  p.jerking = bmotor.injam();
  p.jamcount = bmotor.jamcount(); 
  long encoder_ticks = bmotor.encoderpos();
  long nrevs_ticks = (encoder_ticks >> 10) * 1024; 
  p.revs = float(encoder_ticks - nrevs_ticks) / 1024.0;
  p.hitcount = hitdetector.value();
  neopixels.set_params(&p);
  neopixels.update(game_mode);
}

// Here, we determine the game-mode that we think we should use.
void update_game_mode() {
    if (hitdetector.get_status() == HDSTATUS_INSELFTEST) {
        game_mode = GMODE_PWRUP;
        return;
    }
    if (hitdetector.get_status() == HDSTATUS_ERROR) {
        game_mode = GMODE_UNITERR;
        return;
    }
    if (bmotor.isstuck()) {
        game_mode = GMODE_UNITERR;
        return;
    }
    if (mode == SW_OFFLINE) {
        game_mode = GMODE_PRACTICE;
        return;
    }
    if (fmswifi.infailure()) {
        game_mode = GMODE_FMSLOST;
        return;
    }
    if (!fmswifi.is_connected()) {
        game_mode = GMODE_WAITFORWIFI;
        return;
    }
    game_mode = fms_game_mode;
}

// Update the on-board led according to state
void led_update(void) {
    uint32_t tnow = millis();
    if(tnow - last_led_update_time < 50) return;
    last_led_update_time = tnow;
    if (hitdetector.get_status() == HDSTATUS_ERROR) {
        if (led_cycle > 0) {
            digitalWrite(PIN_ONBOARDLED, LED_ON);
            led_cycle = 0;
        } else {
            digitalWrite(PIN_ONBOARDLED, LED_OFF);
            led_cycle = 1;
        }
        return;
    }
    if (!fmswifi.is_connected()) {
        if (led_cycle < 20) digitalWrite(PIN_ONBOARDLED, LED_ON);
        else digitalWrite(PIN_ONBOARDLED, LED_OFF);
        led_cycle++;
        if(led_cycle > 40) led_cycle = 0; 
        return;
    }
    // All seems okay.
    digitalWrite(PIN_ONBOARDLED, LED_ON);
    return;
}

// Reports status to terminal
void send_report(void) {
  if(millis() - last_report_time < 1000) return;
  last_report_time = millis();
  report_count++;
  Serial.println("");
  const char *swout;
  if (mode == SW_RUN) swout = "Run";
  else swout = "Offline";
  sprintf(lineout, "%ld ***** Battery Voltage=%6.1f, Sw=%s, GMode=%s", 
    report_count, vbattery, swout, gmode_to_str(game_mode));
  Serial.println(lineout);
  fmswifi.debug_report();
  bmotor.debug_report();
  hitdetector.debug_report();
  int a = digitalRead(PIN_A);
  int b = digitalRead(PIN_B);
  sprintf(lineout, "Encoder A,B= %d,%d", a, b);
  Serial.println(lineout);
}

void loop() {
  mainloop_count++;
  static int lastmode = SW_UNDEFINED;
  mode = digitalRead(PIN_GMODE);
  if (mode != lastmode) { 
   lastmode = mode;
   if (mode == SW_OFFLINE) {
       hitdetector.start_selftest(); // Start with clearing errors.
       if (vbattery > 8.0) bmotor.enable();  // Run the motor in offline.
   } else {
     bmotor.disable(); // For now.  Later, the server will take care of this.
   }
  }  
  battery_update();
  led_update();
  bmotor.update();
  hitdetector.update();
  update_game_mode();
  update_neo();
  fmswifi.set_hitcount(hitdetector.value());  
  fmswifi.update();
  send_report();
}  

#define EPICFMS_SIGNATURE 1324214  // Some random number...
typedef struct configuration {
  uint32_t signature;
  int run_pwm;
} Configuration;

// Save important configuration parameters to EEPROM
void save_config() {
  Configuration cc;
  cc.signature = EPICFMS_SIGNATURE;
  cc.run_pwm = bmotor.runpwm();
  EEPROM.put(64, cc);
  EEPROM.commit();
  Serial.println("EEPROM configuration saved.");
}

// Loads the configuation from EEPROM.
void load_config() {
  Configuration cc;
  EEPROM.get(64, cc);
  if (cc.signature != EPICFMS_SIGNATURE) {
    Serial.println("EEPROM not initialized. Loading Defaults");
    cc.run_pwm = PW_RUN0;
  } else {
    Serial.println("EEPROM configuration loaded successfully.");
  }
  bmotor.setpwm(cc.run_pwm);
}

// Process commands from EpicFms server here.
void on_command(Cmdargs *args) {
  cmd_count++;
  sprintf(lineout, "Command Recevied from EpicFms server! %ld", cmd_count);
  Serial.println(lineout);
  int nargs = args->ncount;
  for(int i = 0; i < nargs; i++) {
    process_cmd(args->names[i], args->values[i]);
  }
}

void process_cmd(const char *name, const char *value) {
  int iv = atoi(value);
  atoi(value);
  if(strcmp(name, "motor") == 0) {
    if (mode == SW_RUN && iv != 1) {
      bmotor.disable();
    }
    if (mode == SW_RUN && iv == 1 && vbattery > 9.0) {
      bmotor.enable();
    }
    return;
  }
  if(strcmp(name, "pwm") == 0) {
    if (iv != 0) {
      bmotor.setpwm(iv);
    }
    return;
  }
  if(strcmp(name, "gamemode") == 0) {
    if(iv == 0) {
      iv = str_to_gmode(value);
    }
    if(iv != 0) fms_game_mode = iv;
    return;
  }
  if(strcmp(name, "saveconfig") == 0) {
    if (iv != 1) return;
    save_config();
  }
  if(strcmp(name, "selftest") == 0) {
    if (iv != 1 || mode != SW_RUN) return;
    hitdetector.start_selftest();
  }
    if(strcmp(name, "resethits") == 0) {
    if (iv != 1) return;
    Serial.println("Reseting Hit Count.");
    hitdetector.reset_hits();
    return;
  }
  if(strcmp(name, "set_emitters") == 0) {
    hitdetector.set_emitter(iv);
  }
}

// Process status requests from the server here.
void on_status(char *json) {
  char lineout[100];
  strncpy(json, "{\n", MAX_STATUS_CHARS);
  
  sprintf(lineout, "\"unit\" : \"basket\", \n");
  strncat(json, lineout, MAX_STATUS_CHARS);

  sprintf(lineout, "\"switch\" : \"%s\", \n", mode == SW_OFFLINE ? "Offline" : "Game");
  strncat(json, lineout, MAX_STATUS_CHARS);

  sprintf(lineout, "\"gamemode\" : \"%s\", \n", gmode_to_str(game_mode));
  strncat(json, lineout, MAX_STATUS_CHARS);

  sprintf(lineout, "\"mainloop_count\" : %ld, \n", mainloop_count);
  strncat(json, lineout, MAX_STATUS_CHARS);

  sprintf(lineout, "\"command_count\" : %ld, \n", cmd_count);
  strncat(json, lineout, MAX_STATUS_CHARS);

  sprintf(lineout, "\"hits\" : %ld, \n", hitdetector.value());
  strncat(json, lineout, MAX_STATUS_CHARS);

  sprintf(lineout, "\"motor_enabled\" : %d, \n", bmotor.isenabled());
  strncat(json, lineout, MAX_STATUS_CHARS);

  sprintf(lineout, "\"in_jam\" : %d, \n", bmotor.injam());
  strncat(json, lineout, MAX_STATUS_CHARS);

  sprintf(lineout, "\"jam_count\" : %ld, \n", bmotor.jamcount());
  strncat(json, lineout, MAX_STATUS_CHARS);

  sprintf(lineout, "\"stuck\" : %d, \n", bmotor.isstuck());
  strncat(json, lineout, MAX_STATUS_CHARS);

  sprintf(lineout, "\"rpm\" : %8.2f, \n", bmotor.currentrpm());
  strncat(json, lineout, MAX_STATUS_CHARS);

  sprintf(lineout, "\"pwm\" : %d, \n", bmotor.currentpwm());
  strncat(json, lineout, MAX_STATUS_CHARS);

  sprintf(lineout, "\"run_pwm\" : %d, \n", bmotor.runpwm());
  strncat(json, lineout, MAX_STATUS_CHARS);

  sprintf(lineout, "\"encoder\" : %ld, \n", bmotor.encoderpos());
  strncat(json, lineout, MAX_STATUS_CHARS);

  sprintf(lineout, "\"hitdetector_status\" : \"%s\", \n", hitdetector.get_status_str());
  strncat(json, lineout, MAX_STATUS_CHARS);

  sprintf(lineout, "\"batvolts\" : %8.2f, \n", vbattery);
  strncat(json, lineout, MAX_STATUS_CHARS);

  sprintf(lineout, "\"irbeam\" : \"%d:%d\"\n", hitdetector.get_emitter(), hitdetector.get_detector());
  strncat(json, lineout, MAX_STATUS_CHARS);

  strncat(json, "}\n", MAX_STATUS_CHARS);
}

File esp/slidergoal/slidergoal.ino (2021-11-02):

// slidergoal.ino -- Sketch for a Slider Goal 
// Epic Robotz, dlb, Oct 2021
//
// *** WIFI Version of Slider Goal ***
//
// This sketch is intended to run in a ESP8266 mounted on a
// V2 version of the PCB that has been modified to to the V3
// circuit. Please see PCB_Log.md for more information about
// V3.
//
// A Slider Goal has 4 IR beam sensors each with an individual
// IR emitter and an IR detector.  It also has a servo that
// opens and shuts a sliding door. 
//
// This code does the following:
//
//  1. Counts balls, with the combined 4 IR beams
//  2. Provides PWM to control the position of the door via the servo.
//  5. Reads the outside battery voltage
//  6. Communicates with the EpicFMS server to give status
//     and take directions for a whole host of parameters.
//
// One feature of this code is that the calibration settings for
// open and close are contained in EEPROM and can be set 
// over the air with commands from EpicFMS.

// Since the Slider Target does not have NEO leds attached, the
// on board LED is used to indicate status:
//
//   Fast Blink = Error in IR Detectors
//   Slow Blink = Waiting for WiFi 
//   ON         = Connected, no error
//   Off        = Undefined -- probably programming error.

#include <Arduino.h>
#include <EpicFmsLib.h>
#include <EEPROM.h>
#include <servo.h>

#define WIFISSID "epicfms"
#define WIFIPK  "epic4fms"

// Setup for V3 of the PCB:
#define PIN_NONE    -1  // Means no pin assigned.
#define PIN_HRST    16  // D0/G16 -- push button with pullup
#define PIN_SERVO    5  // D1/G5 -- Servo PWM
#define PIN_IRD2     4  // D2/G4 -- Takes over NEO2!
#define PIN_IRE4     0  // D3/G0 -- IR Emitter via buffer
#define PIN_IRE3     2  // D4/G2 -- IR Emitter via buffer
#define PIN_IRD4    14  // D5/G14 -- IR Detector via OpAmp
#define PIN_IRD3    12  // D6/G12 -- IR Detector via OpAmp
#define PIN_IRE2    13  // D7/G13 -- IR Emitter via butter
#define PIN_IRE1    15  // D8/G15 -- IR Emitter via buffer
#define PIN_IRD1    10  // SD3/G10 -- IR Detector via OpAmp
#define PIN_GMODE    9  // SD2/G9  -- Switch with pullup

// Definations for On-board LED.  Note that this
// conflicts with PIN_HRST.  Do not use PIN_HRST on the
// slider!!
#define PIN_ONBOARDLED 16
#define LED_OFF HIGH
#define LED_ON LOW

// Define Servo parameters
#define PW_CLOSE   1700   // Default PW for closed
#define PW_OPEN    1300   // Default PW for opened
#define PW_CENTER  1500   // Known approx center
#define SLIDER_CLOSED    0   // Slider set for door closed
#define SLIDER_CENTER    1   // Slider set for center (used for calibration)
#define SLIDER_OPEN      2   // Slider set for door opened
#define SLIDER_UNKNOWN  -1   // Indicates slider in an unknown condition

// Battery parameters
#define VOLTSPERLSB 0.013 // Volts per bit on analog sensor for V-Battery

// Switch parameters -- not currently used but kept for future
#define SW_RUN LOW      // Defines how the switch is used, High=Run 
#define SW_OFFLINE HIGH // Defines how the switch is used, Low=offline  
#define SW_UNDEFINED -1 // Use when the condition of the switch is not known

Servo servo;
HitDetector4 hitdetector(PIN_IRE1, PIN_IRE2, PIN_IRE3, PIN_IRE4, PIN_IRD1, PIN_IRD2, PIN_IRD3, PIN_IRD4);
EpicFmsWiFi fmswifi(WIFISSID, WIFIPK, "Slider Target");

char lineout[100];
uint32_t last_report_time = millis();
float vbattery = 0.0;  // Voltage reading on battery -- updated once per 0.5 sec//
uint32_t last_battery_udpate_time = millis();
uint32_t last_led_update_time = millis();
int led_cycle = 0;
long report_count = 0;
long cmd_count = 0;
long mainloop_count = 0;
int game_mode = GMODE_PWRUP;
int fms_game_mode = GMODE_STANDBY;
int slider = SLIDER_UNKNOWN;
int pw_open = PW_OPEN;
int pw_close = PW_CLOSE;
int pw_last = 0;
Cmdargs cmd_args;

void setup(void) {
  Serial.begin(115200);
  for(int i = 0; i < 10; i++) { Serial.println("."); delay(200);}
  delay(2000);
  Serial.println(" ");  
  Serial.println("Epic Game Slave Device For Slider Target.");
  Serial.println("Should be running on PCB V2 modified to V3.");
  Serial.println("Version 1.0, Oct 2021.");
  Serial.println(" ");

  Serial.println("Loading EEPROM configuration.");
  EEPROM.begin(128);  // We are allocating 128 bytes of EEPROM here.
  load_config();

  Serial.println("Setting up wifi.");
  fmswifi.set_oncommand(on_command);
  fmswifi.set_onstatus(on_status);
  fmswifi.begin();

  Serial.println("Setting up servo.");
  servo.attach(PIN_SERVO, 600, 2400);
  servo.writeMicroseconds(PW_CENTER);
  pw_last = PW_CENTER;
  slider = SLIDER_CENTER;

  Serial.println("Setting up on-board LED.");
  pinMode(PIN_ONBOARDLED, OUTPUT);
  digitalWrite(PIN_ONBOARDLED, LED_OFF);

  delay(100);
  Serial.println("Setting up the hit detector.");
  hitdetector.begin();

  Serial.println("Setting up Run Mode switch.");
  pinMode(PIN_GMODE, INPUT);

  Serial.println("Setup Done -- Starting Main Loop.");
}

// Reads the Battery Voltage
void battery_update(void) {
  if (millis() - last_battery_udpate_time < 500) return;
  last_battery_udpate_time = millis();
  int ir = analogRead(A0);
  vbattery = ir * VOLTSPERLSB;
}

// Here, we determine the game-mode that we think we should use.
void update_game_mode() {
    if (hitdetector.get_status() == HDSTATUS_INSELFTEST) {
        game_mode = GMODE_PWRUP;
        return;
    }
    if (hitdetector.get_status() == HDSTATUS_ERROR) {
        game_mode = GMODE_UNITERR;
        return;
    }
    if (fmswifi.infailure()) {
        game_mode = GMODE_FMSLOST;
        return;
    }
    if (!fmswifi.is_connected()) {
        game_mode = GMODE_WAITFORWIFI;
        return;
    }
    game_mode = fms_game_mode;
}

// Update the on-board led according to state
void led_update(void) {
    uint32_t tnow = millis();
    if(tnow - last_led_update_time < 50) return;
    last_led_update_time = tnow;
    if (hitdetector.get_status() == HDSTATUS_ERROR) {
        if (led_cycle > 0) {
            digitalWrite(PIN_ONBOARDLED, LED_ON);
            led_cycle = 0;
        } else {
            digitalWrite(PIN_ONBOARDLED, LED_OFF);
            led_cycle = 1;
        }
        return;
    }
    if (!fmswifi.is_connected()) {
        if (led_cycle < 20) digitalWrite(PIN_ONBOARDLED, LED_ON);
        else digitalWrite(PIN_ONBOARDLED, LED_OFF);
        led_cycle++;
        if(led_cycle > 40) led_cycle = 0; 
        return;
    }
    // All seems okay.
    digitalWrite(PIN_ONBOARDLED, LED_ON);
    return;
}

// Set the door position.
void slider_set(int place) {
    slider = place;
    slider_update();
}

// Update slider if we need to change pwm, or handle
// slow movement in the future.
void slider_update() {
    int pw = PW_CENTER;
    switch(slider) {
        case SLIDER_OPEN: pw = pw_open; break;
        case SLIDER_CLOSED: pw = pw_close; break;
        case SLIDER_CENTER: pw = PW_CENTER; break;
    }
    if (pw != pw_last) {
        pw_last = pw;
        servo.writeMicroseconds(pw);
    }
}
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

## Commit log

2021-09-21 SPI working
2021-09-25 Submit PCB for Moving Target Unit
    [MovingTargetUnit.sch, MovingTargetUnit_v4.brd, MovingTargetUnit_v4.sch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]
2021-10-02 some work on electronics
    [RingCounter.sch, SlidingTargetUnit.sch, baskettarget.brd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]
2021-10-05 V1 of PCB working
    [M21-GP-0001.SLDASM, M21-GP-3001.SLDPRT, M21-GP-3002.SLDPRT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]
2021-10-06 Adding CAD files, organizing Work, Documenting
    [BasketForDiagram.SLDPRT, ESP8266.SLDPRT, ElegooBoard_Medium.SLDPRT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]
2021-10-07 Basket Target debugging, some success
    [DCtoDC_Convertor_2Amp.SLDPRT, M21-GP-3002.SLDPRT, M21-HG-0001.SLDASM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]
2021-10-09 FIxing Doc, Fixing Intellasense, New Schematics
    [M21-GP-0003.SLDASM, M21-GP-7002.SLDPRT, M21-GP-7003.SLDPRT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]
2021-10-11 Motor, Hit Count, Neos working
2021-10-12 problems with quadrature interrupts
    [highgoal.ino]
2021-10-13 from lab
    [M21-SL-3004..SLDPRT]
2021-10-14 Basket almost working fully
    [M21-HG-0001.SLDASM]
2021-10-16 Power Supply Box Ready for 3D printing
    [AC_PowerSocketWithSwitchAndFuse.SLDPRT, AC_PowerSupply_Amazon_12v_5Amps.SLDPRT, Jack_5p5mm_2p5mm.SLDPRT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]
2021-10-16 V1 of python driver for basket target.
2021-10-18 Stuff to make Ring Lights for Camera
    [JST_XH_3Pin_Jack.SLDPRT, LED_Ring_16_Adafruit.SLDPRT, M21-GP-0005.SLDASM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]
2021-10-18 Layout of Main Score Board Done
2021-10-20 Power Supply Box, V2
    [M21-GP-0004.SLDASM, M21-GP-3008.SLDPRT, M21-GP-3009.SLDPRT]
2021-10-21 V3 of PCB working with Test Program
2021-10-22 Doc additions
    [M21-GP-0005.SLDASM, M21-GP-3011.SLDPRT]
2021-10-22 More work on slider testing
    [M21-SL-0002.SLDASM, M21-SL-3012.SLDPRT]
2021-10-27 New 3D parts for Moving Target
    [HeatSink_Digitkey.SLDPRT, JST_XH_4Pin_Jack.SLDPRT, JST_XH_6Pin_Jack.SLDPRT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]
2021-10-29 Moving Target Finshed, both firmware and hardware
    [M21-MT-0004.SLDASM, M21-MT-0006.SLDASM, M21-MT-3009.SLDPRT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]
2021-10-29 Minor Fixes in firmware
    [highgoal.ino]
2021-11-01 Work on Camera Ring
    [DCtoDC_Convertor_eBoot_Mini_MP1584EN_Amazon.SLDPRT, M21-GP-0005.SLDASM, M21-GP-0006.SLDASM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]

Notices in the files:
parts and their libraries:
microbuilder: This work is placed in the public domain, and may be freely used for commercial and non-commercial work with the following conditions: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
